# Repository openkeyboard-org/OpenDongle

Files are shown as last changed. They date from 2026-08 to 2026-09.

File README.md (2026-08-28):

# OpenDongle

OpenDongle is an open-source keyboard dongle project.

## Repository layout

- `firmware/` — firmware source and related software artifacts.
- `hardware/` — hardware design files and documentation.
- `tools/` — development and support tooling.

## Licensing

- Firmware and tools software: [Apache License 2.0](./firmware/LICENSE).
- Hardware designs: [CERN Open Hardware Licence Version 2 - Weakly Reciprocal](./hardware/LICENSE).
- Third-party firmware provenance is recorded in [firmware/NOTICE](./firmware/NOTICE),
  and the independently created antenna design's provenance is recorded in
  [hardware/NOTICE](./hardware/NOTICE).

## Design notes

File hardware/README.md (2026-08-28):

# OpenDongle Hardware

OpenDongle is a compact USB Type-A 2.4 GHz wireless receiver. This directory contains the KiCad hardware design files, project-local libraries, fabrication notes, and bill-of-materials information for each implementation.

## Implementations

| Implementation | MCU | Board size | Power | Status |
| --- | --- | --- | --- | --- |
| [CH570](CH570/) | WCH CH570Q (DFN-10) | 16.4 mm x 10.0 mm | VBUS direct to V5, internal regulator | Available |
| [CH592](CH592/) | WCH CH592D (QFN-20) | 16.35 mm x 9.90 mm | VBUS via XC6206 3.3 V LDO | Available |

Both implementations share the same concept: a PCB-edge USB Type-A connector,
an independently created 2.4 GHz PCB antenna informed by WCH's published
reference design for 0.8 mm FR-4, and a two-layer board small enough to sit
inside a standard nano-receiver shell. They differ in the MCU and therefore in
the power and decoupling arrangement.

Each implementation directory also commits its exported outputs under `fab/`: the schematic as PDF and the gerber/NC drill set. The KiCad sources are the design of record; each README gives the `kicad-cli` commands that regenerate the exports.

See each implementation's README for detailed electrical, fabrication, assembly, and licensing information.

## Shared fabrication constraints

Both boards use the same stackup and design rules, because the antenna is only tuned for this construction:

| Parameter | Requirement |
| --- | --- |
| Layer count | 2 copper layers |
| Finished thickness | 0.8 mm nominal (35 um + 0.73 mm core + 35 um) |
| Material | FR-4 |
| Copper | 1 oz / 35 um outer copper |
| Minimum finished drill | 0.20 mm |
| Minimum track / clearance used | 0.15 mm track, 0.127 mm clearance |

## Verifying a design

Both projects open with KiCad 10 or later and resolve every symbol and footprint from their own directory via `${KIPRJMOD}`, so nothing needs to be added to your global library tables.

You can check either board without opening the GUI:

```sh
kicad-cli sch erc --severity-all hardware/CH570/OpenDongle-CH570.kicad_sch
kicad-cli pcb drc --severity-all --schematic-parity hardware/CH570/OpenDongle-CH570.kicad_pcb
```

CH570 is clean. CH592 reports a single expected ERC warning, explained in its README.

## Inspiration

This hardware design was inspired by the [bplug-ch project](https://oshwhub.com/lightandelectricity/bplug-ch).

## License

The hardware designs are licensed under the CERN Open Hardware Licence Version
2 - Weakly Reciprocal. See [LICENSE](LICENSE). Design provenance, including the
independently created antenna implementation, is recorded in [NOTICE](NOTICE).

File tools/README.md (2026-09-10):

# opendongle (Rust)

Cross-platform USB-HID maintenance tool for OpenDongle dongles (WCH CH570 /
CH592F). Runs on **Linux, Windows, and macOS**, and builds to a single
executable with no runtime data files.

On Linux that executable is not fully static: `hidapi` uses the hidraw backend,
so the binary links `libudev.so.1` at run time (`ldd` will show it). Any
mainstream distribution already provides it — `libudev1` on Debian and Ubuntu,
`systemd-libs` on Fedora — but a minimal container image may not.

It reads device, firmware, bond and fault information over the dongle's vendor
HID interface, and hands the device off to the
[OpenBoot](../third_party/openboot) bootloader when you want to update it.
**It does not flash firmware itself** — updates happen inside the bootloader
over OBP, driven by the `openboot` CLI that ships with that submodule. See
[`firmware/BOOT.md`](../firmware/BOOT.md) for the boot architecture and the full
update, factory and recovery flows.

## Why hidapi

The dongle's vendor channel is a HID-class interface. `hidapi` rides each OS's
native HID stack (hidraw on Linux, `hid.dll` on Windows, IOKit on macOS), so the
interface opens on all three with no driver replacement — unlike a raw-USB
approach (libusb/nusb), which would need Zadig/WinUSB on Windows and is
impractical for a HID interface on macOS.

## Build

```bash
cargo build --release
# binary: target/release/opendongle
```

Dependencies (`hidapi`, `clap`, `anyhow`, `crc32fast`) are pulled by Cargo.

- **Linux:** the hidapi hidraw backend links `libudev`. Install the dev package
  (Debian/Ubuntu: `sudo apt install libudev-dev`). If `pkg-config` can't find it
  (e.g. a linuxbrew `pkg-config` shadows the system one), point it at the system
  dir: `PKG_CONFIG_PATH=/usr/lib/x86_64-linux-gnu/pkgconfig cargo build`.
- **Windows / macOS:** no extra system packages.

## Usage

Safe by default: with no action it displays read-only status.

```bash
opendongle                                     # same full status as --info
opendongle --info                              # device, build, update, link, bond, health
opendongle --fault                             # retained fault page only; arms/disarms nothing
opendongle --status --samples 50 --period-ms 200  # unarmed link-state sampler
opendongle --enter-bootloader --image app.bin  # family-checked, then reboots into OpenBoot
opendongle --enter-bootloader --force          # reboot with no family guard

# then, with the device enumerated as OpenBoot. The bootloader shares the
# application's VID:PID, so the openboot CLI needs both flags — its own
# defaults (1209:0001) are the generic/bench identity, not this product's.
# It tells the two modes apart by HID usage page 0xFF00 usage 0x01, which the
# application's interfaces (0xFFFF, 0xFF60) deliberately avoid.
openboot --vid 0x0C45 --pid 0xFEFE flash --force app.bin
```

**Attach one dongle at a time.** Neither this tool nor the `openboot` CLI can
pin a *physical* device across the re-enumeration into the bootloader: both
select by VID:PID (plus HID usage page), and `--serial` selects by ROM UID,
which the application and the bootloader do not present identically. With two
dongles attached, a flash could therefore target the wrong one.

`--enter-bootloader` narrows the window but does not close it. It records which
OpenBoot devices were already present before the reboot, and reports success
only when the application interface it addressed has **left** the bus *and*
exactly **one previously-absent** bootloader has appeared. It exits 2, with an
explanation, if the addressed application never left, if more than one new
bootloader appears, or — after warning — when bootloaders were already present.

If another bootloader is already on the bus it refuses **before** rebooting
anything, leaving the dongle running.

**The flash itself cannot be aimed at the wrong device**, which is worth stating
because it is easy to assume otherwise. `openboot` is not told which hidraw path
was identified — it selects by VID:PID — but it narrows by HID usage page first,
so a sibling running its *application* is filtered out, and it then refuses
outright when more than one bootloader interface matches. The failure mode with
several dongles attached is a clear error, not a misdirected write. These checks
exist so that error arrives before a working dongle has been rebooted for
nothing, not because the write is unsafe.

`--image` is the safety interlock: the image's ODG2 family is compared against
the connected device's reported family **before** the reboot, while the
application is still the thing answering, so a CH570 image cannot be sent toward
a CH592 or vice versa. It also refuses a *factory* image with a pointed error —
those are written at address 0 with a debug probe, not over USB. `--force` skips
the guard when you have no image at hand; note the flash itself is unguarded
either way, because OpenBoot's COMMIT attests only length and CRC.

Flags: `--vid` / `--pid` (accept `0x..`/decimal), `--interface`, `--hidraw`
(alias `--path`, explicit device path), `--info`, `--fault`, `--status`, `--diag`, `--rf-poke`
(`--samples N`, `--period-ms MS`), `--enter-bootloader`, `--image FILE`,
`--force`.

`--diag` reads the RF diagnostics pages (command 0x92, up to eight 62-byte
pages: 0-3 required of any firmware that answers the command, 4 present on the
current firmware of both chips but skipped if an earlier firmware answers it
with an empty payload, plus the CH592 power pages 5 "power" and 6 "power
detail" that exist only on a `PM_IDLE=1` build and are skipped the same way;
provided by firmware carrying the RF diagnostics page -- a separate draft PR;
firmware without it answers nothing and the tool reports a timeout;
firmware `RF_DiagFill` in `firmware/common/src/rf_task.c`) with unarmed
exchanges only: the runtime snapshot (state, channel, the access address in
RAM vs the one the radio was last armed with, the last RX/TX/shut status, an
`rx_armed` latch, peer MAC, last LEN-10 disposition, last persist outcome), the
PHY and executor counters (RX arm attempts and failures, RX done/CRC/timeout,
TX start/fail/done, the pending event mask, both delayed-post slots, the
timer slots' remaining times) and the protocol counters (beacons seen and
accepted or rejected with the reason, pair-ACK scheduled/started/finished,
EV10 entries and give-ups, promotes, persist attempts). Counters wrap; with
`--samples N --period-ms T` every counter that changed between samples is
printed as a per-second rate, which is how a healthy reconnect camp reads
(RX re-armed ~33/s on its 30 ms timeout) and how a deaf one is told apart
(no RX events, or a non-zero arm status, or a radio address that is not the
bond's). Every page ends with its raw bytes. CH592 firmware answers the page
with zeros for the CH570-only fields.

On a `PM_IDLE=1` CH592 build each sample after the first also prints two
derived figures. `idle_duty` is page 5 `idle_tsys` (60 MHz SysTick ticks spent
in WFE) over the `hal_now` ticks that elapsed; both are 32-bit and wrap every
71.6 s, and a wrapped numerator cannot be recovered from host time, so the duty
is exact for `--period-ms` under 60000 and prints `n/a` beyond that rather
than a silently low figure. `radio_wake_ratio` is
`wake_both / (wake_radio + wake_both)`: the firmware snapshots what is pending
right after the WFE, before any ISR runs, and `wake_radio` counts exits where a
radio IRQ was the ONLY source pending (proof that the radio ended the WFE)
while `wake_both` counts exits where another source was pending too, which the
counters cannot order (a radio IRQ that never woke the core and waited for the
next TMR3/TMR0/USB looks the same as a radio wake with a heartbeat landing in
the read window). The ratio is a co-pending frequency, not a wake-failure
rate; the radio-wake proof is the protocol around it: a keyboard-absent
negative control must read `wake_radio == wake_both == 0`, then every
reconnect/pair must advance `wake_radio`, and a radio that never ends the WFE
shows as `wake_both` advancing with `wake_radio` flat. In the exact-deadline heartbeat
mode (page 5 flag `exact_deadline`, whose `deadline_cap_us` replaces `heartbeat_us`)
page 6 also carries `hb_arm_deadline` / `hb_arm_cap`, how many sleeps armed TMR3 to an
application timer's deadline versus to the cap; `hb_irqs` then runs at tens a second
rather than a thousand when no application deadline is nearer than the cap (a nearer
deadline arms the timer sooner, and on a live link TMR0 wakes the core before it
fires). The page 6 remote-wake
arm count is 16 bits on both sides and its rate wraps accordingly.

Page 7 `rx window` (CH592 built with `PM_IDLE=1` and `PM_RX_WINDOW=1`, the Tier 2 windowed
receiver; the page count rises to 8 only with both) counts the
receiver windows the reacquire scan and the terminal camp open instead of keeping RX on:
`win_opens` / `win_closes` (a close is a window that ended with nothing accepted; whether
a window is in flight is the `open` flag, not an arithmetic on the counters, since a phase
open replaces a pending ordinary window and a teardown discards one), `win_catches` (a
beacon accepted inside a window, counted at acceptance before the ACK's own outcome), `win_phase_opens` / `win_phase_misses` (the once-per-second window
phase-locked to a resting production keyboard's probe, and how often it caught nothing; a
miss widens the next one and two in a row fall back to the continuous scan until the next
promote), `win_locks` / `win_unlocks` (the scheduled-drop detector locking on two
consecutive drops ~1 s apart after a short confirmed link, and letting go on anything
else) and `win_engages` (windowing starting once the grace period ran out). The detector
line shows the live state: `link_rx` (answered polls on the current link while connected,
saturating at 65535; the last link's count otherwise), `phase_ms` (the
current phase window width), `grace_ms` (continuous receiver remaining before windowing
engages), `misses`, `faults` (rung 3 injections inside a window) and the mode/open/
phase_open/locked flags; the rates line carries the eight 32-bit counters only, and page 7
prints no raw-byte line. Against a resting production keyboard, once the grace period has
run out and the detector has locked, the healthy reading is one phase open and one catch
per second with `win_phase_misses` flat.

Exit codes:

| Code | Meaning |
|---|---|
| `0` | ok |
| `1` | device/permission/runtime error, or a refused request |
| `2` | the handoff could not be pinned to one device. Either OpenBoot never appeared within 10 s, or the addressed application never left the bus, or more than one new bootloader appeared, or another bootloader was already present when the command started |
| `3` | `--image` was given while only the OpenBoot bootloader is on the bus, so the image's ODG2 family could **not** be checked against the device. The guard lives in the application, which is not present. Pass `--force` to proceed anyway, and note the output says plainly that the family was not verified |

`--fault` issues only the unarmed FaultRead (0x93) and decodes the 40-byte
fault page. The CH570 page v5 and the CH592 page v1 share one layout, and both
are recognised; any other (family, page version) pair is printed as a warning
plus the raw bytes, with no fields decoded. For a **valid** record every field
is shown: startup reset cause and the record's own, the startup phase marker,
the reset-keeper state live and as recorded, kind, action, flags, all four
counters and the trap registers. For an **invalid** record the firmware
populates only the family, page version, valid flag, live keeper, startup
marker and startup reset status; the record-derived fields are zero fill and
are reported as `unavailable` rather than decoded. The raw 40 bytes are always
the last line. Use `--fault` first on a misbehaving unit: it does not arm or
disarm a session (a session left armed by an interrupted earlier run stays
exactly as it was), so it perturbs the device less than `--info`.

`--status` issues a single unarmed Status (0x91) exchange per sample and prints
one line each with a timestamp, the connection state and the last RSSI. With
`--samples N` and `--period-ms MS` it repeats, which is how to watch a link
flicker between *waiting for reconnect* and *connected* without a maintenance
session ever being armed. Note the CH570 SKU is reported to return a constant
RSSI, so treat that column as a hint on that part.

`--rf-poke RUNG` is the one diagnostic that changes device state. It arms a
maintenance session (like the bond commands), sends IAP `0x94` with the rung,
and always disarms. Rung `1` re-arms the receiver from task context; rung `2`
shuts the radio, re-runs the vendor init and re-arms (CH570 only: CH592 answers
"unsupported" for it, a second vendor role init is not validated on the TMOS
radio); rung `3` shuts the radio and leaves it deaf, the fault injection for the
terminal camp's liveness watchdog, which re-arms it at its next 200 ms tick on
both chips (rung 3 resets the tick's baseline; page 1 `camp_wd_rearms` advances
by one; on CH570 the escalation to a vendor re-init needs a second silent tick).
With the CH592 receiver windowed (page 7 `mode` true) rung 3 instead marks the NEXT
window: it arms and is shut at once, so the injection lands inside a listening window
rather than on a radio that was off anyway; reception is restored in the window after the
injected one, up to about two periods from the command (page 7 `faults` advances by one),
and the link itself still needs the peer's next beacon.
Rungs `40` to `59` are the opposite kind of injection: on a live link they mask
every interrupt for a nominal `rung - 40` poll slots of 875 µs, so the polls
coalesce into one gap of about that many intervals; a nominal gap of 5 or 10
slots is the regression check for the hop repeat-correction fix (the link must
survive it). Rungs `60` to `69` add `3 * (rung - 60)` ticks of 31.25 µs to a
5-slot gap and `70` to `79` to a 6-slot gap, sweeping the remainder within the
slot. Every figure is the requested duration: the mask starts whenever the
command is dispatched, at an arbitrary phase within the current slot, so the
gap the link actually sees is the requested length plus that phase, and the
remainder rungs sweep the remainder in aggregate over repeats, not per call. The firmware
refuses rungs 1 to 3 unless the dongle is in its exact terminal reconnect camp
-- not connected, no EV10 reacquire scan, no boot window or relisten, no
pair-ACK burst in flight -- refuses rungs 40 to 79 unless a link is up, and
refuses them all while quiescing for a reboot. Exit status is non-zero on any refusal, and the reply names the
reason. Use it on a dongle that is deaf to its
keyboard, rung 1 first: which rung restores the link says whether the software
re-arm loop or the PHY was dead.

The build id `--info` prints is the one to check against the tree that built
the image: `make -C firmware ch592-print-build-id MRS_TOOLCHAIN=... <the same
knobs>` (or `ch570-print-build-id`) prints exactly the id that command line
builds, and `firmware/<chip>/build/<profile>/.build-id-stamp` holds the id the
last build actually compiled in. All three must agree; a mismatch means the
flashed image is not the configuration you think it is.

`--info` reports an absent or invalid bond record as information rather than an
error, and shows a best-effort split of the invalid record's fields (magic,
format, flags, interval, session AA, timeout, both MACs, stored vs computed
checksum) alongside the raw bytes. An all-zero bond record **may** indicate a
failed NV read - the firmware zero-initialises the reply and `bond_load` returns
without filling it on an NV error - but a record that genuinely is, or was
corrupted to, all zeros looks identical, so the tool says "may indicate" and no
more.

With `--hidraw`, `--fault` and `--status` first confirm from HID enumeration
alone that the named path carries the `--vid`/`--pid`/`--interface` selectors,
and refuse to send anything if it does not: an explicit path bypasses discovery,
so nothing else would stop a vendor report going to an unrelated HID node.

On Linux, opening the device needs hidraw permissions (run as root or use a
`plugdev`/udev rule).

## Tests

```bash
cargo test
```

60 tests, no hardware required: Intel-HEX parsing including checksum rejection,
ODG2 header integrity, the device-family binding, wrong-load-base and
factory-image rejection, bond-record and fault-record decoding and the exact
text each renders (valid, invalid/best-effort, unknown layout), status parsing
with legacy fallback, IAP packet golden vectors and transport CRC-32, the
`--hidraw` identity check, the `int(s,0)`-style number parser, and the CLI
contract.

## macOS caveat

This is a 5-interface composite HID device and the vendor channel is interface
4. On Linux/Windows hidapi reports the interface number reliably; on macOS it
can be `-1` for composite devices, in which case interface matching needs a
usage-page fallback. Verify on macOS hardware before relying on it.

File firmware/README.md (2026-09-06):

# OpenDongle production firmware

This directory builds the two supported production images:

- `make ch570` builds the CH570D RF + USB HID + IAP image.
- `make ch592` builds the CH592F RF + USB HID + IAP image.
- `make ch570-openboot` or `make ch592-openboot` builds only the OpenBoot
  bootloader from the pinned submodule (product board files).
- `make ch570-factory` / `make ch592-factory` build one raw factory image:
  OpenBoot at flash address `0x0000`, `0x00` pad to `0x2000`, then the
  finalized application at `0x2000`.
- `make` or `make all` builds both images.
- `make check-deps` verifies the pinned SDKs and toolchain; `make test` runs the
  host unit tests (no toolchain, no hardware); `make clean` removes build output.

The dongle boots via the OpenBoot bootloader (`third_party/openboot`,
pinned submodule) and updates in-bootloader over its OBP USB protocol. See
[BOOT.md](BOOT.md) for the flash maps, boot-record semantics, and the
update/factory/recovery flows; OpenBoot's own design and wire protocol are
documented in the submodule.

## CH570D factory flashing

The single image produced by `make ch570-factory` is:

```text
ch570/build/ch570-product/opendongle-ch570-product-factory.bin
```

It is a raw code-flash image based at address zero. To build and program it
through the debug pin with a WCH-LinkE and `minichlink`, run:

```sh
make ch570-factory-flash \
  MINICHLINK=/path/to/minichlink \
  WCHLINK_SERIAL=probe-serial
```

`WCHLINK_SERIAL` is **required**: the target refuses to guess which probe to
drive, because a whole-chip erase aimed at the wrong target is unrecoverable and
a multi-probe bench may carry boards that must never be written. **Use the make target rather than raw `minichlink` calls.** minichlink ignores
the return values of its CH5xx erase and write calls and its byte-for-byte
verify is disabled, so a zero exit status alone does not prove the image
landed. The target exists because it does the two things a hand-typed sequence
does not: it selects the probe explicitly, and it reads the image back and
byte-compares it before reporting success.

What it does, and why each step matters:

1. `-kt` turns off the WCH-LinkE target supply.
2. `-E` erases the entire user code flash. **The erase is required, not
   optional.** It clears the bond page (`0x3A000`) so a unit cannot inherit a
   test fixture's pairing identity. It also clears both slots' boot records,
   which now live inside the slots (`0x1D000` and `0x39000` on CH570) rather
   than on a reserved page — but that no longer decides where the first boot
   lands, because the factory image carries slot A's record and restores it.
3. The factory image is written at address 0, read back, and compared.
4. On CH592 only, the recipe additionally refuses to finish if a bond record
   survived in DataFlash, which `-E` cannot reach (`ALLOW_BONDED_FLASH=1`
   overrides this for a development unit).

No bless step is needed, or possible: the factory image carries slot A's boot
record, so the unit boots the application on first power-on (see BOOT.md).
The recipe ends with a real power cycle rather than `minichlink -b`, so what it
leaves behind is a unit that has actually demonstrated that.

For a target placed in the WCH ROM USB bootloader instead of using the debug
pin, the same raw image can be programmed with:

```sh
wchisp erase
wchisp flash \
  ch570/build/ch570-product/opendongle-ch570-product-factory.bin
```

The explicit `wchisp erase` matters for the same reason it does above:
`wchisp flash` erases only enough sectors to hold the image, so it would leave
the old boot-record page behind. Erasing makes the post-flash state
deterministic instead of dependent on whatever the unit held before.

Be precise about what a surviving record does and does not guarantee. It stores
a length and a CRC-32, and the bootloader recomputes that CRC over exactly that
many bytes from the app base — so it validates any image whose first `img_len`
bytes match the recorded ones, which in practice means re-flashing the same
build. It is not a whole-image identity check, and it does not by itself
guarantee the unit cannot launch an image other than the recorded one. Anything
that does not match that prefix fails the check and the unit stays in the
bootloader. `BOOT.md` states the rule in full.

The factory target enforces two invariants before exposing the image: the
application fits its chip's `APP_MAX_BYTES` window (`size-check`), and the
OpenBoot binary fits `[0, 0x2000)` so the application lands at exactly the
address it links at (`compose_factory.py`). The application's own ODG2 header is
written earlier, by `finalize_image.py` during the app build.

Two independent checksums are in play, and it is worth not confusing them.
`finalize_image.py` stamps a CRC inside the ODG2 header; that is a host-side
identity check, used by `opendongle` and by the build. OpenBoot never parses
ODG2. What it verifies at every boot is its own `img_crc32`, computed over the
committed bytes at COMMIT time and stored in that slot's `OBR2` boot record. A
raw OBP client can therefore bless and boot an image whose ODG2 CRC is invalid —
consistent with wrong-family protection also being host-side only (see
`BOOT.md`).

## Dependencies

The OpenWCH CH570/CH572 and CH592 SDKs are pinned Git submodules. Initialize
them once from the repository root:

```sh
git submodule update --init --recursive
```

MounRiver Studio's GCC 15.2 toolchain is an external dependency. It is not
redistributed or made a submodule because its packaging and licence are
independent of the OpenWCH SDK repositories. Set `MRS_TOOLCHAIN` to the
directory containing `riscv32-wch-elf-gcc`, `riscv32-wch-elf-objcopy`,
`riscv32-wch-elf-size`, and `riscv32-wch-elf-nm`.

**Two toolchains are required.** The default goal composes the factory image,
which builds OpenBoot — and OpenBoot is a pinned submodule still on GCC 12. So
a working build names both:

```sh
make MRS_TOOLCHAIN=/path/to/MounRiver_Studio/toolchain/RISC-V_Embedded_GCC15/bin \
     OPENBOOT_TOOLCHAIN=/path/to/MounRiver_Studio/toolchain/RISC-V_Embedded_GCC12/bin
```

`OPENBOOT_TOOLCHAIN` defaults to `MRS_TOOLCHAIN`, and omitting it now fails in
**our** `check-openboot-toolchain`, not OpenBoot's. Upstream's compiler check
went advisory at this pin — a hash mismatch and an unvalidated GCC major both
warn and continue — and it auto-detects either tool prefix, so a factory build
carrying one GCC 15 toolchain would otherwise silently ship a GCC 15
bootloader. If you only want the application binaries and no bootloader, the
per-chip `.elf`/`.bin` targets need `MRS_TOOLCHAIN` alone.

**The split is permanent**, not a wait for OpenBoot's pin to catch up: GCC 15
is explicitly unvalidated on ch57x. Upstream benched a CH572 where it fired the
idle auto-boot at 1.51/1.71/4.75 s against a configured 10 s and failed to
return from 4 of 32 software resets (GCC 12: 0/32), with the generated code for
the timing functions instruction-identical. Cause unresolved.
`OPENBOOT_ALLOW_UNVALIDATED_GCC=1` overrides the gate for anyone reproducing
that investigation.

**Note the tool prefix changed with this release.** GCC 12 shipped
`riscv-wch-elf-*`; GCC 15 ships `riscv32-wch-elf-*`. Pointing `MRS_TOOLCHAIN` at
a GCC 12 directory now fails in `check-deps` with "MounRiver tool is missing or
not executable", which is the intended behaviour rather than a broken build
part-way through. The prefix lives in the `CROSS` variable in each application
Makefile and in `firmware/Makefile`, and `check_dependencies.py` validates the
same prefix it is given, so overriding `CROSS` also moves what gets validated.

OpenBoot is the exception and still needs GCC 12 — see the `OPENBOOT_TOOLCHAIN`
note above.

`MRS_TOOLCHAIN`, `OPENWCH_ROOT`, `CH570_SDK`, and `CH592_SDK` use Make's `?=`
assignment, so they may be supplied by the environment, command line, or a
developer-local make wrapper. `make check-deps` verifies the SDK revisions,
clean SDK worktrees, the compiler's GCC major, its support for WCH's
fast-interrupt ABI, and the required tools before compilation.

### The compiler gate: properties, not bytes

`check_dependencies.py` is an order-only prerequisite of every object file, so
it is not advisory: a failure stops the build. It gates on three properties of
the compiler the build will actually use (the `CROSS` prefix under
`MRS_TOOLCHAIN`):

- the tools exist (`gcc`, `objcopy`, `size`, `nm`);
- the driver reports the required GCC **major** (15 for the application;
  OpenBoot keeps its own GCC 12 gate, see `OPENBOOT_TOOLCHAIN` above);
- the driver **implements `__attribute__((interrupt("WCH-Interrupt-fast")))`**,
  checked on the generated code rather than on the spelling: a fast handler lets
  the hardware preserve `ra`/`t0`/`a0` and spills only the callee-saved `s0`
  before `mret`, the ordinary `interrupt` ABI spills all four, and the probe
  compiles both and refuses a compiler that emits the ordinary shape for the
  fast attribute or the same shape for both. Each chip Makefile passes its own
  `$(ARCH)` as the probe target (`--probe-flags`), and the top-level
  `make check-deps` delegates to the chip Makefiles so it probes the same way;
  a bare invocation of the script without `--probe-flags` probes a generic
  `rv32imac`. That is the property the firmware depends on: the CH59x BLE library is
  compiled against WCH's fast-interrupt ABI, mainline GCC and clang reject the
  argument outright, and a plain-interrupt build wedges before any IRQ is
  delivered.

The compiler's identity is still part of the build id. Each chip Makefile folds
the driver's first `--version` line (name, WCH build tag, version, e.g.
`riscv32-wch-elf-gcc (g5115c7e44-dirty) 15.2.0`) into `CONFIG_TEXT` as the
`compiler=` token (a sanitised readable prefix plus 16 hex digits of the line's
SHA-256, so two compiler builds whose tags sanitise alike still get different
ids) and the driver's own SHA-256 as `compiler_sha256=`, so a driver whose bytes
changed under an unchanged banner also moves the id and recompiles every object.
A compiler that prints no identity fails any goal that compiles the application
at Makefile parse time, rather than producing an id; `clean`, the OpenBoot-only
targets and `check-deps` are exempt from that parse-time guard so they can run
on a checkout without an application compiler (`check-deps` itself then reports
the missing or wrong toolchain, which is its job). `check-deps` prints the driver's SHA-256 for the build log, and
the factory rule appends `app_compiler`, `app_compiler_id`,
`app_compiler_sha256` and `app_build_id` to the factory manifest, which is where
the strict mode's digest comes from.

What the id therefore means: **same source, same configuration, same compiler
identity line and driver bytes.** It does not by itself promise byte-identical
binaries across hosts; two installs with the same driver that differ in `cc1`,
the assembler or the linker would share an id. Anyone who needs that stronger
promise passes `--expect-compiler-sha256 <digest>` (the `app_compiler_sha256`
line of a release's factory manifest) to `check_dependencies.py`, which turns
the digest back into a hard gate for that build. Even then it is driver
verification, not a byte-reproducibility guarantee: `cc1`, the assembler, the
linker and `objcopy` are not covered.

History: until this change the gate was an exact SHA-256 of the gcc driver,
which blocked every host whose MounRiver drop differed from the one that
recorded the pin, even at the same 15.2.0 version, and forced a local override
that could never be committed.

## Verifying a build

The build is reproducible: `build_identity.py` hashes the sources, the linker
script, the compiler and linker flag sets, the pinned SDK revision and the
compiler's identity into a 32-bit build id that is compiled into the image and reported by
the host tool (`opendongle --info`). Two builds of the same tree on the same
host produce byte-identical artifacts, so a rebuild-and-compare is a meaningful
check:

```sh
make ch592 MRS_TOOLCHAIN=...
sha256sum ch592/build/ch592-product/opendongle-ch592-product.bin
make clean && make ch592 MRS_TOOLCHAIN=...
sha256sum ch592/build/ch592-product/opendongle-ch592-product.bin   # identical
```

**What that check does and does not establish.** It compares the *application*
image, and it is only as strong as the inputs the build id actually covers. Two
gaps are worth stating rather than leaving implied, both documented above and in
`TODO.md`:

- The compiler gate checks the `riscv32-wch-elf-gcc` driver's properties; the
  driver's identity line and digest are folded into the build id and recorded
  in the factory manifest, never gated by default, and even the strict
  `--expect-compiler-sha256` mode verifies the driver alone, not `cc1`, the
  assembler, the linker or `objcopy`. A partially replaced toolchain directory
  can therefore produce different bytes under the same build id, so "the same
  toolchain" means the whole directory unchanged, not merely a matching
  identity line or driver digest.
- **OpenBoot still builds with GCC12.** The pinned submodule carries its own
  toolchain pin, still on MounRiver GCC12 and its `riscv-wch-elf-*` tool names,
  so a factory build needs both toolchains present:

  ```sh
  make ch570-factory MRS_TOOLCHAIN=<GCC15 bin> OPENBOOT_TOOLCHAIN=<GCC12 bin>
  ```

  This is safe rather than merely tolerated: the factory image is
  OpenBoot ‖ pad ‖ application, two separately linked binaries that share no
  code, so the compilers never have to agree. `OPENBOOT_TOOLCHAIN` defaults to
  `MRS_TOOLCHAIN`, and a factory build with it pointed at anything but GCC 12
  is refused by `check-openboot-toolchain`. The split is permanent, not a wait
  for OpenBoot's pin to move.
- The OpenBoot **revision** is in `CONFIG_TEXT`, and `check-deps` asserts the
  checkout matches it and is clean (`--expect-revision`). The bootloader
  **binary** is still not hashed into `BUILD_ID_INPUTS`, deliberately: the
  manifest does not exist at parse time on a clean checkout, and its digest
  depends on which GCC 12 install built OpenBoot, which would make
  `DONGLE_BUILD_ID` differ between developers for byte-identical application
  images.
- So the two identities are separate on purpose: `DONGLE_BUILD_ID` identifies
  the **application**, and the `.manifest` copied beside each factory image
  (`openboot_revision`, `openboot_dirty`, `image_sha256`) identifies the
  **bootloader artifact**. Comparing factory images across hosts means
  comparing both.

So: same tree, same complete toolchain, same OpenBoot checkout → identical
artifacts. A matching build id alone does not imply a matching factory image;
the manifest is what closes that gap.

`make clean` removes generated output for both production targets.

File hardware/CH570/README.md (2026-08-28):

# OpenDongle CH570

OpenDongle CH570 is a compact USB Type-A 2.4 GHz receiver built around the WCH CH570Q RISC-V wireless MCU. The PCB is 16.4 mm x 10.0 mm and uses a PCB-edge USB connector and an independently created, WCH-informed 2.4 GHz PCB antenna.

## Design files

| File or directory | Purpose |
| --- | --- |
| `OpenDongle-CH570.kicad_pro` | KiCad 10 project and design-rule settings |
| `OpenDongle-CH570.kicad_sch` | Schematic |
| `OpenDongle-CH570.kicad_pcb` | PCB layout |
| `lib/OpenDongle.kicad_sym` | Project-owned CH570Q and four-pin PCB USB symbols |
| `lib/OpenDongle.pretty/` | Project-owned USB edge connector and independently created, WCH-informed antenna footprints |
| `sym-lib-table`, `fp-lib-table` | Portable project-local library configuration |
| `fab/` | Exported outputs: schematic PDF and gerber/NC drill set (see [Fabrication outputs](#fabrication-outputs)) |

Open the project with KiCad 10 or later. The library tables use `${KIPRJMOD}` paths, so the project resolves every symbol and footprint from this directory and does not depend on global KiCad configuration. Nothing needs to be added to your global symbol or footprint library tables.

## Electrical design notes

- USB VBUS supplies the CH570Q V5 pin (pin 2) directly. There is no external regulator; the CH570 regulates 3.3 V internally.
- R1 is the 1.5 kOhm connection required by WCH between V5 and the internally regulated VDD33/VIO33 rail (pin 1) for direct 5 V operation.
- Both V5 and VDD33/VIO33 have 2.2 uF bulk and 100 nF high-frequency decoupling: C1/C2 on V5, C3/C4 on VDD33.
- Y1 is a 32 MHz, 8 pF-load crystal on XI/XO (pins 9 and 8). The CH570 provides programmable internal crystal load capacitance, so external load capacitors are not fitted.
- The RF output (ANT, pin 10) connects directly to the independently created, WCH-informed PCB antenna, as recommended by the CH570 datasheet.
- USB data connects to the CH570Q native USB pins: D+ to PA1/UDP (pin 4) and D- to PA0/UDM (pin 3).
- GND reaches the CH570Q through the exposed pad (pin 11).
- The three unused GPIOs (pins 5, 6, 7) carry no-connect flags.
- AE2 and J1 represent copper footprints fabricated as part of the PCB. They are excluded from the assembly BOM and position file at both the symbol level (`in_bom no`, `in_pos_files no`) and the footprint level (`exclude_from_bom`, `exclude_from_pos_files`), so they do not appear in the Fabrication Toolkit output as unsourceable line items.

See the [WCH CH572/CH570 datasheet](https://www.wch-ic.com/downloads/CH572DS1_PDF.html) for the power, oscillator, RF, USB, and package requirements.

## Design verification

This design passes both checks cleanly with KiCad 10:

```sh
kicad-cli sch erc --severity-all OpenDongle-CH570.kicad_sch     # 0 errors, 0 warnings
kicad-cli pcb drc --severity-all --schematic-parity OpenDongle-CH570.kicad_pcb   # 0 violations, 0 parity issues
```

## Fabrication outputs

`fab/` holds the exported outputs: the schematic as PDF, and the gerber/NC
drill set under `fab/gerbers/`. The KiCad sources remain the design of
record — regenerate the exports with KiCad 10 whenever the schematic or
layout changes:

```sh
kicad-cli sch export pdf -o fab/OpenDongle-CH570-schematic.pdf OpenDongle-CH570.kicad_sch
kicad-cli pcb export gerbers -o fab/gerbers/ \
    -l F.Cu,B.Cu,F.Paste,B.Paste,F.Silkscreen,B.Silkscreen,F.Mask,B.Mask,Edge.Cuts \
    --no-protel-ext --check-zones OpenDongle-CH570.kicad_pcb
kicad-cli pcb export drill -o fab/gerbers/ --excellon-separate-th \
    --generate-map --map-format gerberx2 OpenDongle-CH570.kicad_pcb
```

Anyone ordering from these files must still pass the stackup and antenna
requirements below to the fabricator; the gerbers alone do not carry them.
(JLC-oriented assembly outputs from the Fabrication Toolkit plugin go to
`production/`, which stays untracked.)

## Fabrication requirements

The antenna geometry and USB connector make the board construction part of the electrical and mechanical design. Use these settings unless a revised PCB has been validated:

| Parameter | Requirement |
| --- | --- |
| Layer count | 2 copper layers |
| Finished board size | 16.4 mm x 10.0 mm |
| Finished thickness | 0.8 mm nominal (35 um + 0.73 mm core + 35 um) |
| Material | FR-4 |
| Copper | 1 oz / 35 um outer copper |
| Surface finish | ENIG recommended; hard gold on the USB contacts is preferred for high insertion-cycle production |
| Minimum finished drill | 0.20 mm |
| Minimum track/space used | 0.15 mm track, 0.127 mm design-rule clearance minimum |
| Soldermask | Both sides; no soldermask over the USB contacts or antenna conductor |

Additional requirements and checks:

1. Preserve the antenna copper, ground keepout, board thickness, and via fence exactly. The antenna is designed for 0.8 mm FR-4; a different thickness detunes it. Do not allow the fabricator to add serial numbers, tooling features, or anything else in the antenna region.
2. Keep the board outline and USB contact geometry at 1:1 scale. If an edge bevel is requested, confirm that the fabricator supports it on a 0.8 mm board without shortening or damaging the USB contacts.
3. Verify the board USB contact fits in several Type-A receptacles before a production run.
4. The enclosure and carrier must not place metal or conductive material over the antenna region.

## USB receiver shell

This [USB receiver shell](https://item.taobao.com/item.htm?id=1042083494471) has been verified to fit and work well with the PCB. Other shells designed for the same PCB dimensions and specification should also work, but their fit has not been verified.

## Suggested BOM

The listed LCSC/JLCPCB numbers are suggested assembly parts, not sole-source requirements. Substitutes should match the value, package, dielectric/tolerance, voltage rating, and crystal parameters.

| References | Qty | Value / part | Package | Suggested LCSC part | Notes |
| --- | ---: | --- | --- | --- | --- |
| U1 | 1 | WCH CH570Q | DFN-10, 3 mm x 3 mm, exposed pad | C49260680 | Confirm pin-1 orientation and exposed-pad soldering |
| Y1 | 1 | 32 MHz crystal | 2016, 4 pad | C37635332 | 8 pF load, +/-10 ppm tolerance, 40 ohm maximum ESR |
| R1 | 1 | 1.5 kOhm, 1% | 0603 | C22843 | Required V5-to-VDD33 connection |
| C1, C3 | 2 | 2.2 uF | 0603 | C23630 | X5R or better, 10 V minimum; suggested part is 16 V |
| C2, C4 | 2 | 100 nF | 0603 | C14663 | X7R or better, 10 V minimum |

AE2 (PCB antenna) and J1 (PCB USB connector) are fabricated as PCB copper and are not assembly parts.

## Source attribution

- The 0.8 mm FR-4 antenna was independently created, informed by the WCH reference antenna published in the [openwch schematic/PCB library](https://github.com/openwch/schpcb_lib); no WCH CAD or artwork file was copied, imported, converted, or traced.
- The PCB USB connector footprint is derived from the [USB armory](https://github.com/usbarmory/usbarmory) hardware design.

## License

This hardware design, including the independently created antenna
implementation described in [`../NOTICE`](../NOTICE), is licensed under the
CERN Open Hardware Licence Version 2 - Weakly Reciprocal. See
[`LICENSE`](LICENSE).

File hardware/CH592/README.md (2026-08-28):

# OpenDongle CH592

OpenDongle CH592 is a compact USB Type-A 2.4 GHz receiver built around the WCH CH592D RISC-V wireless MCU. The PCB is 16.35 mm x 9.90 mm and uses a PCB-edge USB connector and an independently created, WCH-informed 2.4 GHz PCB antenna.

Unlike the [CH570](../CH570/) implementation, which runs the MCU straight from VBUS on its internal regulator, the CH592 is powered from a 3.3 V LDO.

## Design files

| File or directory | Purpose |
| --- | --- |
| `OpenDongle-CH592.kicad_pro` | KiCad 10 project and design-rule settings |
| `OpenDongle-CH592.kicad_sch` | Schematic |
| `OpenDongle-CH592.kicad_pcb` | PCB layout |
| `lib/OpenDongle.kicad_sym` | Project-owned CH592D and four-pin PCB USB symbols |
| `lib/OpenDongle.pretty/` | Project-owned USB edge connector and independently created, WCH-informed antenna footprints |
| `sym-lib-table`, `fp-lib-table` | Portable project-local library configuration |
| `fab/` | Exported outputs: schematic PDF and gerber/NC drill set (see [Fabrication outputs](#fabrication-outputs)) |

Open the project with KiCad 10 or later. The library tables use `${KIPRJMOD}` paths, so the project resolves every symbol and footprint from this directory and does not depend on global KiCad configuration. Nothing needs to be added to your global symbol or footprint library tables.

## Electrical design notes

- USB VBUS (5 V) feeds U2, an XC6206P332MR-G LDO, whose 3.3 V output supplies the CH592D VIO33/VDD33 pin (pin 5). C1 (1 uF) is the LDO input capacitor and C2 (1 uF) is its output capacitor.
- Y1 is a 32 MHz crystal on X32MI/X32MO (pins 13 and 12). No external load capacitors are fitted; the design relies on the CH592 programmable internal crystal load capacitance.
- The RF output (ANT, pin 15) connects directly to the independently created, WCH-informed PCB antenna.
- USB data connects to the CH592D native USB pins: D+ to PB11/UD+ (pin 10) and D- to PB10/UD- (pin 11).
- GND reaches the CH592D through the exposed pad (pin 21).
- The nine unused GPIOs (pins 1, 2, 7, 8, 9, 17, 18, 19, 20) carry no-connect flags.
- AE2 and J1 represent copper footprints fabricated as part of the PCB. They are excluded from the assembly BOM and position file at both the symbol level (`in_bom no`, `in_pos_files no`) and the footprint level (`exclude_from_bom`, `exclude_from_pos_files`), so they do not appear in the Fabrication Toolkit output as unsourceable line items.

### The internal DC-DC is deliberately not used

Two parts of this schematic look like mistakes and are not. **Do not "fix" them.**

**VSW (pin 4) is tied directly to VDCID (pin 3), with VDCIA (pin 16) on the same net, and there is no inductor on the board.** This is the configuration the datasheet specifies when the DC-DC converter is disabled.

VSW is the internal power path from VDD33 when the DC-DC is bypassed, so it must **not** be left floating. The decoupling values follow the datasheet's DC-DC-disabled recommendations:

| Pin | Datasheet, DC-DC disabled | This design |
| --- | --- | --- |
| VDCID (3) | "0.1uF or more" | C4, 1 uF |
| VINTA (14) | "0.47uF is recommended" | C5, 470 nF |
| VDD33 (5) | "1uF is recommended" | C2, 1 uF |

The DC-DC is off by default at power-on and is simply never enabled in firmware. WCH's own CH592F reference designs use the *other* branch of this note (a 10 uH inductor from VSW to VDCID), which is why they look different.

### PB15 (pin 6) is tied to GND on purpose

**PB15/TCK/MISO_/SCL is a boot strap, not a stray ground.** Holding it low forces a unflashed part to come up in ISP mode so it can be programmed over USB. The first programming pass flashes the firmware *and* moves the boot source to the alternate boot pin, which is shared with the USB line; after that, the ground on PB15 is inert.

This also gives the board a recovery path: a fully erased part falls back to the PB15 strap and always re-enters ISP.

Consequences to keep in mind:

- Firmware must never configure PB15 as a push-pull output. Driving it high would short it to ground.
- PB15 is also TCK, so the two-wire debug interface is not usable while the strap is fitted.

This strap is the sole remaining ERC warning; see [Design verification](#design-verification) below.

See the [WCH CH592 datasheet](https://github.com/openwch/ch592/blob/main/Datasheet/CH592DS1_EN.PDF) for the power, oscillator, RF, USB, and package requirements.

## Design verification

```sh
kicad-cli sch erc --severity-all OpenDongle-CH592.kicad_sch     # 0 errors, 1 expected warning
kicad-cli pcb drc --severity-all --schematic-parity OpenDongle-CH592.kicad_pcb   # 0 violations, 0 parity issues
```

The single ERC warning is expected and understood:

```
[pin_to_pin]: Pins of type Bidirectional and Power output are connected
    Symbol U3 Pin 6 [PB15/TCK/MISO_/SCL, Bidirectional]
    Symbol #FLG02 Pin 1 [Power output]
```

This is the PB15 boot strap sitting on the GND net, described above. It is not a defect. Fitting the pull-down resistor proposed under [Known issues](#known-issues-and-next-revision) removes PB15 from the GND net and clears the warning.

## Fabrication outputs

`fab/` holds the exported outputs: the schematic as PDF, and the gerber/NC
drill set under `fab/gerbers/`. The KiCad sources remain the design of
record — regenerate the exports with KiCad 10 whenever the schematic or
layout changes:

```sh
kicad-cli sch export pdf -o fab/OpenDongle-CH592-schematic.pdf OpenDongle-CH592.kicad_sch
kicad-cli pcb export gerbers -o fab/gerbers/ \
    -l F.Cu,B.Cu,F.Paste,B.Paste,F.Silkscreen,B.Silkscreen,F.Mask,B.Mask,Edge.Cuts \
    --no-protel-ext --check-zones OpenDongle-CH592.kicad_pcb
kicad-cli pcb export drill -o fab/gerbers/ --excellon-separate-th \
    --generate-map --map-format gerberx2 OpenDongle-CH592.kicad_pcb
```

Anyone ordering from these files must still pass the stackup and antenna
requirements below to the fabricator; the gerbers alone do not carry them.
(JLC-oriented assembly outputs from the Fabrication Toolkit plugin go to
`production/`, which stays untracked.)

## Fabrication requirements

The antenna geometry and USB connector make the board construction part of the electrical and mechanical design. Use these settings unless a revised PCB has been validated:

| Parameter | Requirement |
| --- | --- |
| Layer count | 2 copper layers |
| Finished board size | 16.35 mm x 9.90 mm |
| Finished thickness | 0.8 mm nominal (35 um + 0.73 mm core + 35 um) |
| Material | FR-4 |
| Copper | 1 oz / 35 um outer copper |
| Surface finish | ENIG recommended; hard gold on the USB contacts is preferred for high insertion-cycle production |
| Minimum finished drill | 0.20 mm |
| Minimum track/space used | 0.15 mm track, 0.127 mm design-rule clearance minimum |
| Soldermask | Both sides; no soldermask over the USB contacts or antenna conductor |

Additional requirements and checks:

1. Preserve the antenna copper, ground keepout, board thickness, and via fence exactly. The antenna is designed for 0.8 mm FR-4; a different thickness detunes it. Do not allow the fabricator to add serial numbers, tooling features, or anything else in the antenna region.
2. Keep the board outline and USB contact geometry at 1:1 scale. If an edge bevel is requested, confirm that the fabricator supports it on a 0.8 mm board without shortening or damaging the USB contacts.
3. Verify the board USB contact fits in several Type-A receptacles before a production run.
4. The enclosure and carrier must not place metal or conductive material over the antenna region.

## USB receiver shell

This board is 0.05 mm narrower and 0.1 mm shorter than the CH570, so the same [USB receiver shell](https://item.taobao.com/item.htm?id=1042083494471) that was verified against the CH570 is the intended enclosure. Its fit has been verified on the CH570 but not yet on this board. Other shells designed for the same PCB dimensions and specification should also work.

## Suggested BOM

The listed LCSC/JLCPCB numbers are suggested assembly parts, not sole-source requirements. Substitutes should match the value, package, dielectric/tolerance, voltage rating, and crystal parameters.

| References | Qty | Value / part | Package | Suggested LCSC part | Notes |
| --- | ---: | --- | --- | --- | --- |
| U3 | 1 | WCH CH592D | QFN-20, 3 mm x 3 mm, exposed pad | C41417128 | Confirm pin-1 orientation and exposed-pad soldering |
| U2 | 1 | XC6206P332MR-G, 3.3 V LDO | SOT-23-3 | C5446 | |
| Y1 | 1 | 32 MHz crystal | 3225, 4 pad | C7294588 | No external load capacitors fitted; confirm the part's load capacitance matches what firmware programs into the internal load caps |
| C1, C2, C4 | 3 | 1 uF | 0603 | C15849 | X5R or better, 10 V minimum |
| C5 | 1 | 470 nF | 0603 | C47339 | Alternate: C1623 |

AE2 (PCB antenna) and J1 (PCB USB connector) are fabricated as PCB copper and are not assembly parts.

## Known issues and next revision

Neither of these prevents the current board from being built, but both should be addressed in the next spin.

### Strap PB15 through a 4.7 kOhm pull-down

The strap is currently a direct connection to GND. Fitting a resistor between PB15 and GND instead would preserve the ISP behaviour while removing the short if firmware ever drives the pin high.

**Use 4.7 kOhm, 0603, 1% (suggested LCSC C23162).** The boot ROM's internal pull-up sources up to 90 uA (IUP max, datasheet Table 20-2) and VIL is 0.9 V max, so:

| Pull-down | Worst-case V(PB15) | Margin to VIL | Current if driven high |
| --- | --- | --- | --- |
| 10 kOhm | 0.90 V | **none - exactly at the limit** | 0.33 mA |
| **4.7 kOhm** | **0.42 V** | **2.1x** | **0.70 mA** |
| 3.3 kOhm | 0.30 V | 3.0x | 1.0 mA |

Adopting this also clears the remaining ERC warning, because PB15 leaves the GND net. The cost is placement: the 0603 has to fit near U3 pin 6 without intruding on the antenna keepout, on an already tight board.

### Close the reference designator gaps

The designators are non-contiguous: there is no **C3** and no **U1** (the parts jump from U2 to U3). This is cosmetic, but it makes the BOM harder to review and invites the question of whether a part was lost. Renumber on the next spin.

## Source attribution

- The 0.8 mm FR-4 antenna was independently created, informed by the WCH reference antenna published in the [openwch schematic/PCB library](https://github.com/openwch/schpcb_lib); no WCH CAD or artwork file was copied, imported, converted, or traced.
- The PCB USB connector footprint is derived from the [USB armory](https://github.com/usbarmory/usbarmory) hardware design.

## License

This hardware design, including the independently created antenna
implementation described in [`../NOTICE`](../NOTICE), is licensed under the
CERN Open Hardware Licence Version 2 - Weakly Reciprocal. See
[`LICENSE`](LICENSE).

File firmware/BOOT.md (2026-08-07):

# Boot architecture: OpenBoot

The dongle boots via [OpenBoot](../third_party/openboot) (pinned submodule),
replacing the in-house stage-1 and its staged update path. OpenBoot's own
design and wire protocol are documented in the submodule
(`docs/ARCHITECTURE.md`, `docs/PROTOCOL.md`); this file covers what is
OpenDongle-specific.

## Flash and RAM map

OpenBoot splits the application region into two A/B slots. Each slot's 32-byte
`OBR2` boot record occupies the **top erase block of its own slot**, so the
usable image is one block less than the slot.

| | CH592 | CH570 |
|---|---|---|
| OpenBoot (USB transport) | `0x00000–0x01FFF` | `0x00000–0x01FFF` |
| Slot A application | `0x02000–0x37FFF` | `0x02000–0x1CFFF` |
| Slot A `OBR2` record | `0x38000–0x38FFF` | `0x1D000–0x1DFFF` |
| Slot B (unused in Phase 1) | `0x39000–0x6FFFF` | `0x1E000–0x39FFF` |
| Usable image per slot | `0x36000` (216 KiB) | `0x1B000` (108 KiB) |
| Bond store | DataFlash logical `0x5000` (phys `0x75000`) | code flash `0x3A000` |
| App RAM top (`_eusrstack`) | `0x200067F0` | `0x20002FF0` |

The 16 bytes above the RAM top are OpenBoot's boot-request word (the app's
`openboot_request_update()` writes the magic there and resets). Both link.ld
files carry ASSERTs pinning the stack top; the ODG2 identity header stays at
image offset `0x20` with `base = 0x2000`.

The CH570 board file clamps OpenBoot's `OB_APP_END` to `0x3A000`, so no OBP
erase/write/commit can reach the bond. Confirmed on silicon: `openboot probe`
on a **blank** CH570 reports `app region 0x00002000..0x0003A000`,
`slots 2 (active none, writing A)` and `write window 0x00002000..0x0001D000`.
Once a factory image has installed slot A's record the device comes up
`active=A, writing=B` and the window moves to `0x0001E000..0x00039000` — the
window always describes the slot being written, not the one running.
`0x3B000` no longer holds anything —
OpenBoot reclaimed its old reserved record page when records moved into the
slots, and our clamp keeps OBP off it anyway.

**CH592 DataFlash is entirely the application's again.** The boot record used
to live at logical `0x7000` and no longer does. One consequence inverts: on
CH592 `minichlink -E` now *does* clear boot state, because the record is in
code flash. The bond at logical `0x5000` still survives `-E`, which is why
`flash-factory` keeps its `ALLOW_BONDED_FLASH` guard.

## Boot decision and the record

OpenBoot launches the app only under a valid `OBR2` record, and our boards set
`OB_BOOT_IMAGE_CRC=1`: the whole image is CRC-checked at every boot (ms-scale;
the CRC runs after clock init at 60/100 MHz).

**Factory images are self-blessing.** `make ch5xx-factory` delegates to
OpenBoot's `factory` target with `FACTORY_BLESS=1`, which composes slot A's
record into the image. A blank part programmed with it boots the application on
**first power-on** — no host, no `openboot bless`. The images are
`0x2000 + capacity + 32` bytes exactly: 118,816 (CH570) and 229,408 (CH592),
and the recipe asserts that size, because an unblessed image is byte-plausible
and would only be discovered when a unit failed to start.

`openboot bless` is not merely unnecessary now — on a blessed unit it is
**impossible**. The device comes up `active=A, write=B`, and `bless` resolves
against the *write* slot, so a slot-A image is refused there by design.

What the boot CRC proves is narrower than it looks: the record stores a length
and a CRC-32, and the bootloader recomputes that CRC over exactly that many
bytes from the slot base. Treat it as protection against accidental corruption,
not as an identity check. Never write CH592 DataFlash over SWD — bench-proven
to corrupt it.

**Finish an SWD factory flash with a real power cycle, not `minichlink -b`.**
`-b` reboots out of halt: it resumes the core rather than resetting through the
boot path, so the boot decision never re-runs from a cold start. That matters
most on CH57x, where errata F26 lets the XIP view serve stale data after a
controller write within the same power cycle — which is exactly why OpenBoot's
own BOOT command resets rather than jumping.

Established by controlled comparison on a bench CH570 — same part, same
application bytes, same SWD write and readback, same subsequent move to USB,
with only the recipe's final step differing:

| recipe ends with | result on USB |
|---|---|
| `minichlink -b` | nothing enumerates at all — neither application nor bootloader |
| `-kt` then `-k3` | application enumerates and runs (`last reset: external`) |

`flash-factory` now ends with the power cycle on both chips.

## Update flow

```sh
opendongle --enter-bootloader --image <slot-a>.bin              # family-guarded reboot
openboot --vid 0x0C45 --pid 0xFEFE flash <chip>-product.obb --force
```

Flash the **bundle**, not a bare `.bin` — see "Updating: use the bundle" below
for why. `--image` still takes a plain `.bin`: it is read host-side for the
family guard and never flashed.

`--enter-bootloader` checks the image's ODG2 family against the device before
rebooting. The firmware side (IAP command 0x85, armed session +
`OB_BOOTREQ_MAGIC` payload) quiesces RF, drains the final reply, masks IRQs,
and takes OpenBoot's safe-access reset. The bond survives updates: OBP writes
only the app region.

**Wrong-family protection is host-side only.** OpenBoot's COMMIT attests only
length and CRC by design, so a raw OBP client can flash anything. The guard
lives in `opendongle --enter-bootloader --image`, which refuses an image whose
ODG2 family does not match the connected device — before the reboot, while the
app is still the thing answering. A deliberate raw-OBP client bypasses it; that
is an accepted property of the update path, not a defect.

An interrupted update leaves the device **running the previous application**,
not stranded in the bootloader. Under A/B, mutations target the *inactive*
slot, so the running image is never touched and BOOT falls back to it. Retry
the flash to recover. (This inverts the pre-A/B behaviour, where an interrupted
transfer left the device in the bootloader.) The A→B transition itself is
validated on hardware; the interrupted-update paths are not — see "Updating:
use the bundle" below.

## Idle timeout / fail-stay

`OB_IDLE_TIMEOUT_MS` is **real milliseconds**, so the boards' `10000` means
10 seconds. It previously counted poll iterations, where the same value
bench-measured ~273 s on CH570 and ~86 s on CH592 — the value did not change,
its meaning did. Measured on a CH570 after the bump: bootloader at t+1 s,
application back at t+11 s.

Anything that waited out the old window is now ~27× too slow, and
`opendongle --enter-bootloader` returns with most of the 10 s already spent —
a human typing the next command by hand will usually miss it. Script it.

Two further caveats:

- After any successful HELLO, idle auto-boot is suppressed until reset: an
  abandoned OBP session leaves the dongle in the bootloader until
  power-cycled or told to boot (fail-stay). Scripts must finish with a flash
  or an explicit `openboot boot`.
- A CRC-valid but wedged app cannot be forced into the bootloader from
  outside (no strap): recovery is `--enter-bootloader` if IAP still answers,
  else SWD / ROM ISP.

## Factory install

Factory image = OpenBoot ‖ `0x00` pad to `0x2000` ‖ app ‖ `0x00` pad ‖ slot A's
`OBR2` record. The pad is programmed flash, so the post-flash readback compare
covers the whole file; `0xFF` padding would program nothing and fail the
compare.

```sh
make ch592-factory-flash WCHLINK_SERIAL=… MRS_TOOLCHAIN=… OPENBOOT_TOOLCHAIN=…
```

That is the whole procedure. The unit boots the application on first power-on;
there is no bless step and none is possible (see above). `OPENBOOT_TOOLCHAIN`
must point at GCC 12 — `check-openboot-toolchain` refuses anything else,
because OpenBoot's own compiler check went advisory upstream while GCC 15
remains unvalidated on ch57x.

## Updating: use the bundle, not a bare .bin

`make bundles` produces one bundle per chip, carrying **both** per-slot builds —
`ch570/build/ch570-product.obb` and `ch592/build/ch592-product.obb`, each
relative to its chip directory. OpenBoot alternates its write target after every COMMIT and
refuses an image whose base is not the current `write_base`, so a bare `.bin` is
only ever right for one slot — by luck. `openboot flash app.obb` picks the
variant matching the device.

```sh
opendongle --enter-bootloader --image <slot-a>.bin      # family-guarded reboot
openboot --vid 0x0C45 --pid 0xFEFE flash app.obb --force
```

Run those back to back, or script them. The 10 s idle auto-boot starts as soon
as the bootloader comes up and `--enter-bootloader` returns with most of it
already spent, so a human typing the second command by hand will usually miss
the window and find the application running again. Conversely, once any command
has completed a HELLO the device **stays** in the bootloader until told
otherwise (fail-stay) — end an interactive session with `openboot boot`.

Validated on a CH570 over USB, A→B→A with the real application: the device
reported `active A, writing B` and the bundle selected the slot-B variant, then
`active B, writing A` and it selected slot A, with the running build id matching
the chosen slot's image each time. The RF bond survived both updates: it sits
**at** `0x3A000`, which is exactly `OB_APP_END`, and that bound is exclusive —
the OBP-writable region is `[0x2000, 0x3A000)`, so the bond is the first
address outside it rather than something above a margin.

## Pairing procedure

A **bonded** dongle accepts a fresh pair only in the **first few seconds after
boot**: it boots into reconnect, and the boot-window timer alternates onto the
pair address for roughly three seconds so a new keyboard can still get in.
Order matters there: put the keyboard into pairing mode FIRST (so it is already
broadcasting), then power-cycle or replug the dongle. Clearing the bond over IAP
(command 0x89) is the other way in.

An **unbonded** dongle — factory fresh, or just cleared — arms no boot-window
timer and camps in pairing indefinitely, so there is no window to miss. If you
are unsure which you are holding, clear the bond and the timing stops
mattering.

Pairing is a mode-selection sequence at the keyboard
(select USB → select 2.4G → pair), not a single command; a combined
"factory pair" that skips the transport bring-up does not reach the air. A
bonded link that shows `waiting for reconnect` joins on the first keystroke —
keyboards sleep between activity.

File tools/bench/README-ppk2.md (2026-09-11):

# ppk2d: Nordic PPK2 bench daemon

Owns the Power Profiler Kit II for the whole bench session and answers current queries over a
unix socket, so gate and ladder scripts get calibrated readings without touching the device.

Why a daemon: the PPK2 opens its series switch whenever the host serial session ends, in ampere
meter mode as well as source mode, and Nordic's app closes it silently on connect. The process
holding the port is therefore what keeps the DUT powered. Every ad-hoc open/read/close (including
the nRF Connect app quitting) is a cold boot of the dongle. Only one client can hold the port.

    python3 -m venv .ppkvenv && .ppkvenv/bin/pip install -r requirements-ppk2.txt
    PPK=.ppkvenv/bin/python3          # every invocation needs the venv interpreter
    nohup $PPK ppk2d.py serve --log logs &        # start once per bench session
    $PPK ppk2d.py status
    $PPK ppk2d.py mark pre; ...; $PPK ppk2d.py mark post
    $PPK ppk2d.py stats --since pre --until post   # exact percentiles inside the ring
    $PPK ppk2d.py stats --last 60
    $PPK ppk2d.py power off; sleep 1; $PPK ppk2d.py power on   # cold-boot the DUT
    $PPK ppk2d.py raw --seconds 2 --out trace.csv              # 100 kS/s slice for waveforms
    $PPK ppk2d.py quit                                         # DUT loses power

Notes: reads the full calibration metadata itself (the library's own loop drops chunks on macOS
and silently falls back to default shunt values); refuses to run unless the device reports ampere
meter mode, and never sends REGULATOR_SET in that mode. `serve --allow-source` is an explicit
opt-in that lifts the ampere-only check; use it ONLY when the PPK2 is wired as a source meter and
its configured VDD is safe for the DUT, since in source mode the PPK2 powers the DUT itself. The
daemon still never programs the regulator. Also: macOS lists both PPK2 CDC ports, the
lower interface is the one that answers; per-second min/mean/max go to the CSV log.

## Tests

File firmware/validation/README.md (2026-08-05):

# AES hardware validation

On-silicon validation of the `hal_aes.h` seam across every backend.

> **Flashing a validation image ERASES OPENBOOT.** These images are standalone
> and own the whole part. A device that has run one is not a dongle until it is
> re-flashed with a factory image. The runner will not write anything without
> `--confirm-erase 1`.

Nothing here runs during `make all` or `make test`. Both stay hardware-free and
toolchain-free; this is opt-in, and you run it when the cipher, the seam or a
backend changes.

## Why this exists

Roughly 45% of the AES code is hand-written RISC-V assembly in two variants.
The property the whole design rests on is that **every backend produces
identical ciphertext** — that is what lets an encrypted CH570↔CH592 link work
at all, and it is not something a unit test on one chip can establish.

## Arms

| arm | chip | backend | notes |
|---|---|---|---|
| `ch570-asm-a` | CH570 | `ASM_A` | the shipping default |
| `ch570-asm-f` | CH570 | `ASM_F` | zero SRAM code; needs the loop buffer |
| `ch570-c` | CH570 | portable C | the fallback any future chip gets first |
| `ch572-hw` | CH572 | hardware engine | same driver as CH592, different silicon |
| `ch572-asm-a` | CH572 | `ASM_A` | same-silicon software-vs-engine control |
| `ch592-hw` | CH592 | hardware engine | |

`ASM_F` requires `CORECFGR` bit 3 (`ROM_LOOP_ACC`). Production now boots
`0x2D`, which has it set, so the arm builds and runs. If the startup value ever
returns to `0x25` the backend's `#error` guard resumes refusing the build, and
the runner reports the arm as skipped with the reason — **that refusal is
correct behaviour, not a broken arm**: without it the backend would be
bit-exact but roughly 15× slower than its documented cost, silently. The
runner derives the condition from `ch570_corecfgr.h`, so no configuration
accompanies the flip in either direction.

CH572 is the control that matters historically: it is the same family as CH570
and *has* the AES engine at the same register block, which is how "CH570's
engine is absent" was distinguished from "CH570's engine is mis-driven".

## Running it

```sh
# Build every arm, touch no hardware. Proves the ASM_F guard still fires.
make aes-hw-build MRS_TOOLCHAIN=<gcc bin dir>

# See exactly what would happen, contact nothing.
make aes-hw-validate AES_HW_ARGS="--dry-run" MRS_TOOLCHAIN=<gcc bin dir>

# For real. Name a probe per chip you have.
make aes-hw-validate MRS_TOOLCHAIN=<gcc bin dir> \
    AES_HW_CH570=<probe serial> AES_HW_CH572=<probe serial> \
    AES_HW_CH592=<probe serial> \
    AES_HW_ARGS="--confirm-erase 1 --allow-skips 1"
```

`--allow-skips 1` is needed for any run that does not cover every arm, and one
always does: `ch570-asm-f` cannot be built while CORECFGR bit 3 is clear. Without
it the run reports `INCOMPLETE` and exits 1 even though every arm that ran
passed. That default is deliberate -- a suite that quietly tests a subset and
prints PASS is worse than one that fails -- so pass the flag when a partial run
is what you meant, and leave it off in CI.

Probe serials are **required per chip and never guessed**. With several probes
attached, minichlink picks one arbitrarily and says so only in a warning; a
multi-probe bench routinely carries boards that must not be written. An arm
whose probe is not named is skipped and listed as skipped — a suite that
quietly tests three arms and reports success is worse than one that fails.

Find serials with `minichlink` (it lists them when more than one is attached).

Exit codes: `0` pass, `1` generic failure, `2` assertion failure, `3` probe or
infrastructure failure. `3` is kept distinct so a dead probe never reads as a
broken cipher. Note that `make` collapses any non-zero status to its own `2`,
so call `validation/run_aes_validation.py` directly when you need to act on the
distinction.

## What each arm checks

Six published known-answer vectors (FIPS-197 C.1, the all-zero vector, and the
four NIST SP 800-38A F.1.1 ECB blocks), five contract properties from
`hal_aes.h` (in-place, partial overlap `out = in+1`, repeated `set_key`, key
change and back, same block twice), and a 512-block differential with an
independent pseudorandom key and plaintext per block folded into one FNV-1a-32.

Independent keys matter: a fixed-key sweep never exercises the key schedule,
which on the assembly backends is a separate hand-written path from the cipher.

The differential fold is **`b106130c`**. It is not a magic number copied from a
bench log — `tests/test_aes_sw.py` re-derives it on the host from the portable
cipher, and `tests/test_aes_validate_harness.py` re-derives it again by running
this very harness on the host. A hardware arm only has to match a value two
independent implementations already agree on.

Cycles per block, key-schedule cycles and the configured `CORECFGR` are recorded
as regression signals, never as pass/fail. A slow cipher is something to
investigate, not a failure.

## Measured results

Production CORECFGR is `0x2D` (ROM loop buffer on). Every buildable arm passes
and produces the same differential fold — the property the suite exists to
prove:

| arm | chip | fold | cycles/block | key schedule |
|---|---|---|---|---|
| `ch570-asm-a` | V3C @100 MHz | `b106130c` | 1,672 | 7,647 |
| `ch570-asm-f` | V3C @100 MHz | `b106130c` | 3,960 | 7,405 |
| `ch570-c` | V3C @100 MHz | `b106130c` | 30,694 | 16,543 |
| `ch572-hw` | CH572 @100 MHz | `b106130c` | 2,967 | 322 |
| `ch572-asm-a` | CH572 @100 MHz | `b106130c` | 1,672 | 7,647 |
| `ch592-hw` | CH592 @60 MHz | `b106130c` | 871 | 838 |

The V3C rows measure identically on CH570 and CH572 silicon — same core, same
buffer — which is what lets either part stand in for the other on the bench,
and figures reproduce to the cycle across independent sweeps (key schedules
within ±2). At the old `0x25` (buffer off) the same silicon measured ASM_A
1,944 / 59,113, C 43,396 / 45,378, CH572 engine 4,011 / 5,126, with ASM_F
unbuildable; those flash-dominated figures moved ~3% with unrelated link
shifts, so read them to two significant figures.

`ch572-asm-a` exists so the software-vs-hardware comparison is same-silicon:
**the assembly kernel is 1.8× faster than the hardware engine** on the part
that has the engine (1,672 against 2,967). The engine core is not slow, its
driver is — it reloads the key and shuffles data through registers on every
block. The key schedule leans the other way (7,647 against 322, SRAM-key
semantics), so the engine wins below ~6 blocks per key and the software kernel above.

Cycle figures are measured in-loop and include call overhead, so they run a
little above kernel-only costs quoted in bench material. The key-schedule
column is timed with the key in SRAM -- the production regime, since real keys
come from the bond record in RAM. It was previously timed with the flash-
resident KAT constant, which inflated the hardware arms 2-10x and looked like
an anomaly; the anatomy below is what that investigation found.

## The key-schedule numbers: an anatomy

The hardware arms once reported a key-schedule cost "far above what caching
four words can plausibly take" (CH572 5,126 at CORECFGR 0x25, 1,707 at 0x2D;
CH592 1,359), with a CH572/CH592 ratio that did not match the clock ratio.
Investigated to closure; three stacked causes, none of them the driver's logic
or the engine:

1. **The code is not what the source says.** GCC 15.2 at -O2 compiles the
   driver's "cache four words" loop into a tail call to newlib-nano's memcpy —
   a one-byte-per-iteration loop, ~110 flash-resident instructions per call.
2. **The measured key lived in flash.** The KAT constant is `.rodata`, so every
   call did 16 flash *data* reads. Measured on CH572 @0x2D with matched loops:
   the identical 16-byte copy costs 118 cycles from an SRAM source and ~1,760
   from a flash source. A discriminator (same bytes as 4 aligned word loads:
   182 cycles) shows the penalty is **per access**, roughly 10x worse for byte
   loads than word loads; source alignment is a ~5% effect, no cliff.
3. **On CH592, instruction fetch itself.** The V4C core has no loop buffer and
   its 60 MHz flash fetch measured ~4.1 cycles/instruction even straight-line,
   so the ~110-instruction loop dominates: ~800 of the 1,359 was fetch.

The clock-ratio "anomaly" dissolves accordingly: the two parts differ in fetch
and data-path architecture, not just clock.

Two lessons the investigation itself paid for, worth keeping:

- **Micro-benchmarks under the loop buffer are placement-sensitive.** An empty
  call+ret probe measured 160 cycles in one layout and 13 in the next; the
  set_key field moved 12% from unrelated harness edits. Individual small
  figures at 0x2D are not stable; only deltas between matched loops in the
  same image are. (This is also why the flash-resident block figures carry a
  two-significant-figures caveat.)
- **Time the regime that ships.** The field now measures set_key with an SRAM
  key; the flash-key worst case and the full decomposition remain available by
  building an arm with `EXTRA_CFLAGS=-DDONGLE_VALIDATE_TIMING_PROBE`, which
  emits timing tags 3-9.

The switch to SRAM-key semantics also lowered the software arms' key-schedule
figures ~10-15% (e.g. ASM_A 8,899 to 7,647) — their real expansion work had the
same 16 flash key-byte reads buried in it.

## How results come back

The harness cannot print: `printf` blocks at boot when no debug terminal is
attached, which stalls the probe and looks exactly like a hung cipher. Instead
it fills `aes_log[]` in RAM and spins; the runner halts the core and reads the
array out.

`aes_log` is an ordinary exported `.bss` array and the build resolves its
address into `build/<arm>/manifest.json`. It is deliberately **not** at a fixed
address — the original bench harness used a hard-coded `0x20001000`, which is
correct only until something else in the image grows into it, and nothing would
have caught that.

| file | role |
|---|---|
| `aes_log_format.h` | the wire format, shared by harness and reader |
| `aes_validate.c` | the harness; calls `hal_aes.h` and nothing else |
| `read_aes_log.py` | decodes and judges a record; usable standalone |
| `run_aes_validation.py` | builds, flashes, verifies, runs, reads, reports |
| `validate_platform_ch5*.c` | clock bring-up and fatal vectors |
| `link-ch5*.ld` | standalone link, at 0x0 |

`read_aes_log.py` parses its marker constants **out of `aes_log_format.h`**
rather than declaring its own copies, so the reader cannot drift from the
firmware and be believed anyway. Records are fixed-width per marker and the
reader walks them; on a desync it stops and reports the offset rather than
scanning forward, which would eventually resynchronise onto payload data and
produce a confident, wrong report.

Decode a dump by hand with:

```sh
python3 validation/read_aes_log.py record.hex     # judges it
python3 validation/read_aes_log.py --decode-only record.hex
```

## Two traps worth knowing

**SysTick's `STCLK` bit.** Clear, SysTick counts HCLK/8 and every cycle figure
is 8× low. `cycles_init()` sets it explicitly. An entire measurement campaign
was invalidated by this once, and the wrong numbers were plausible enough to
reach a published header before anyone noticed.

**`CORECFGR` must never be READ on CH570.** CSR `0xBC0` is `CORECFGR` on
CH570/CH572, and production only ever writes it. A `csrr 0xbc0` **resets the
part** — and the symptom is thoroughly misleading: the device reboots, `.bss`
is cleared, and the log comes back looking as though the cipher hung partway
through the differential at a deterministic block count. It cost a long
debugging session, and the read existed purely to record the configuration a
measurement was taken under, so it destroyed the measurement it was there to
qualify. The harness now logs `CH570_CORECFGR_VALUE` — the same constant the
reset handler writes, from the same header, so it still cannot drift. On
CH592's V4C core that CSR address is a different register entirely, so the
section is compiled out there.

## Afterwards

Every device written is left running a standalone image with no bootloader:

```sh
make ch570-factory-flash WCHLINK_SERIAL=<serial>
```

## CORECFGR bit 3 (ROM_LOOP_ACC): how 0x2D became production

Measured on V3C silicon at 100 MHz; the AES table above is the 0x2D result.
The flip's headline is the key schedule, not the block: ASM_A's went from
67.6% of an 875 µs poll slot to 10.2% (59,113 → 8,899 under the flash-key semantics of the day, 6.6× — the field now times SRAM keys and reads 7,647) for zero SRAM,
and ASM_F became buildable and measurable at all (3,960-3,992 across layouts,
against its unverified bench figure of 3,797).

RF at `0x2D`, end to end on a production keyboard: pairing, reconnect, typing,
indicators, media keys and sleep/wake all pass; bench pairing was verified down
to the bond write at `0x3A000` and HID reports arriving on the host. That
exercises both sites that reach the vendor bring-up (boot, and the
post-bond-save reconnect in `rf_task.c`), so the known delay-loop hazard — the
calibration settle in `RFEND_DevInit` collapsing ~99 µs → ~3.3 µs — did not
manifest on any functional path.

Two rules were established the hard way and live in `ch570_corecfgr.h`:

- **Write CORECFGR once, at reset, never again.** A guard that dropped to
  `0x25` across the vendor RF init and restored `0x2D` after broke pairing
  outright (0/2, bond never written) against a byte-exact passing control.
  Both *consistent* configurations work; mixing them fails — the vendor init
  appears to derive timing-dependent values that runtime consumes.
- **Never read it.** CSR `0xBC0` is write-only on this silicon; `csrr`
  destabilises the part (A/B: 3/3 failures with the read, 2/2 passes without).

Residual risk, named rather than buried: RF **margin**. An under-settled
calibration is exactly the fault that works at bench range and degrades at
distance or under interference; functional passes do not retire it.

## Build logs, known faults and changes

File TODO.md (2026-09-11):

# TODO

Known work, deliberately not done during the initial firmware import so that the
imported tree stays byte-identical to the artifacts that passed hardware
validation. Anything here that touches a firmware source, a linker script, or
`dongle_image_id.py` / `finalize_image.py` changes the compiled build id, so it
should land together with a re-run of the hardware matrix and re-pinned digests.

## Fixed 2026-09-09: EP6 OUT could be left NAKed, wedging the vendor HID interface

`USB_IRQHandler`'s EP6 OUT case latched an IAP packet only on `TOG_OK` with nothing
pending, then NAKed the endpoint unconditionally; the only re-ACK is in `USB_PollEP6()`,
which runs only when a packet is pending, so a toggle mismatch with nothing pending
(a retransmission of a packet already taken, or a bus error) left EP6 OUT NAKed until
a bus reset or a power cycle: no `--info`, no bond operations, no `--enter-bootloader`.
The case now judges the toggle from the interrupt-status sample already taken and
re-ACKs when nothing was latched and nothing is pending; a latched packet keeps the NAK
the poll re-ACKs, and the pending-while-completed branch is defensive (the SIE's
auto-busy holds NAK until the transfer flag is cleared, so ordinary traffic cannot
reach it). The wedge IS reachable by a conforming host: a valid OUT whose ACK is lost
is retried with the same DATA PID after the command has already run, which is exactly
the toggle mismatch with nothing pending (USB 2.0 8.6.4); it needs a bus error, not a
misbehaving host. Not host-reproducible on the bench, so the check is non-regression:
pipelined writes and the normal maintenance flows. Pre-existing and separate: the
bus-reset path re-ACKs EP6 OUT without cancelling a pending command, so an OUT admitted
then can overwrite `EP6_Buf` under the old length. Both chips' bytes change; the CH570
image is compiled, not bench-verified.

## Fixed 2026-09-09: the terminal reconnect camp has a liveness watchdog

**What was wrong.** Every terminal camp (EV10 give-up, closed boot window, unbonded
start) armed RX once and then leaned on the radio's own events to re-drive it. The
intended backstop, `rf_arm_retry_if_failed()`, fires only on a non-zero arm status,
which neither radio library ever returns for the static descriptor, and CH59x
basic-mode RX has no timeout at all. A lost completion or a deaf PHY left the dongle
in `waiting for reconnect` until a chip reset (seen once on the bench, 2026-09-04).

**Fix.** The camp keeps the boot-window slot, free in every terminal camp, as a 200 ms
liveness tick (`rf_camp_watchdog_tick`, dispatched through `RF_EVT_BOOT_WINDOW` with the
window closed, so it costs no delayed-post slot on CH570). A tick that saw an RX-side
event since the last one (data, CRC error or timeout, from the PHY counters) leaves the
radio alone. A silent tick re-arms RX from task context under the 0x94 ladder's IRQ
mask: on CH59x a silent camp is the normal state, so every silent tick re-arms
preventively (shut + config + RX, ~100 µs per 200 ms); on CH570 the 30 ms camp timeout
keeps the counter moving, so a silent tick means the loop died and the second in a row
escalates to shut + vendor re-init + re-arm (rung 2 of the 0x94 ladder's code path, not
bench-verified on CH570 here). The tick
self-disables outside the exact terminal camp; the burst accept in the radio sink and
every other boot-window cancel end it. A restart that lands in a terminal camp without
the tick (the bond-clear tombstone paths) starts it from the `RF_EVT_RX_RESTART` handler,
so no camp depends on its entry site remembering to. `--rf-poke 3` shuts the radio and leaves it
deaf as the fault injection; page 1 `camp_wd_rearms` (u16, the page's last free bytes)
counts the re-arms. Bench: see the release note.

**Still open.** A deaf-but-cycling CH570 PHY (its 30 ms camp timeouts keep firing while
it receives nothing) looks alive to this test, which measures event-loop progress, not
reception; it needs the separate policy the original entry named (a preventive re-init
after a long interval with timeouts only), and the diagnostics to tell it apart are the
0x94 ladder and page 1 `rx_timeout` against `rx_done`. The pair-ACK burst has the TX-side
twin (a `StartTx` that returns 0 without a `TX_FINISH`), which needs a per-TX completion
timer. The CH570 rung-2 escalation count (`rfd_camp_wd_reinits`) has no page byte left
and is debugger-only. CH570 is compiled, not bench-verified (no CH570 on this bench).
Bounds as shipped: a lost completion is re-armed within two ticks; rung 3 resets the
tick's baseline and is re-armed at the next one.

## Defect: `IAP_Service()` bounds its reboot fail-safe with a clock that stops in the reconnect camp

**Where:** `firmware/common/src/iap.c`, `IAP_Service()` — `IAP_SVC_RF_QUIESCE_TICKS`
(500 ms) and `IAP_SVC_USB_DRAIN_TICKS` (250 ms) are measured with `hal_now()`.

**What is wrong.** On CH570 `hal_now()` is the `st_*` software epoch, which only
advances while some soft-timer slot is armed: with nothing armed `st_rearm()`
stops the TMR and `st_now()` returns a constant. The terminal reconnect camp arms
no slot (the 30 ms RFIP timeout drives its re-arm), so the clock is frozen there
— measured on the bench (2026-09-04, IAP `0x92` page 0): `hal_now()` read the
same value in samples 3 s apart. `IAP_Service()`'s two "wall time" bounds
therefore never expire in that state, nor after the quiesce has cancelled every
slot. A quiesce request that never completes, or an EP6 reply the host never
consumes, then blocks the promised fallback reset indefinitely instead of for
500 ms + 250 ms. The comment in `iap.c` ("Deadlines are WALL time via
hal_now()") records the intent, not the behaviour.

**Impact.** No effect on the RF link (no camp-side acceptance gate depends on
elapsed `hal_now()` time; relative timing resumes as soon as a slot is armed).
It only weakens `--enter-bootloader`'s fail-safe. Latent; the normal path
completes both stages long before either bound.

**Fix sketch.** Bound the two stages with a continuous source (SysTick, which
`st_now()` already uses while a slot is periodic) or with pass counts sized to
the main-loop rate measured by the diag page (~44 k passes/s), and say so in
the comment.

*Found by codex during the review of the IAP `0x92` RF diagnostics page,
confirmed by the page's own readout.*

## Defect: CH570 one-shot arms wider than 26 bits are silently truncated

**Where:** `firmware/ch570/src/main.c`, `st_rearm()` — `R32_TMR_CNT_END = d`
with no clamp. Reached with an oversized `d` from
`firmware/common/src/rf_task.c`, the EV10 reacquire watchdog.

**What is wrong.** The CH570 SDK documents the register plainly:

```c
#define R32_TMR_CNT_END (*((PUINT32V)0x4000240C)) // RW, TMR end count value, only low 26 bit
```

The scheduler writes a full 32-bit tick delta into it. At the CH570's fixed
100 MHz, 26 bits caps a single hardware arm at 67,108,863 ticks — **671 ms**.
The reacquire watchdog is `RF_SUPERVISION_STOCK_WATCHDOG_TMOS` (0x0d48 = 3400
TMOS units) × `HAL_TMOS_UNIT_TICKS` (62,500) = **212,500,000 ticks, 2.125 s**.
The hardware keeps the low 26 bits, 11,173,408 ticks, and fires after about
**112 ms** — a factor of 19 early.

It gets worse than an early fire. `st_armed_delta` keeps the *untruncated*
212,500,000, and the expiry path advances `st_epoch` by that amount, so the
software clock jumps roughly 2.01 s ahead of real time in one step. Every other
soft timer with a deadline inside that span is then past due and dispatches in
the same pass.

**Reachability (corrected 2026-09-04, measured).** Latent, not confirmed. The
oversized arm is written to the register only when the EV10 slot is the
NEAREST active deadline. `rf_enter_stock_reacquire()` exits the periodic grid
(its own `hal_timer_cancel(HAL_TMR_SLOT_CONNECTED_POLL)`; note
`rf_send_keys_up_on_link_loss()` cancels nothing), posts `RF_EVT_PAIR_PREP`
and then arms EV10 -- and `rf_send_pair_prep()` re-posts itself as a 30 ms
delayed event for the whole scan, so the 30 ms deadline is re-selected on every
`st_set` and the truncated value is live only for the odd main-loop pass
between the arm and the next re-post. Bench (IAP `0x92` page 3, connected
-> keyboard gone): 71 pair-prep arms per scan = ~2.1 s, i.e. the watchdog
expired at its intended time in every observed cycle. It would bite whenever a
>671 ms one-shot is the nearest armed deadline with nothing shorter alongside
it (a >= 2 ms pump stall at the wrong pass, or a future caller); the fix below
stands, but this is not the bonded-reconnect failure.

**Scope: CH570 only.** CH592 routes the same call through
`hal_tmos_units_from_tsys()`, which divides back to 3400 TMOS units and arms a
TMOS software timer. No 26-bit register is involved. The 300 ms boot window
(480 TMOS units = 30,000,000 ticks) fits on both chips, which is consistent with
the boot window behaving correctly in the hardware campaign while this stayed
hidden.

**Fix sketch.** Clamp the hardware arm to the register's maximum and advance the
epoch by *what was actually programmed*, re-arming until the absolute deadline
is reached. `st_armed_delta` must always equal the value written to
`R32_TMR_CNT_END`, never the requested delta — that invariant is what the
current code breaks.

**Before merging the fix:** it changes firmware bytes on CH570, so re-run the
hardware matrix and re-pin the digests. Worth adding a bench case that forces a
link loss on CH570 and measures the reacquire watchdog against a wall clock.

*Found by codex during the import review; confirmed by reading the SDK register
definition, the tick constants, and the cancel-then-arm ordering in
`rf_send_keys_up_on_link_loss()`.*
## Hazard: the IN handlers fight the hardware toggle, and the obvious fix is not safe

**Where:** `firmware/common/src/usb_device.c` — `USB_HID_IN_TOG_MODE` is
`RB_UEP_AUTO_TOG`, applied to EP1/EP2/EP3/EP5 (and EP6 directly), while each
IN-completion case also does `R8_UEPn_CTRL ^= RB_UEP_T_TOG`.

**Nothing is broken today.** The two disciplines are not both in force: with
`AUTO_TOG` set the hardware owns the toggle bit, so the software XOR does not
reach the transmit sequencer. That is not inferred from silence — the datasheet
assigns bit 4 the auto-flip and confirms it covers EP1/2/3/5/6 on both chips,
the sibling CH582F firmware runs AUTO_TOG-only and works, and the project's own
notes state the rule outright. It is also the only model consistent with the
bench: if both halves were live they would cancel, EP1 would deliver exactly one
keystroke report and go silent, and the IAP endpoint would wedge on its first
response.

**Why it is still worth recording.** The file states its own contract one line
above the define — "production HID endpoints use the validated automatic-toggle
mode" — and the surviving XORs contradict it. They are benign only because the
hardware wins the argument. They become load-bearing the moment someone drops
`AUTO_TOG` to return to the manual discipline, at which point the XORs silently
go live and the `CLEAR_FEATURE(HALT)` DATA0 reset changes meaning too. The
project has already written this combination up as a silent-data-loss
anti-pattern and already removed it once on CH582F; the shared CH592/CH570 path
reintroduced it.

**Do not "just delete the XORs".** That is the obvious remediation and it was
specifically examined and rejected — the cleanup is not safe as a
drop-in. Whoever takes this needs to work out the correct end state first, on
the bench, rather than removing five lines because they look dead.

**Note this is a divergence, not a stock reproduction.** WCH's own examples do
carry the manual XOR, but their bus-reset handler re-arms the endpoints
*without* `AUTO_TOG`, so in vendor code the two disciplines never coexist. This
firmware re-applies `AUTO_TOG` on every bus reset, so here they do.

## Defect: CLEAR_FEATURE(ENDPOINT_HALT) ignores the direction bit

**Where:** `firmware/common/src/usb_device.c`, the `CLEAR_FEATURE` handler —
`wIndex` is masked with `0x0F`, discarding bit 7.

The switch therefore always clears the **IN** half of the named endpoint. EP6 is
bidirectional — `R8_UEP567_MOD` enables both TX and RX and the descriptor
declares OUT endpoint `0x06` — so a host clearing a halt on EP6 **OUT** resets
the IN half instead: wrong endpoint direction reset, and the OUT half left as it
was.

**Reachability is low.** No in-box HID class driver issues this request against
this device, and the maintenance path reaches EP6 through hidraw rather than a
class driver. It needs a host that deliberately halts and clears an endpoint.

**Fix:** decode bit 7 of `wIndex` and act on the matching half. Changes firmware
bytes, so it lands with a re-validation.

## Hygiene: EP0 accepts malformed control transfers instead of stalling

**Where:** `firmware/common/src/usb_device.c`, the standard-request switch.

Four host-to-device requests never inspect the direction bit of
`bmRequestType`: `SET_ADDRESS`, `SET_CONFIGURATION`, `SET_IDLE` and
`SET_PROTOCOL`. A host that sets the IN bit on one of them is ACKed rather than
stalled, the state assignment still happens, and because `usb_setup_len` is left
at `wLength` with `usb_desc_ptr` NULL, the device returns up to 56 bytes of
`EP0_Buf` residue on the data stage. (`GET_CONFIGURATION` with the direction bit
cleared is also unvalidated but inert: it stages a zero-length IN and the stray
OUT is ignored.)

**Why this is filed as hygiene rather than a disclosure.** Every writer of
`EP0_Buf` was enumerated: the buffer only ever holds the host's own SETUP bytes,
public descriptor fragments, single status/config/idle/protocol bytes, and the
keyboard LED byte. No serial-number string is served — string indices other than
0 and 2 stall — and IAP traffic never touches EP0, it is EP6-only. There is no
over-read either, since the transmit length is clamped to `sizeof(EP0_Buf)`. So
what leaks back is data the host already has or could ask for legitimately, and
the requests themselves only set state the host is entitled to set. No
conforming host emits these tuples; it takes a fuzzer, a compliance suite, or a
deliberately hostile host.

**Worth doing anyway**, because stalling malformed control transfers is what USB
chapter 9 requires and it is the difference between passing and failing
compliance tooling. Note the direction checking in this file is already
opportunistic rather than systematic — `GET_DESCRIPTOR`, `GET_REPORT`,
`GET_IDLE` and `GET_PROTOCOL` omit it too — so the tidy fix is a single
direction check at the dispatch point rather than four scattered ones.

## Fixed 2026-09-09: the connected hop lost the keyboard after a coalesced gap of 5k poll slots

**Where:** `firmware/common/include/rf_protocol.h`, `rf_proto_hop_step()`; the seed
sites in `firmware/common/src/rf_task.c`.

**What the filed overflow really was.** The entry below this one used to describe a
32-bit overflow in the repeat-correction branch (reachable, bounded, "a deliberate
decision to deviate from the recovered rule"). The bench campaign that decision
triggered found the branch itself is the defect, and the overflow only its rarest
symptom: the recovered rule reset the anchor to the poll time, took
`step = elapsed / interval`, and whenever the index landed back on the previous one
forced a slot forward and forward-dated the anchor. That is right for a poll a tick
early (step 0) and wrong for a coalesced gap of exactly 5, 10, 15 ... slots, where
the keyboard is already on that channel: the forced slot misses it, the next poll
takes the wrap arm and hops two slots, and supervision tears the link down.
Masking the dongle's interrupts for a whole number of poll slots on a live link
(`opendongle --rf-poke 40+N`) dropped the link every time at 5 and 10 slots and
never at 1-4, 6-8 or 12. Restricting the correction to step 0 only moved the
failure into the remainder band after a 5k gap (codex counterexample: 5 slots +
15..27 ticks).

**The fix is a model, not a patch.** The dongle now keeps the keyboard's model: an
edge anchor 13 ticks before the poll it expects (`RF_PROTO_HOP_EDGE_LEAD`, every seed
site backdates the grid origin by it), `step = elapsed / interval` from that anchor,
the anchor advanced by step WHOLE intervals (`rf_proto_hop_add`, the poll's jitter
stays in the phase), the index by step mod 5. No correction branch, no reset to the
poll time, and the modular add subtracts before it adds so the sum cannot pass 2^32
(the original finding, closed by construction). Both ends now count the same edges
however the polls are spaced; the one structural exception (the keyboard's servo
settles a tick short of the dongle's lead, so a poll in that two-tick window counts
one edge more, for that poll only) is documented at the definition.

**Bench (CH592, OpenController as the keyboard):** masked gaps of 1..15 whole slots
and the 5- and 6-slot remainder bands (3-tick steps across the slot) all held the
link with 0 lapses; 30 alternating 5/10-slot gaps back to back, 0 lapses; EV10 scan
cadence, bonded reconnect (10/10, 5 ms) and fresh pair unchanged; poll reply ratio
unchanged. `firmware/tests/test_hop_model.py` compiles the real function with the host
compiler and pins the seed contract, a 100k-poll grid across the modulus, every gap
of 0..20 slots and 0..27 ticks against the keyboard model, and the modulus
arithmetic (the "host-tested" clause in the source is true again).

**Not covered:** CH570 compiled, not bench-verified (the model is shared; its seed
sites changed the same way). A production keyboard was not exercised on this bench.

## Fixed 2026-09-09: an invalid bond record could leave the CH570 radio shut down

The bond-persist path's `#if !RF_TASK_EXECUTOR_TMOS` teardown (cancel all four timer
slots, `hal_rf_shut()`) ran before `bond_record_semantic_valid()`, whose early return
then left the radio shut with no timer and no re-arm driver, deaf until a reset. Latent
(the producer cannot build a record the check rejects today), CH570 only. The check is
now hoisted above the teardown, as the entry's fix sketch said, so an invalid record
returns before any radio state changes; found again by the codex pass on the camp
watchdog, which the teardown also cancelled.

## Follow-up: bench case for the mouse/consumer suspend replay fix (needs a controller harness)

**What was fixed without it:** `USB_SuspendResume` now NAKs EP2/EP3 at suspend
and `USB_PollEP6` reconciles them on resume (mouse all-up, consumer no-key,
coordinated with fresh reports through `usb_reconcile_ep2/ep3`). The change was
reviewed (three codex passes to Merge) and regression-tested on the keyboard
path (host asleep 60 s, link intact, 0 lapses, the resume flush executed against
a real host), but the defect scenario itself, a mouse or consumer press armed
when SOF stops, has not been reproduced or shown fixed on hardware.

**Why not:** the bench keyboard stand-in, OpenController, only ever transmits
the keyboard RF tag (0xA1). The dongle routes 0xA3 to EP3 (consumer,
`[id 1][usage LE16]`) and 0xA8 to EP2 (mouse, 5-byte body), and the
controller's UART accepts no frame that would make it send either.

**What the case needs:**

- **A report source:** a tagged-report UART frame in OpenController (its
  `keyboard_uart.c` parser: `expected_for_header` / `frame_is_valid` /
  `dispatch_frame`; `main.c` frame callback; `rf_task.c` `RF_QueueHIDReport`
  generalised with a tag and length so the response TX writes the tag into
  `tx_payload[1]`), streamed at the RF poll rate while the host goes to sleep,
  so an EP2/EP3 report is armed in the last poll interval before SOF stops.
- **An oracle:** page 4 of the 0x92 diagnostics is full (bytes 2-61), so a
  dongle-side "armed at suspend" / "stale IN completion after resume" pair
  needs a new page or a page-6 spare; the host side alternative is cursor
  tracking around the sleep, which needs pyobjc (Quartz) on the bench Mac.
- **Both directions:** a pending press (the original defect) and a pending
  release (the mirror case the NAK alone would have created), each followed by a
  host sleep of at least 60 s and a wake from the host's own keyboard.

## Deferred review findings

Real improvements that were not taken during the import because each one changes
the build id for no functional gain, or expands scope beyond the import:

- **`dongle_image_id.py`** — validate the ODG2 `format` and `header_len` fields
  before writing the CRC, not just `image_len`. Defence in depth against a
  malformed header.
- **`finalize_image.py`** — create both output parent directories and stage each
  temporary file beside its own destination, so a cross-directory or
  cross-filesystem `--output-bin` cannot leave an ELF written and a BIN missing.
- **`check_dependencies.py`** — the optional strict mode (`--expect-compiler-sha256`)
  covers the `riscv32-wch-elf-gcc` driver only, not `cc1`, the assembler, the
  linker or `objcopy`, so a partially replaced toolchain directory can pass it and
  still produce different firmware under the same build id; the default gate
  (GCC major + fast-interrupt probe) makes no byte promise at all. Widening the
  strict mode to a full toolchain manifest would close the gap. Related: the SDK
  cleanliness check ignores files matched by gitignore rules, which could hide a
  stray input the compiler consumes.
- **`check_dependencies.py`** — `validate_sdk()` resolves the SDK's git toplevel
  with `rev-parse --show-toplevel`. If it is ever pointed at an *uninitialised*
  submodule root (an empty directory), git walks up and answers with the
  superproject, so the revision and cleanliness checks would silently test the
  wrong repository. This does not fire on the documented path — the Makefiles
  pass `.../<chip>/EVT/EXAM`, which does not exist until the submodule is
  initialised, so the existing "SDK is missing / initialize submodules" message
  is what a contributor actually sees — but a manual invocation naming the
  submodule root would be misdiagnosed. Worth a guard that rejects a toplevel
  which is not the SDK's own checkout.
- **`hal_rf.h` — two seam contracts that do not match both implementations.**
  Neither is a runtime defect; both are headers that promise more than one of
  the ports delivers.
  - `hal_rf_start_tx()` reads as though its `access_addr` argument is
    authoritative. CH570 programs it per transmit; CH592 ignores it
    (`(void)access_addr;`) and uses whatever the last `hal_rf_configure()` set.
    The invariant holds at all five call sites in `rf_task.c` — every
    `rf_access_addr` assignment is followed by a `hal_rf_configure()` or
    `rf_start_rx()` before any transmit — so the contract should say the caller
    must configure with a matching address first.
  - `hal_rf_rx_buf()` is documented as "stable for the life of the program".
    True on CH570, which returns a static array; false on CH592, which returns
    NULL until the first receive. The function has **no callers** and is
    garbage-collected out of both images, so the honest options are to delete it
    or to document the nullable return.
- **`rxBuf` NULL handling in `rf_phy_event_sink()` is inconsistent.** One call is
  guarded (`rsr == 0 && rxBuf`) while a dozen later dereferences are not. The
  seam cannot deliver NULL on `HAL_RF_EV_RX_DONE` — CH570 passes a static array,
  and on CH592 the vendor library's contract is that the buffer is the DMA
  buffer, which its own reference callbacks dereference unguarded — so the
  unguarded dereferences are safe and the lone guard is what is out of place.
  Either drop the `rxBuf ?` hedge in `hal_rf_ch592.c` so the seam's non-NULL
  guarantee is explicit and matches CH570, or widen the early-out to cover it.
  Worth settling because as written it invites exactly the review finding it
  received.
- **Done 2026-09-09: the hop formula's "host-tested" clause is true again.**
  `firmware/tests/test_hop_model.py` compiles `rf_proto_hop_step()` with the host
  compiler behind a stdin driver and pins the seed contract, the steady grid, every
  coalesced gap against the keyboard model, and the modulus arithmetic (`make test`
  discovers it; it skips without a C compiler).
- **`ch592_boot_reset_status` cannot be inspected the way the startup comment
  says.** `startup_CH592_phased.S` tells a debugger to read boot-entry evidence
  from that name, but it is a file-scope `static uint8_t` in
  `platform_ch592.c` with no `volatile` and no `used` attribute, and nothing in
  the tree ever reads it — so at the shipping `-O2` it is optimised away and a
  debugger answers "optimized out". The retained fault record is where the reset
  status actually survives, so the comment should name that field instead. The
  dead variable should go with it.
- **`usb_device.c` — the `usb_config` invariant comment is not quite true.** It
  says a bus reset is the only thing that clears `usb_config`, and concludes
  that a pending report implies the device is configured. `SET_CONFIGURATION`
  with `wValue` 0 is explicitly accepted and also clears it, without clearing
  `usb_kbd_pending_valid`, so the implication can be violated. Behaviour stays
  safe — the gate simply fails closed — but the reasoning written down is not
  the reasoning the code relies on. (`USB_ClearPendingKeyboard()` is a second
  clearer of the stash, called on RF link loss; worth naming in the same edit.)
- **`platform_ch592.c` — two small hardenings around `dongle_nv_is_erased()`.**
  The reported failure (that the 32-byte cap makes every bond clear report
  failure) does not occur: `bond_record_t` does not exceed the cap. But nothing
  *pins* that relationship, so a future field added to the record would break
  bond-clear verification silently — a `_Static_assert` tying
  `sizeof(bond_record_t)` to the capacity both chips assume is cheap insurance.
  Separately, the local buffer would be better with an explicit
  `__attribute__((aligned(4)))`: it happens to be aligned today, which is not
  the same as being guaranteed.
- **`usb_descriptors.c` — record the IF1 mouse descriptor's provenance.** The
  button usage range declares three usages against a report count of five, which
  is genuinely non-conformant and will be re-reported by every future reviewer.
  It is not ours to fix: the descriptor is a byte-for-byte copy of the
  production dongle's own IF1 report descriptor, and changing it would diverge
  from the device being reproduced. Users are unaffected. A one-line provenance
  comment naming the source would stop this cycling.
- **Three stale or unsupported comments in the CH570 port**, all comment-only
  and all in build-id-bearing files, so they batch with the group below:
  - `hal_usb_ch570.c` — `hal_usb_pins_predetach()` is empty, but the call site
    in `common/src/usb_device.c` says it "releases the PA0/PA1 debug mux for USB
    (and runs any pull-up dance)". The mux release actually happens later, in
    `hal_usb_pins_enable()`. Deferring it there is functionally correct; the
    call-site comment is what is wrong.
  - `ch570/src/main.c` — the comment claims the contradiction between
    `RB_PWR_EXTEND` and the never-sleep policy is caught at build time. No
    `_Static_assert` or `#error` implements that anywhere. Either write the
    check or drop the claim.
  - `ch570/src/main.c` and `ch570/src/sched.h` — both describe
    `st_periodic_nudge()` as refusing when a `CYC_END` is latched or the cycle
    is past its midpoint. The REQUEST-only redesign moved the
    `R32_TMR_CNT_END` write into the TMR ISR and removed both guards; the code
    now tests only `st_periodic_slot_p1`, `st_nudge_req` and `delta`. One
    documentation update was missed at two sites.
- **Stale comments inside build-id-bearing files.** Each is a comment-only edit
  that nonetheless moves the compiled build id, so they are worth batching into
  one commit with the next re-validation rather than taken piecemeal:
  - `ch570/src/dongle_chip.h:4` and `ch592/src/dongle_chip.h:4` name
    `fw-common/src/usb_device.c`; the directory is `firmware/common/`.
  - `ch592/src/startup_CH592_phased.S`, the phase-`0xC4` comment, carries three
    addresses that no longer match the link: the stack starts at `0x20005FF0`
    (not `0x20006000`), `_susrstack` is `0x200060D0`, and `_ebss` is
    `0x20004360` (not `0x20003718`). The claim the comment is making — that the
    `0x20005800` sentinel sits above `.bss` and survives the clear — is still
    true, and `.fault_keep` is its own `NOLOAD` section, so this is an accuracy
    fix rather than a defect.
- **The OpenBoot checkout is the one pinned input nothing validates.** Its bytes
  go straight into every factory image via `compose_factory.py`, which only
  bounds their size. `check_dependencies.py` takes `--sdk`, `--sdk-revision` and
  `--toolchain` and has no OpenBoot parameter; the recursive OpenBoot build runs
  OpenBoot's own checker, which validates *its* openwch submodules and the
  toolchain but never OpenBoot's own HEAD or worktree cleanliness. Nothing
  compares `third_party/openboot` against this repository's gitlink. Neither
  `CONFIG_TEXT` nor `BUILD_ID_INPUTS` names an OpenBoot revision, so the factory
  image's identity does not depend on which bootloader was packaged. The
  application-side companion headers (`openboot_app.h`, `openboot_protocol.h`)
  *are* hashed — the bootloader image is not. Fixing this means a new gate and a
  new field in the identity, both of which move every build id, so it belongs
  with a re-run of the hardware matrix. The inaccurate "check-deps verifies both
  sides" comment in `firmware/Makefile` has been corrected to state the gap.
- **`ch570/link.ld`** — add `ASSERT(_vector_base == ORIGIN(RAM), ...)`. The early
  reset path hard-codes the vector base (`0x20000000`) and the `mtvec` value
  (`0x20000003`) instead of deriving them from `_vector_base`, which the *late*
  path does use. The literal is correct today — the map confirms
  `_vector_base == 0x20000000` — and RAM origin is fixed by hardware, so this is
  drift insurance rather than a fix. It matters because the file otherwise
  converted to linker-derived addressing (its `FAULT_KEEP_ADDR` macro derives
  from `_fault_keep_start`), leaving this literal the odd one out, and because
  `link.ld` already carries a dozen layout `ASSERT`s while none covers this one.
  Note CH592 is incidentally protected here: its `.dalign` section pins `.data`
  to RAM base + `SIZEOF(.highcode)`, so inserting a section ahead of it makes
  the link fail outright. CH570 has no equivalent.
  **Do not "simplify" by substituting `_vector_base` for the `mtvec` literal** —
  `0x20000003` carries the mode bits, and a bare symbol would drop them.

## Project

- **No CI.** There is no `.github/workflows`, so nothing on GitHub compiles this
  tree. A minimal workflow running `git submodule update --init --recursive`,
  `make -C firmware test` and `cargo test --manifest-path tools/Cargo.toml`
  would cover everything except the cross-compile, since the MounRiver toolchain
  is not redistributable.
- **Validation record not published.** The bench harness and the per-case
  hardware validation record are kept out of this repository for now; they carry
  bench-specific hardware identifiers and need a scrub pass before publication.

## Power-management follow-ups (CH592 Tier 1, 2026-09-06)

- **Heartbeat tax: measured and retired.** The keyboard-absent A/B/C (1 ms heartbeat
  10.931 mA, 10 ms 10.819 mA, none 10.796 mA, 2026-09-06) showed the cost is the
  interrupt (~0.13 mA per 1000/s), not the 60 MHz counter (<= 0.01 mA). The
  exact-deadline mode (`PM_EXACT_DEADLINE`, plan section 12) arms TMR3 to the next
  application deadline and caps the sleep for library timers; no RTC trigger needed.
  Left open: the cap default (20 ms) against the library timers' tolerance, and
  whether the 500 ms/120 s HAL calibration would rather be bounded tighter.
- **Clock gating cadence effect: characterised, shipped on (2026-09-09).** The 1.6 %
  the 09-06 absolute-rate A/B showed is not what the reply-ratio oracle sees: it puts
  the gates at ~0.2 % of poll replies (same binary, mask 0 vs 0x4DF6; both halves of
  the mask carry ~0.15 % each, so no single block explains it; the old oracle also
  counted downlink loss, the likely rest). Default is
  now `PM_CLK_GATE=1`; the mask knob stays for anyone who wants the ungated radio
  margin back at +0.25 mA. Open: the physical mechanism (supply ripple on the LDO
  changing the receiver's margin at the arm edge is the guess), which the cadence bench
  cannot see.
- **USB NAK wakes.** ~3000 wakes/s from the 1 ms-interval HID IN endpoints while the
  host is awake. Raising `bInterval` on the mouse/consumer interfaces (keep the
  keyboard at 1 ms) is a product decision; measure before changing.
- **USB IN-token wake rate is host-dependent: ~23 000 wakes/s on the bench Mac (2026-09-09).**
  Page-5 attribution in the keyboard-absent camp with the host awake reads `wake_usb`
  22 900-24 800/s in both heartbeat modes (fixed 1 ms and exact-deadline), against the
  ~3000/s the R2a finding above recorded on 2026-09-06 before the bench was unplugged and
  replugged that evening. The count is three HID IN endpoints (EP1/EP2/EP3, `bInterval`
  1 ms) at about 8000 tokens/s each, i.e. one token per 125 us microframe, as if the host
  scheduled the full-speed interrupt endpoints at the high-speed interval (EP5/EP6 are not
  polled until a client opens the vendor interfaces). Idle duty in that state collapses to
  8-13 % (it was ~86 % at 3000 wakes/s), which is what the meter shows as the camp reading
  bouncing between ~10.45 and ~10.85 mA. Not a firmware defect and not part of PR #38
  (the fixed image shows it too). To do: identify the host path (which port, hub or TT the
  dongle sits behind; `system_profiler` is unavailable inside the sandbox), check whether
  a USB 2.0 hub in between restores 1 ms polling, and decide whether a larger `bInterval`
  on the boot interfaces is acceptable for the product. Every awake-host power figure in
  the release notes for the camp state was taken in this host's polling regime.
  Update 2026-09-09 evening: a bench restart (replug) returned the rate to ~3000/s
  (`wake_usb` 2970/s, camp idle duty 87 %), so the 8 kHz regime was host state that
  re-enumeration clears, not the topology (the dongle sits on the same USB 2.1 hub
  before and after). Worth knowing when a camp reading looks 0.4 mA high.
- **The poll reply ratio moves with code layout on the receive-arm path: pinned (2026-09-09).**
  Interleaved A/B runs of `pollrate_phy.py` put the fixed 1 ms heartbeat at 99.47-99.53 %,
  one exact-deadline build at 99.80-99.83 % and the next (no change on the poll path) at
  99.51-99.52 %; a `volatile` on the CH592 `rf_diag` block, which only reorders two stores,
  gave 99.22-99.35 %. Cause, from the map: the RAM-code image was loaded ahead of flash
  `.text`, so every RAM-code edit shifted the whole BLE library, and the library's sections
  were linked after every application function, so every application edit shifted them too;
  the poll path runs mostly from flash (`RF_Rx`/`RF_Tx`/`RF_Shut`, the library's receive and
  transmit processing, TMOS, and the application's `RF_ProcessEvent`,
  `rf_connected_poll_cb`, `rf_arm_connected_supervision`, `hal_rf_shut`). `link.ld` now links
  the radio path first (library, then those functions) and loads the RAM-code image after
  `.text`: the library's addresses are identical across RAM-code and application
  perturbations (`RF_Rx` 0x3cee in every variant), and the pinned application functions move
  only when a function ahead of them in that list changes. Open: the flash-fetch period
  itself (a `TEXT_PAD` sweep on a noisy afternoon bench could not resolve it; `TEXT_PAD`
  must be even, and the effective shift is N rounded up to the first pinned section's
  alignment, so read `RF_Rx` in the map), so an edit to a radio-path function can still
  move the functions behind it. Re-run on a quiet bench after the pin (2026-09-09, once a
  bench restart had cleared the host polling storm): plain 99.76-100.26 %, `volatile`
  99.70-100.05 %, overlapping, where the same perturbation separated by 0.3 % with
  non-overlapping pairs before the pin (the ratio's absolute value carries a few tenths
  of a percent of window bookkeeping between the two counters, so only the comparison
  means anything); and the byte-identity gates
  no longer apply across this change (the linker relaxes 22 library calls to `c.jal` from
  the new proximity, 68 bytes smaller), so the gate for link-order changes is the symbol
  set with sizes plus the bench oracles.
- **Tier 2 R3b: Halt between windows in suspend (2026-09-10; `PM_HALT` default on 2026-09-11).**
  1.347 mA with the host asleep and a resting production keyboard, against 10.13 mA before Tier 2.
  That is the dongle's 3V3 feed at one operating point, not a USB compliance result: VBUS on the
  product board is unmeasured, and the unbonded camp and a continuously connected keyboard both
  keep the receiver on. The R3a spike settled the silicon question (56,986 halts, all returned, no
  library restoration needed), and the shipped entry adds what a spike may omit: an RTC
  periodic-timer backstop, a last look that also re-checks USB, both RTC flags cleared at entry,
  exact paired SysTick correction, and a 250 ms suspend cap. Gates run on the merged code
  (2026-09-10, E514E4F0): clock continuity 99.93 % of wall across a 47-minute sleep; resume with
  the USB node identity unchanged; a shipped-default soak of 14,049 halts, 67 % of the wall clock,
  zero abandoned, 1,366 catches on 1,368 phase windows, no reset; and a USB replug taken while
  halted with the probe still powering the board, after which the boot count was unmoved, the
  device enumerated fresh as expected and the link returned in a second. The fifth gate, a remote
  wake driven out of a halt, ran on 2026-09-11 and passed: the host slept at 12:09:35 and woke
  itself 145 s later with the wake attributed to `USB2_wake` rather than to the internal keyboard,
  across an episode that logged 330 halts totalling 47.4 s with zero abandoned, one keystroke sent,
  the USB node identity unchanged, the clock at 224.6 s of 224.7 s of wall, and the boot count
  unmoved. The keystroke source is a Nucleo-U083RC running QMK's OpenController driver on the
  module's UART, which parks on the USB host so the link drops and the dongle camps, engages
  windowing on the grace, then returns to wireless and presses one key; that reaches the halt
  through the camp rather than through the scheduled-drop detector, but the halt entry, the radio
  wake and the remote-wake pulse are shared. The knob was defaulted on the same day; the default
  image is byte-identical to the one every gate ran against (E514E4F0), and `PM_HALT=0` still
  reproduces the pre-R3b image byte for byte with the build id forced. Observed and benign: the
  detector unlocked and re-engaged 131 times in those 47 minutes, every one a failed acquisition
  answering no polls, each costing one continuous-scan cycle with the grace correctly not
  replenished. The run also confirmed the production keyboard's thirty-minute stage in the wild: it
  stopped probing entirely and returned only on its host's transport select. Known residual: the
  vendor halt primitive takes its wait with interrupts enabled, so a resume arriving inside its
  prologue is serviced and then slept through; the 1 s backstop bounds it, and closing it needs
  either a hardware guarantee about pending interrupts and WFI on this part or an entry that does
  not delegate the wait. Note the RAM ceiling this hit: the vendor halt primitive is 328 B of
  RAM-resident code and the product links at ~93 % of RAM against the fault-retention block, which
  was only resolved by forcing the deadline planner out of line into flash in halt builds. There is
  ~2 KB of unused RAM between the fault block and the stack, and the BLE library heap is 6144 B in
  a dongle that opens no BLE connection; either would give real headroom and both are owner
  decisions.
- **Tier 2 R1 shipped: windowed receiver (2026-09-10).** The production keyboard rests by
  stopping its session 5 s after the last key and reconnecting once a second (1.010 s,
  sd 15 ms, each connection ~10 ms); the dongle used to spend the whole second in the
  reacquire scan, and the absent camp kept RX on: the receiver is 7.15 mA of the 10.2 to
  10.7 mA idle states, the core's idle path 3.06 mA (host-independent: 3.063 awake,
  3.059 asleep with the receiver never armed). The scan and camp now open 30 ms channel-8
  windows every 200 ms plus a phase-locked window per second; awake resting state 5.74 mA
  (bench builds ran with `PM_RX_GRACE_S=0`; the shipped grace is a nominal 60 s).
  Open: R2 sweeps P in {100, 200, 500} and W in {25, 30, 40} for the shipped pair (the
  production probe is caught on any single channel, so W can shrink); R3a is a spike on
  Halt with the radio shut (datasheet Table 5-2: USB wake exists for Halt, not Sleep; a
  sleep behind TMOS hangs the next RF op on OpenController's bench) before R3b halts the
  core between windows in suspend, re-basing `hal_now()` by the halted RTC ticks; the
  ~3 % of resting cycles that fell back to the continuous scan in earlier builds were the
  detector's traffic threshold; the final build observed 0 fallbacks over 297 cycles. A resting production
  keyboard yields one lapse, one EV10 entry and one promote per second by design; "0 lapses"
  oracles describe OpenController, which never drops on its own.
- **Suspend policy.** Idle while suspended is on (10.71 mA); radio duty-cycling while
  the host sleeps (toward the USB suspend budget) is out of Tier 1 and needs the
  remote-wake latency contract first.
- **`TEM_SAMPLE`.** The library's 1 s ADC temperature sample is pre-existing; it costs
  an ADC conversion and one stale-pending clear per second. Measure before disabling.
- **CH592 OpenBoot USB bootloader on macOS** never binds as HID (usage page 0xFF00);
  USB updates of the CH592 dongle are impossible from this host. Validated only on CH570.
- **Production PB15 strap.** The park sets PB15 input pull-down; page 6 [43] reports the
  boot-time PU/PD/DIR/debug ownership. Read it from the first production CH592D unit.

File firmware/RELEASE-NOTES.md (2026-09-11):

# OpenDongle firmware — release notes

Firmware for the OpenDongle 2.4 GHz keyboard receiver, on WCH CH570D and CH592F
silicon. This document states the security property of the RF link, the known
issues that ship with it, and the manufacturing steps a unit needs before it
leaves the bench.

## Halt between receiver windows while the host sleeps (CH592)

With the windowed receiver of the previous entry the dongle is idle between windows, and while
the host is suspended nothing needs the core at all: the window schedule is an RTC timer, the
radio is shut and the link is down. `PM_HALT=1` stops the clock system between windows with the
vendor `LowPower_Halt`, which keeps every peripheral powered and wakes on RTC or USB (the
datasheet gives USB as a wake event for Idle and Halt only; a core in Sleep would sleep through
the host's resume and force a re-enumeration). A spike answered the one silicon question first:
56,986 halts with the radio shut, all returned, the resting keyboard served throughout, so the
BLE library needs none of the restoration a sleep taken behind the scheduler's back would.

The entry is admitted only when USB is suspended, the receiver is windowed with no window open,
no accepted window and no live link, and the next deadline is at least 5 ms away, on top of every
existing idle veto. Two independent wake sources are armed: the RTC trigger at that deadline less
a 3 ms clock-restart lead, and the RTC periodic timer at 1 s as a backstop no earlier event can
consume, so a trigger lost in the vendor prologue is recovered within one backstop period (1 s)
rather than leaving the dongle deaf until the host wakes. Because the vendor primitive takes its sleep instruction with interrupts enabled,
the entry takes a last look immediately before it and abandons the halt if the trigger has already
fired, if the deadline is within 1 ms, or if the USB state has moved (a resume or bus reset can run
after the unmask and clear its own flag, so only the driver's state proves anything). Both flags and
the pending bit are cleared on entry and exit; a stale periodic-timer flag would otherwise fire the
handler the moment it is enabled and abandon every halt. `hal_now()` is the SysTick, which stops
with the clocks, so it is advanced on the way out by the RTC delta minus the SysTick delta the awake
parts already counted. While the host sleeps the deadline cap becomes `PM_SUSPEND_CAP_US` (250 ms):
the window schedule is itself in the deadline table, so the cap only bounds the library's untracked
timers, its 1 s temperature sample and 120 s calibration.
Bench (CH592 950E9B1E, production keyboard resting, host asleep, measured on the dongle's 3V3
feed): 1.347 mA against 10.13 mA before Tier 2 and 5.74 mA awake, halts averaging 136 ms with zero abandoned entries, 393 catches on 395
phase windows, one give-up, no reset. Awake behaviour unchanged: poll replies 1139-1140/s of
1143/s sent, fresh pair 2/2, reacquire cadence 33.4/s, bonded reconnect 10/10 at 5 ms, the 5- and
10-slot hop gaps held, and windowing never engages against a keyboard that holds its link.
That is an operating point, not a compliance claim: it is the 3V3 rail rather than VBUS, one
keyboard resting, and neither the unbonded camp nor a continuously connected keyboard windows at
all. Shipped opt-in until its gates were complete; `PM_HALT` now defaults on (2026-09-11), and the
default image is byte-identical to the one every gate below ran against, build id E514E4F0. Setting
`PM_HALT=0` reproduces the pre-R3b image byte for byte with the build id forced. Four of the five
gates ran on the merged code (E514E4F0, production keyboard resting). A 47-minute host sleep: the
clock advanced 2843.6 s of 2845.6 s of wall time; the device resumed with its USB node identity
unchanged rather than re-enumerating; and the soak recorded 14,049 halts totalling 1917.6 s, 67 %
of the wall clock, with zero abandoned entries, 1,622 reconnects at about one a second, 1,366
catches on 1,368 phase windows, two misses, one give-up and no reset. Separately, the USB data
cable was pulled and replaced while the host slept and the dongle was halting, with the debug probe
still powering the board: the boot count did not move, there was no watchdog recovery, the device
enumerated fresh as a replug should, and the link returned in a second. The fifth gate, a remote
wake driven out of a halt, has since run too (2026-09-11). A Nucleo-U083RC carrying the
OpenController driver stands in for the keyboard MCU on the module's UART, so a keystroke can
originate while the host is asleep and every process on it is frozen. It parks on the USB host at
reset, which drops the 2.4 GHz link and puts the dongle in its bonded camp, where the windowed
receiver engages on the grace rather than on the scheduled-drop detector; it then returns to the
wireless host and presses one key. The host slept at 12:09:35 and woke itself at 12:12:00, 145 s
later, with the wake attributed to `USB2_wake` rather than to the internal keyboard. Across that
episode the dongle logged 330 halts totalling 47.4 s with zero abandoned entries, the stand-in sent
exactly one keystroke, the USB node identity was unchanged, the clock advanced 224.6 s of 224.7 s
of wall time, and the boot count did not move. The halting state there was the camp rather than a
resting production keyboard, but the halt entry, the radio wake and the remote-wake pulse are the
same code on both paths. That emptied the gate list, and the knob was defaulted on the same day.
The entry also carries a known residual: the vendor primitive takes its wait with interrupts
enabled, so a resume arriving inside its prologue is serviced and then slept through, bounded by
the backstop at one second. With the knob off the image is byte-identical and
CH570 is untouched.

## Windowed receiver in the reacquire scan and the terminal camp (CH592)

Against a resting production keyboard the dongle spent ~990 ms of every second in the
reacquire scan to catch a ~10 ms probe that arrives once a second (the keyboard stops its
session 5 s after the last key and reconnects every 1.010 s), and against an absent
keyboard the camp kept the receiver on for nothing; the receiver is about 7 mA of the
dongle's draw. The scan and the camp now open short receiver windows instead: 30 ms on
channel 8 every 200 ms (the production probe sweeps all three pairing channels inside its
~10 ms, so one channel suffices), plus one window a second phase-locked to the resting
keyboard's next probe once a detector has seen two scheduled drops (a short confirmed link
dropped within 300 ms of its promote, ~1 s apart); the radio is shut between windows. A
missed phase window widens the next one and two misses fall back to the continuous scan
until the next promote, restoring continuous reception before the keyboard's third
unanswered probe (which would send it to a sleep stage only its host can end). Acceptance inside a window hands the
radio to the existing accept path untouched. A grace period keeps today's continuous
receiver for a nominal 60 s after a scheduled drop (counted 1.010 s per resting cycle in the
scan and 200 ms per tick in the camp, replenished by an unscheduled loss), so the first key
after a short pause keeps its ~40 ms; the unbonded fresh-pair camp and the 3 s boot window stay continuous.
Knobs `PM_RX_WINDOW` (0 is byte-identical to before), `PM_RX_WINDOW_MS`, `PM_RX_PERIOD_MS`,
`PM_RX_GRACE_S`, `PM_RX_PHASE_MS`; diag page 7 `rx window` counts opens, closes, catches,
phase opens and misses, detector locks and the reasons a drop did not qualify.
Bench (CH592 6308E6D8, production keyboard, grace 0): 297 resting cycles, 297 phase
windows, 297 catches, 0 misses, 0 give-ups, 0 fallbacks; first key after rest 20/20 within
48 ms (40 ms before); cold reconnect at random phases 10/10 within 199 ms; the awake resting
state metered 5.74 mA against 10.67 mA (the same keyboard, one session's scale). With the
build id forced, CH570 and the knob-off CH592 image are byte-identical to before (ordinary
images differ in their identity bytes, since the id hashes the shared sources and flags). Suspend-state core Halt between
windows is the next step; the awake floor with the receiver off is 3.06 mA.

## Connected hop counts the keyboard's edges

The connected data-hop reproduced the recovered dongle rule: reset the anchor to
the poll time, step by elapsed / interval, and when the index landed back on the
previous one force a slot forward and forward-date the anchor. That repeat-correction
is right for a poll a tick early and wrong after a coalesced gap of exactly 5k poll
slots, where the keyboard is already on that channel: the forced slot misses it, the
next poll hops two, and supervision drops the link. Reproduced on the bench by masking
the dongle's interrupts for whole poll slots on a live link (`opendongle --rf-poke
40+N`): 5 and 10 slots dropped the link every time, 1-4, 6-8 and 12 never. The
dongle now keeps the keyboard's model instead: an edge anchor 13 ticks before the
poll it expects, seeded at every re-key, advanced by whole intervals only, the index
by the same count, no correction branch; the modular add subtracts before it adds,
which also closes the 32-bit overflow the old branch had (TODO). Both ends count the
same edges however the polls are spaced. A host test (`firmware/tests/test_hop_model.py`)
pins the model against the keyboard's for every gap of 0..20 slots and 0..27 ticks.
Bench (CH592, 664BA4F5, OpenController as the keyboard): masked gaps of 1..15 slots
and the 5- and 6-slot remainder bands all held the link with 0 lapses; 30 alternating
5/10-slot gaps, 0 lapses; EV10 cadence, reconnect 10/10 at 5 ms, fresh pair and the
poll reply ratio unchanged. Both chips' bytes change; CH570 compiled, not bench-verified.

## EP6 OUT stays live after a dropped IAP packet

The vendor HID interface's OUT endpoint was NAKed unconditionally after every OUT
completion, while only a latched IAP command ever re-ACKed it; a toggle mismatch with
nothing pending therefore wedged the maintenance interface until a bus reset or a power
cycle. That case is reachable by a conforming host: a valid OUT whose ACK is lost on the
bus is retried with the same DATA PID after the command has already run (USB 2.0 8.6.4).
The handler now re-ACKs when nothing was latched and nothing is pending, judging the
toggle from the interrupt-status sample it already took; a latched command keeps the
flow-control NAK that `USB_PollEP6` releases. Not reproducible from the bench host, so
verified as non-regression (pipelined writes answered in order, the maintenance flows
unchanged). Both chips' bytes change; CH570 compiled, not bench-verified.

## Terminal-camp liveness watchdog

Every terminal camp (EV10 give-up, closed boot window, unbonded start) armed RX once
and then leaned on the radio's own events to re-drive it; the arm-status guard that
was meant as the backstop never fires on either radio library, and CH59x basic-mode
RX has no timeout at all, so a lost completion or a deaf PHY left the dongle in
`waiting for reconnect` until a chip reset. The camp now keeps the boot-window timer
slot, free in every terminal camp, as a 200 ms liveness tick. A tick that saw an
RX-side event since the last one leaves the radio alone; a silent tick re-arms RX
from task context (CH59x: every silent tick, since a silent camp is the normal state
there; CH570: the 30 ms camp timeout keeps the counter moving, so a silent tick is a
dead loop and the second in a row escalates to shut + vendor re-init + re-arm, rung 2
of the 0x94 ladder's code path, not bench-verified on CH570 here). The tick self-disables outside the exact terminal camp, and a
restart that lands in a terminal camp without it (the bond-clear tombstone paths) starts
it. The same pass fixed the latent CH570 persist ordering (TODO): the record is validated
before the radio is torn down, not after.
`opendongle --rf-poke 3` is the fault injection (shut the radio, leave it deaf) and
page 1 `camp_wd_rearms` counts the re-arms. Bench (CH592, 4AB7E07F): 5.0 re-arms/s in
the silent keyboard-absent camp; five rung-3 fault injections each read `rx_armed`
false right after and true 0.5 s later, then reconnected in 5 ms, and one left deaf for
1.5 s reconnected the same; three induced EV10 scans at 71 PAIR_PREP runs each
(`hb_stale_drop` 0); bonded reconnect 10/10; three fresh pairs through the unbonded
camp (bond clear, cold boot, factory pair) at 69-71 ms to connected with two pair ACKs
and one bond persist each. CH570 compiles; not bench-verified (no CH570 on this bench).
Bounds: a lost completion is re-armed within two ticks (the tick after the loss may
still read the event that preceded it); rung 3 resets the baseline and is re-armed at
the next tick. Not covered: a CH570 PHY that keeps raising its 30 ms timeouts while
receiving nothing looks alive to this test (TODO).

## Link order pins the CH592 radio path

The poll reply ratio (replies received over the keyboard's replies sent, the page-1
oracle) moved by up to 0.3 % between builds that changed nothing on the poll path:
a `volatile` on a diagnostics block, a comment-sized edit to the idle code. The map
explained it: the RAM-code image was loaded ahead of flash `.text`, so every RAM-code
edit shifted the whole BLE library, and the library's sections were linked after every
application function, so every application edit shifted them too; the poll path runs
mostly from flash (`RF_Rx`/`RF_Tx`/`RF_Shut`, the library's receive and transmit
processing, TMOS, and the application's dispatch and poll functions). `link.ld` now
links the radio path first, the BLE library and then the application's flash-resident
poll-path functions, and loads the RAM-code image after `.text`. The library's
addresses are then identical across RAM-code and application perturbations (`RF_Rx`
at 0x3cee in every variant), and the pinned application functions move only when a
function ahead of them in that list changes. The image is 68 bytes smaller: the
linker relaxes 22 library-internal calls to `c.jal` from the new proximity, which is
also why the byte-identity gates do not apply across this change; the gate for a
link-order change is the symbol set with sizes (identical) plus the bench oracles.
`TEXT_PAD=N` (Makefile, default 0, N even) shifts flash `.text` by N bytes for
placement experiments, rounded up to the first pinned section's alignment (read
`RF_Rx` in the map); the flash-fetch period behind the effect is not established.

## Power management (CH592, Tier 1): main-loop idle, GPIO park, clock gates

The CH592 product build no longer busy-spins its 60 MHz core. `Main_Circulation` now
idles with a SEVONPEND/WFITOWFE wait under the global mask (the form OpenController
proved on the same silicon; a plain masked WFI never wakes here), bounded by TMR3 at
the lowest interrupt priority, and woken by the radio (BLEB/BLEL), TMR0, USB and TMR3.
TMR3 is armed per sleep to the next application TMOS deadline (`PM_EXACT_DEADLINE=1`,
the default): the CH592 timing seam records every application timer start in a
table on the RTC counter TMOS itself compares against, retires an entry once a sleep
decision finds it already due at the previous decision's clock read with nothing
dispatched since (the scheduler passes between two decisions dispatch every expiry
TMOS had posted), and the idle path programs TMR3 to fire one 625 us unit after
the nearest entry, or at `PM_DEADLINE_CAP_US` (20 ms) when none is nearer, which
bounds the library's own timers (its 1 s temperature sample, the 120 s calibration).
An application timer therefore waits at most one TMOS unit of idle-induced wake
latency (plus the foreground and scheduler passes it always ran behind), a library
timer at most the cap plus the same passes, and the heartbeat interrupt runs about fifty times a second
instead of a thousand when no application deadline is nearer than the cap (an
application timer due sooner arms it sooner; on a live link TMR0 wakes the core
first and the heartbeat hardly fires at all). `PM_EXACT_DEADLINE=0` restores the fixed 1 ms period
(`PM_HEARTBEAT_US`) byte for byte. Measured back to back on the devboard (inline
meter on the probe rail, same hour, 60 s averages): keyboard absent with the host
asleep, the overnight state, 9.910 -> 9.773 mA (-0.14 mA, the heartbeat ran at
~50/s instead of 1000/s through the sleep); keyboard absent with the host awake
10.907 -> 10.842 mA; connected, awake 10.836 -> 10.83 mA and connected, host
asleep 10.694 -> 10.716 mA (equal within noise: there TMR0's 875 us poll cycle
wakes the core whatever the heartbeat does).
The radio is never slept, the protocol bytes and timer settings are unchanged (the
measured poll cadence stays within 1 % of baseline), the flash stays powered, USB
suspend and remote wake keep working, and the DC-DC is never enabled (the board has no
inductor). Build knobs (`firmware/ch592/Makefile`, all `-D` flags hashed into the
build id and named in `CONFIG_TEXT`, schema 12 as of the exact-deadline change): `PM_IDLE` (1), `PM_IDLE_LEVEL`
(3 = idle in every RF state: 1 = keyboard-absent camp only, 2 = every pairing
sub-mode + idle), `PM_IDLE_IN_SUSPEND` (1), `PM_GPIO_PARK` (1), `PM_CLK_GATE` (1, see
below) with `PM_CLK_GATE_MASK` (19958 = 0x4DF6), `PM_USB_DIGIN_OFF` (0),
`PM_HEARTBEAT_US` (1000), `PM_EP0_QUIET_MS` (200). Building with the seven switches at
zero (`PM_IDLE=0 PM_IDLE_LEVEL=0 PM_IDLE_IN_SUSPEND=0 PM_GPIO_PARK=0
PM_USB_DIGIN_OFF=0 PM_CLK_GATE=0 PM_RX_WINDOW=0`; the period and mask knobs keep their
defaults; `PM_RX_WINDOW` joined the set with the Tier 2 windowed receiver)
produces an image byte-identical to the pre-change firmware (verified with a forced
build id), and the CH570 image is untouched. New IAP 0x92 pages 5/6 ("power")
expose idle duty, wake attribution (radio / TMR0 / TMR3 / USB), the veto histogram,
stale-interrupt clears and the clock-gate word; `opendongle --diag` decodes them.

Bench ladder, 2026-09-06, WeAct CH592F devboard, meter inline on the probe's 3V3 feed
(the board's only supply, so whole-dongle current), 90 s min/avg/max per reading,
every rung compared against a same-day all-off baseline because the bench had
shifted 0.75 mA overnight:

| Scenario | all-off baseline | plumbing (level 0) | + GPIO park | idle level 1 | idle level 3 | + clock gates (shipped) |
|---|---:|---:|---:|---:|---:|---:|
| Connected, idle | 13.26 | 13.55 | 13.03 | 13.16 | **10.87 (-18%)** | 10.62 |
| Connected, ~9 keystrokes/s | = idle | | | | 10.93 | |
| Bonded, keyboard absent (search) | 15.90 | 15.64 | 15.68 | **10.41 (-35%)** | 10.39 | 10.13 |
| Host USB suspended, link up | 13.23 (day 1) | | | | 10.71 | |

What the rungs taught: the heartbeat plus the per-pass idle logic cost +0.29 mA while
the core still spins, and a later A/B/C in the keyboard-absent camp (1 ms heartbeat
10.931 mA, 10 ms 10.819 mA, none at all 10.796 mA) showed that cost is the interrupt
itself, about 0.13 mA per thousand a second, while TMR3's 60 MHz counter is free, which
is why the exact-deadline mode keeps the timer and only stops firing it periodically; the GPIO park is worth -0.52 mA on the
devboard (floating header pads); idle removes the core-spin share in every state;
keystrokes cost nothing measurable. Per-rung gates (all pass on the shipped build):
poll rate one per 875 us within 1% of baseline, 0 supervision lapses / EV10 entries /
reboots over a 10 min connected soak, bonded reconnect from the idle camp 10/10 at a
55 ms median (baseline 52), fresh pair 10/10 with the durable bond persisted, LED
relay 10/10 end to end, USB re-enumeration 40/40 with the link re-formed, bootloader
entry from a live link, USB suspend with remote wake armed, wake attribution proving
the radio interrupt ends the masked idle (0 radio wakes with the keyboard absent).

Findings folded in during validation:
- The BLE library's 1 s temperature sample leaves the read-only ADC EOC flag set, so
  IRQ 29 reads pending forever and the strict alien-interrupt veto held idle at 0 %
  until `pm_irq_pending` learned to clear it (page 6 `stale_adc`).
- Idling during the fresh-pair ACK burst / confirm-before-persist phase lost the
  confirming packet on 3 of 15 pairs (durable bond write deferred) against 0 of 10 on a
  never-idle control; those phases now veto idle at every level (they last < 1 s).
- The three OS-polled HID IN endpoints (1 ms interval) wake the core ~3000/s while the
  host is awake (NAKed IN tokens pulse the USB IRQ), capping awake idle duty near 86 %
  in the camp and ~38 % on a live link; gone during suspend.
- Clock gating (`PWR_PeriphClkCfg(DISABLE, 0x4DF6)`: TMR1/2, UART0-3, SPI0, PWMX, I2C,
  LCD) saves a further ~0.25 mA in every state and ships on by default (`PM_CLK_GATE=1`,
  mask knob `PM_CLK_GATE_MASK`). It first shipped opt-in because a morning A/B on the
  absolute receive-restart rate read 1.6 % lower with the gates on and an afternoon
  bisect could not name a block. Re-measured 2026-09-09 with the page-1 reply-ratio
  oracle (replies received over the keyboard's replies sent, 30 s runs, interleaved
  flashes): the gates cost about 0.2 % of poll replies, not 1.6 % (the old oracle
  counted the downlink's own loss too, which is the likely rest), and the same binary
  with an empty mask reads like the ungated one, so the register write, not code
  layout, carries it; each half of the mask (TMR1/2 + UARTs, and SPI0/PWMX/I2C/LCD)
  carries about 0.15 % on its own, so no single block explains it. The mechanism is
  not established; a supply effect of the gated current is the guess. A missed reply costs the
  keyboard one 875 us poll of latency on that report; the 0.25 mA is 2.3 % of the
  connected draw. `PM_CLK_GATE=0` restores the ungated image.
- On this Mac the CH592 OpenBoot USB bootloader attaches but never binds as an HID
  device, so `opendongle --enter-bootloader` + `openboot flash` cannot update the
  CH592 dongle from macOS; every rung was flashed over SWD (`make ch592-factory-flash
  ... ALLOW_BONDED_FLASH=1`, the bond survives `-E`). Recorded as a separate bug.

## Boot architecture: OpenBoot

The dongle boots via the [OpenBoot](../third_party/openboot) bootloader (pinned
submodule): bootloader at `[0x0000,0x2000)`, application at `0x2000`, a boot
record in the top erase block of each A/B slot, and updates performed **inside
the bootloader** over its OBP USB protocol. The bootloader re-enumerates under
the dongle's own `0C45:FEFE` identity, told apart from the application by its
vendor HID usage page `0xFF00` (the application uses `0xFFFF` and `0xFF60`), and
the flash returns it to the application. See [BOOT.md](BOOT.md) for the flash maps, the
boot-record semantics, the update/factory/recovery flows, and the honest caveats
(fail-stay after an abandoned session; wrong-family protection is host-side).

Behavioural properties worth knowing:

- Two different interruptions have two different outcomes; they are not in
  conflict, but they are easy to confuse:
  - **The transfer dies** (host crashes, cable pulled, power cut mid-write).
    The unit comes back **running the previous application**: mutations target
    the inactive slot, so the running image is never touched and BOOT falls
    back to it. Retry the flash.
  - **A session is opened and then abandoned** (a successful HELLO, then the
    host walks away without flashing or sending BOOT). The unit **stays in the
    bootloader** — a HELLO suppresses idle auto-boot until reset, which is the
    fail-stay rule. Power-cycle it, or end scripts with an explicit
    `openboot boot`.
- A factory image carries slot A's boot record, so a blank part boots the
  application on first power-on with no host and no bless step. On a blessed
  unit `openboot bless` is not merely unnecessary but impossible: the device is
  `active=A, write=B`, and bless resolves against the write slot.
- What the boot-time CRC proves is narrower than it looks: the record stores a
  length and a CRC over that many bytes from the slot base, so it is protection
  against accidental corruption, not an identity check. `BOOT.md` states the
  exact rule.
- `OB_IDLE_TIMEOUT_MS` is now **real milliseconds**. The boards' unchanged
  `10000` means 10 seconds, where it previously bench-measured ~273 s on CH570
  and ~86 s on CH592 — the value did not move, its meaning did. Anything that
  waited out the old window is ~27x too slow.
- Finish an SWD factory flash with a real power cycle, not `minichlink -b`:
  `-b` resumes the core instead of resetting through the boot path, so the boot
  decision never re-runs from a cold start. `flash-factory` does this for you.
  Established by controlled comparison on a CH570 — same part, same bytes, same
  SWD path, only the final step differing: with `-b` nothing enumerated at all,
  with a real power cycle the application came up and ran.
- Hardware validation after the A/B adoption, on a CH570 taken from blank
  silicon to a working dongle: bootloader and application USB enumeration under
  `0C45:FEFE` with usage-page disambiguation, OBP 0.2, on-silicon slot geometry
  and the bond clamp (`write window 0x2000..0x1D000` as reported by the device
  itself), the dry-run/`--force` flash path, `--enter-bootloader`, the 10 s
  idle auto-boot, and factory-blessed first-power-on boot. Product level:
  pairing, typing, media keys, indicator LEDs, reconnect and sleep/wake.
  CH592 covers the same protocol and geometry over UART plus a verified COMMIT.
- **The A->B slot transition is validated on hardware** as of the dual-slot
  build. A CH570 was taken through a full A->B->A round trip over USB with the
  real application, using a `.obb` bundle:

  | step | device reported | bundle selected |
  |---|---|---|
  | start | `active A, writing B`, window `0x1E000..0x39000` | slot B, crc32 `0x893FE89B` |
  | after | `active B, writing A`, window `0x2000..0x1D000` | slot A, crc32 `0xD7958914` |
  | after | `active A, writing B` | — |

  The running build id matched the selected slot's image each time
  (`0x44126E29` for slot B, `0x9F666DEE` for slot A), so the variant really was
  chosen by the device's `write_base` rather than assumed. **The RF bond
  survived both updates** - it sits at `0x3A000`, which is exactly
  `OB_APP_END`. That bound is exclusive, so the writable region is
  `[0x2000, 0x3A000)` and the bond is the first address outside it; OBP cannot
  reach it.
- **Still not validated on hardware: the interrupted-update paths.** Upstream's
  bench harness reaches the bootloader through a CDC-open target reset that this
  bench does not exhibit. That is a limitation of OpenBoot's test code, not the
  product: a source audit of `firmware/core/`, `ports/` and `transports/`
  against every hardware observation found no bootloader defect.

## Pair-acceptance RSSI floor: -75 -> -90 dBm

The fresh-pair path (and a boot-window accept of a *different* keyboard) is
gated on received signal strength. A bonded keyboard reconnecting is **not**
gated, so this only ever affected pairing.

**-75 had negative margin at the distance the product is for.** Bisected with
diagnostic builds against stock v0.96.15 with a bonded link: -128 accepted,
-90 accepted, -82 accepted, **-75 rejected**. The keyboard's pair broadcast
therefore arrives at roughly -81..-76 dBm with both boards on one bench, so a
dongle behind a PC case or across a desk sits in that band or below — the
shipped default was rejecting its own primary scenario.

**-90 keeps what the gate is for.** Its purpose is stopping an unprovisioned
dongle auto-pairing with a distant keyboard in a dense environment. At 2.4 GHz
a cross-room signal (several metres plus a wall) generally lands below -90
while same-room stays above, so this keeps the "not the neighbour's office"
property with ~10 dB of margin over what was measured.

Two things to be honest about:

- **The bracket is bench-specific.** It reflects one geometry and one pair of
  boards. Before this ships, re-measure at the intended worst case — dongle on
  a rear I/O port, keyboard at arm's length. If that lands below -90, prefer
  -95 over deleting the gate.
- **The gate is a heuristic, not a security boundary.** CH59x RSSI is coarse
  and uncalibrated chip to chip, so the same number means different real
  distances on different units, and the CH570 SKU is reported to run with it
  effectively inert (constant RSSI byte) — the product line already tolerates a
  no-gate configuration.

If mispairing in dense environments ever becomes a real complaint, the fix is
**not** a tighter floor: it is strongest-candidate selection — briefly collect
broadcasters during pairing and take the highest RSSI, keeping this only as a
sanity floor. An absolute threshold encodes antenna and geometry assumptions;
relative selection targets the actual failure mode.

Two supporting changes ship with it. `opendongle --info` now reports the last
RSSI the RF task saw, so re-measuring needs one command rather than a bisect
over four diagnostic builds; and the floor is overridable per build
(`make -C firmware ch592 PAIR_MIN_RSSI=-95`, or `ch570`) so bench profiles do
not need a source edit.

**This does not address the keyboard-reset-recovery regression** (EV10
reacquire gating out rebooted keyboards). That is a separate v0.96.x fix, and
both want the same bench re-validation pass.

## Bonded reconnect vs the OpenController MR4 receive window

A bonded CH570 dongle that has not connected since it booted did not complete
the OpenController keyboard's bonded reconnect, and neither did one that had
settled into its channel-8 camp after an EV10 give-up on the first try. The
keyboard side saw ~500 clean beacons in 10 s and zero valid frames; the dongle
side heard and accepted every beacon it caught, transmitted its LEN-15 reply,
promoted to CONNECTED, lapsed for want of a poll response and relistened,
indefinitely. A fresh pair recovered it; nothing else did. Bench 2026-09-04,
three consecutive cold boots, measured with the RF diagnostics page proposed in a separate draft PR.

**Mechanism.** The reconnect reply is scheduled `RF_CH570_PAIR_ACK_PRE_TX_TMOS`
= 4 x 625 us after the beacon (software-measured: 2538..2551 us from accept
to StartTx returning, ~214 us from there to the TX-finish callback), the
value chosen for the Bridge75 stock keyboard. The OpenController's power-MR4
bonded search arms its receiver ~0.2 ms after each beacon and closed it
2.5 ms later -- consistent with the reply completing on that closing edge.
Its window had been sized against the dongle's EV10 reacquire path, whose
reply comes ~0.3 ms after the beacon and which a dongle only takes once it
has connected at least once since boot -- so every earlier measurement, made
against a warm dongle, passed.

**Resolution.** On the keyboard side: OpenController widens the window to
6 ticks (3.75 ms), leaving ~1 ms of completion margin. This dongle's timing
is unchanged; the bound the keyboard must respect is now documented at the
constant. The dongle-side alternative (reply at 1.875 ms) was bench-proven
too (6/6 cold-boot reconnects, 5/5 after a give-up) and not taken, because
the source records it as measurably worse for the Bridge75.

**Two things to be honest about.**

- The 0.2 ms keyboard arm latency is an estimate; what is established is the
  A/B: a 4-tick window passes 0/8 (fails 8/8) and a 6-tick window passes, and a 1.875 ms
  reply passes against a 4-tick window. The exact cross-device edge was not
  measured with a sniffer.
- A second failure of a different shape was seen once on the same day and is
  NOT covered by this: a dongle up for two days answered neither keyboard
  build (including a continuous-RX build that catches the reply above) and was
  cured only by a power cycle. It predates the diagnostics page and is
  uncharacterised; `TODO.md` records the structural hole it matches (the
  terminal camp has no time-based liveness backstop). The RF diagnostics page
  and intervention ladder in the separate draft PR exist to characterise it
  when it recurs.
## Diagnostics: RF page (IAP `0x92`) and intervention ladder (`0x94`)

Page 1 (PHY counters: RX arms and failures, RX done / CRC error / timeout, TX
start / fail / done, shut calls, last status bytes) is now live on CH592 as well;
it used to read as zeros there. The `tx_done` / `rx_done` pair is the poll
reply-rate oracle: on CH592 a missed reply raises no event, so it shows only as
`rx_done` falling behind `tx_done`.

`opendongle --diag` reads five 62-byte pages over the vendor HID interface
without arming a maintenance session: the runtime snapshot (state, channel,
the access address in RAM against the one the radio was last armed with,
last RX/TX/shut status, an RX-armed latch, peer MAC, last beacon disposition,
last persist outcome), the PHY and executor counters (RX arm attempts and
failures, RX done/CRC/timeout, TX start/fail/done, the pending event mask,
both delayed-post slots, every timer slot's remaining time), the protocol
counters (beacons seen and accepted or rejected with the reason, reply
scheduled/started/finished, EV10 entries and give-ups, promotes, relistens,
confirm and persist outcomes, reply latency) and the radio internals (LLE/BB
interrupt counts, a free-running SysTick timebase with stamps, the LLE/BB
registers read through the vendor library's own base pointers, its receive
state, the radio IRQ enable bits, USB suspend episodes). Counters wrap; the
tool prints per-second rates between samples. A healthy reconnect camp reads
as RX re-armed ~33/s on its 30 ms timeout with the radio address equal to
the bond's; a deaf one is told apart by which of those stops.

`opendongle --rf-poke 1|2` (armed) re-arms the receiver from task context, or
shuts, re-runs the vendor init and re-arms. It is refused unless the dongle is
in its exact terminal camp, and it exists to tell a dead software loop from a
deaf PHY in place, without a debug probe (which on CH570 shares the USB pins).

Honest limits: the counters are best-effort (no locking; a sample may straddle
an event); the LLE/BB register meanings come from the linked library's
disassembly, not from documentation; the SysTick stamps wrap every 42.9 s;
`0x92` costs one EP6 exchange per page, which stalls the RF pump for
milliseconds, so it is not for use inside a latency measurement. Footprint on
CH570: ~2.9 KB flash, ~0.6 KB RAM, within the 0x800 stack floor.

## Security property: the RF link provides no confidentiality

The Bridge75 2.4 GHz data path applies **no confidentiality protection**, by
design and for wire compatibility with the production keyboard. Specifically:

- The per-session access address is sent in **cleartext** in the pair-ACK on the
  well-known pairing address.
- The 5-channel frequency-hop schedule follows **deterministically** from a known
  constant.
- HID reports travel **verbatim** on the link (`rf_protocol.h`, `rf_task.c`).

The prebuilt vendor BLE archive contains cryptographic and SMP routines, but this
product uses raw `RF_Rx`/`RF_Tx` and never invokes them. An attacker within radio
range can recover keystrokes. This is a property of the wire protocol, not a
defect to be fixed in this firmware — fixing it would break interoperability with
the production keyboard. It is stated here so it is an explicit, accepted property
rather than an implicit one.

## USB suspend: mouse and consumer reports no longer replay on resume

The suspend handler used to NAK only the boot-keyboard endpoint (EP1) when the
host stopped SOF. A mouse (EP2) or consumer/media (EP3) report armed in the last
poll interval before suspend stayed armed across the whole episode and was
handed to the host on its first IN poll after resume. HID reports are
change-driven, so the matching release, arriving over RF during suspend, was
correctly dropped while the press survived: the host resumed with a stuck button
or a held media key until the next real report from that device. The suspend
branch now NAKs EP1, EP2 and EP3 alike, masking only the response bits so the
data toggle is preserved (the host never received the NAK'd report, so its
expected toggle is unchanged). The NAK alone would only trade the glitch for its
mirror image (a *release* armed when SOF stopped would now be the report that
never arrives), so on the resume edge the main loop also sends a mouse all-up
report with zero motion and a consumer no-key report, the same reconciliation
the keyboard gets from its keys-up flush; the next real report re-asserts
whatever is still held. A fresh report that reaches the endpoint first, in the
window between the resume interrupt and the main loop, cancels the flush for
that endpoint (it carries the device's whole current state), so a press that
lands right at resume is neither dropped nor released by the flush; the keyboard's
own resume delivery (the stashed waking keystroke, or keys-up) is gated the same
way, so a report armed after resume outranks the stash. On Linux the
no-key report also resets the retained consumer report, which would otherwise
suppress the next identical press; the one residual is a fresh consumer report
of that same usage arriving inside the resume window, in which case the host
never sees the no-key report and that press is suppressed until any other
consumer report arrives. Mouse and consumer
reports remain drop-on-suspend (no stash); only the keyboard's waking keystroke
is preserved. Changes the image on both chips.

## Known issues

**CH592: rare fatal fault under a reset during BLE activity.** Under a debug
attach (a halt-and-reset) while the BLE stack is active, the CH592 can take a
fatal fault inside the vendor TMOS layer (`mcause` load fault/misalign, `mepc` in
`TMOS_SystemProcess`/`tmos_proces_system_time`). It is characterised but not
root-caused, and it lives in the prebuilt BLE archive, not in OpenDongle code.
Accepted because:

- the only observed trigger is a reset landing during BLE activity, which a
  **debug attach** produces and a production unit — which has no debug access —
  cannot;
- plain power-rail cycling is clean (10/10 in the characterisation run, and a
  50-cycle soak on the shipped configuration);
- the fault **self-recovers** through the firmware's one-permitted-software-reset
  path (`last reset software`, `boot count` advances, `action recovered`), and a
  real power cycle clears the retained record entirely.

Repeated events within a single power cycle can still reach the fault handler's
repeat fail-stop state rather than recovering; a power cycle clears it. The
application's own reboot-into-bootloader path (vendor HID command `0x85`)
quiesces the radio before resetting, specifically to keep that reset away from
live BLE activity.

## Manufacturing / provisioning duties

**Clear the bond before shipping a CH592 unit.** The CH592 factory flash cannot
erase the bond — it lives in DataFlash, which the probe's whole-chip erase does
not reach — so `make ch592-factory-flash` **fails** if a `BOND` record survives,
and points you at clearing it over the vendor HID interface (command `0x89`). A
shipped unit must not carry a test fixture's pairing identity.
`ALLOW_BONDED_FLASH=1` overrides the check for a deliberate reflash of a bonded
development unit. On CH570 the bond is in code flash and the factory erase clears
it, so a factory-flashed CH570 always needs a fresh pairing.

**Recovery is USB ISP or the bootloader on production hardware.** SWD recovery
was validated on the devboard only. On the production keyboard `PB15` is tied to
GND (it is also TCK), so two-wire debug is unavailable; a stuck production unit is
recovered via USB ISP (`wchisp`) or, if the application still answers, by
rebooting into OpenBoot and flashing from there:

```sh
opendongle --enter-bootloader --image <slot-a>.bin
openboot --vid 0x0C45 --pid 0xFEFE flash <chip>-product.obb --force
```

**Flash the bundle, not a bare `.bin`.** Under A/B the device refuses an image
whose base is not its current `write_base`, and which slot that is depends on
how many times the unit has been updated — so a bare `.bin` is right only by
luck. The `.obb` carries both per-slot builds and the CLI picks the matching
one. (`--image` on the first command still takes a plain `.bin`: it is only
read host-side for the family guard, never flashed.)

Naming the image on the first command is what engages the wrong-family guard,
which compares the image's ODG2 family against the running application before
the reboot — the only point at which that check is possible. Plain
`opendongle --enter-bootloader` is also accepted and reboots the unit, but with
no image to compare it performs no family check.

On CH570 specifically, the debug pins *are* the USB pins: a USB-attached device
has no SWD, and an SWD session is usable only between a whole-chip erase and the
first boot.

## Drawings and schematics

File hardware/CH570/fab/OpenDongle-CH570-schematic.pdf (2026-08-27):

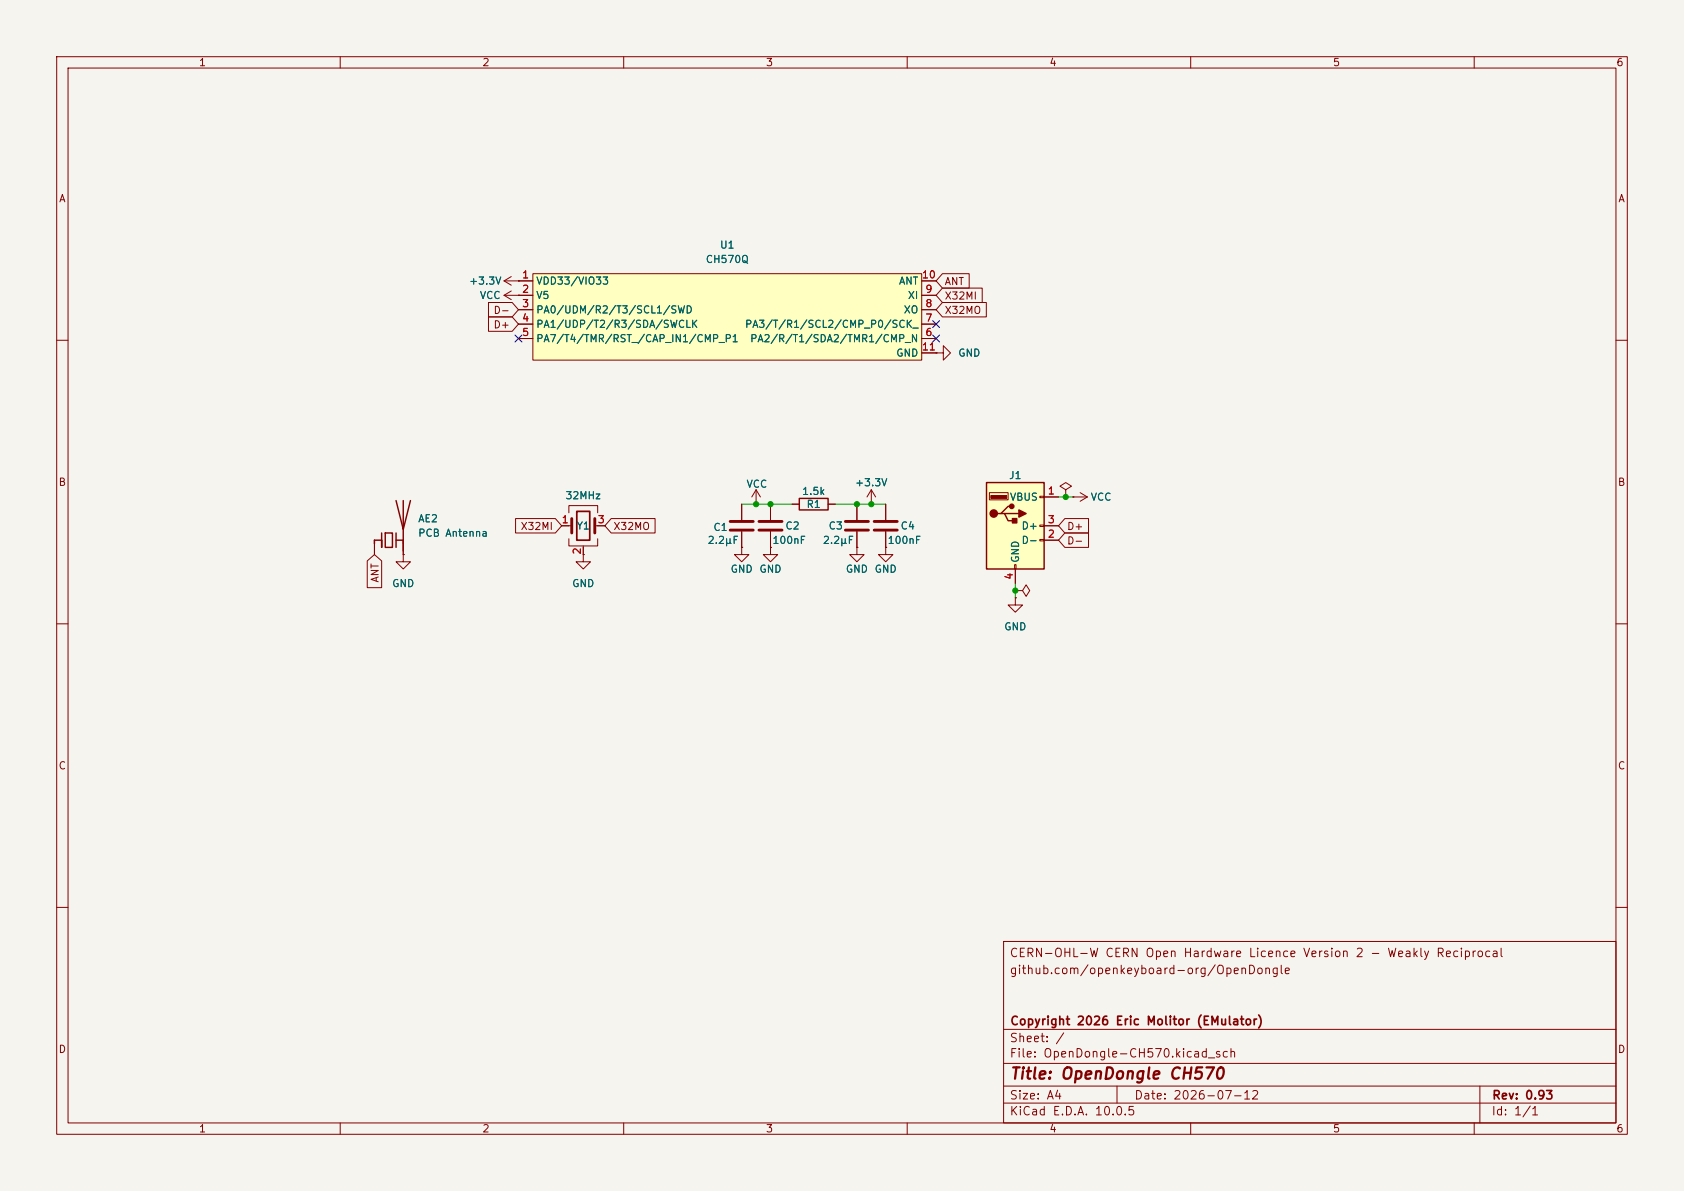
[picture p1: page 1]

CERN-OHL-W CERN Open Hardware Licence Version 2 - Weakly Reciprocal
github.com/openkeyboard-org/OpenDongle

Copyright 2026 Eric Molitor (EMulator)
Sheet: /
File: OpenDongle-CH570.kicad_sch
Title: OpenDongle CH570

Size: A4 | Rev: 0.93
KiCad E.D.A. 10.0.5 | Id: 1/1

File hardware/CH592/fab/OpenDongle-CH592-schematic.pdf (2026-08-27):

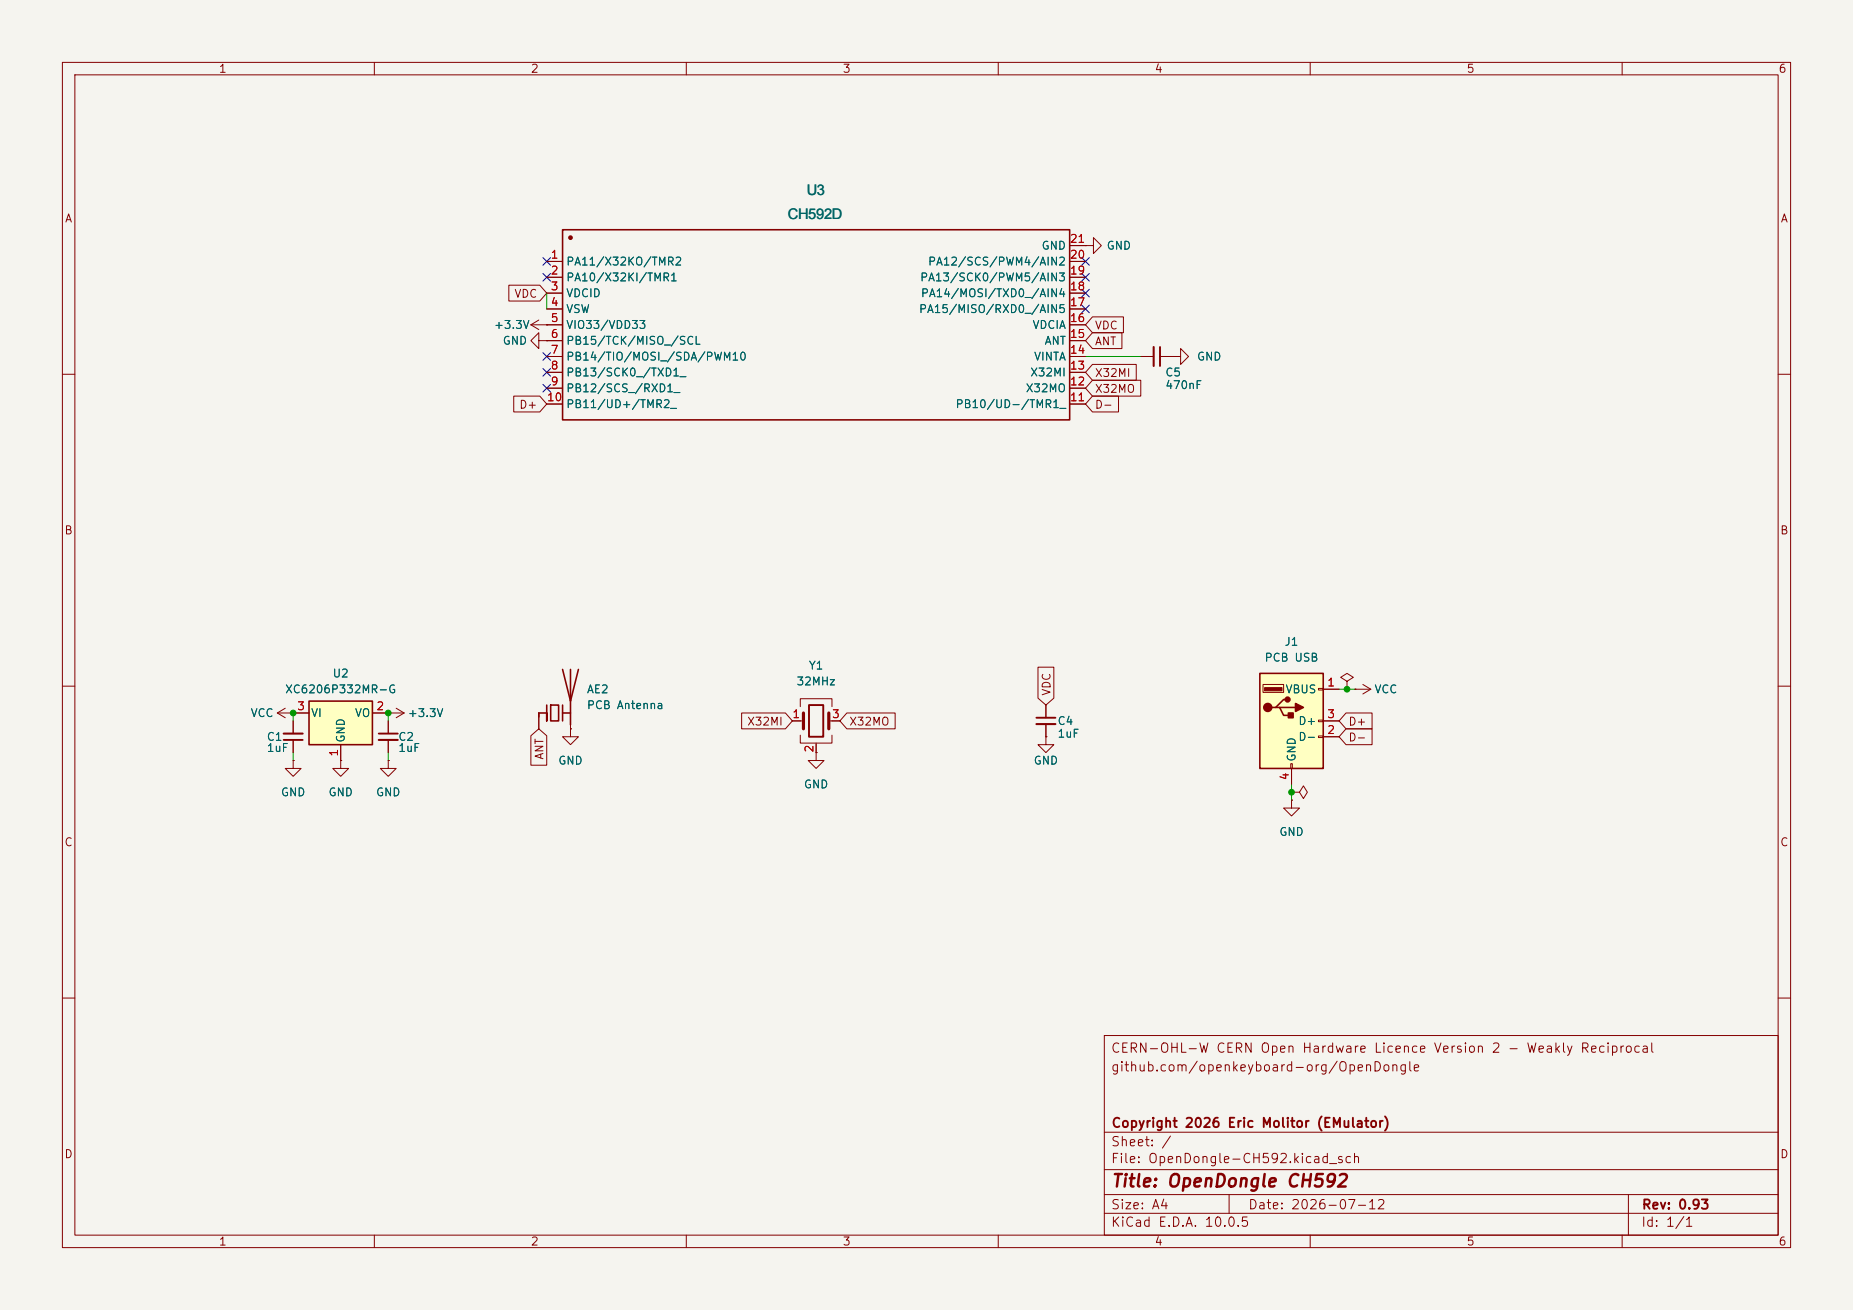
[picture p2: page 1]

CERN-OHL-W CERN Open Hardware Licence Version 2 - Weakly Reciprocal
github.com/openkeyboard-org/OpenDongle

Copyright 2026 Eric Molitor (EMulator)
Sheet: /
File: OpenDongle-CH592.kicad_sch
Title: OpenDongle CH592

Size: A4 | Rev: 0.93
KiCad E.D.A. 10.0.5 | Id: 1/1

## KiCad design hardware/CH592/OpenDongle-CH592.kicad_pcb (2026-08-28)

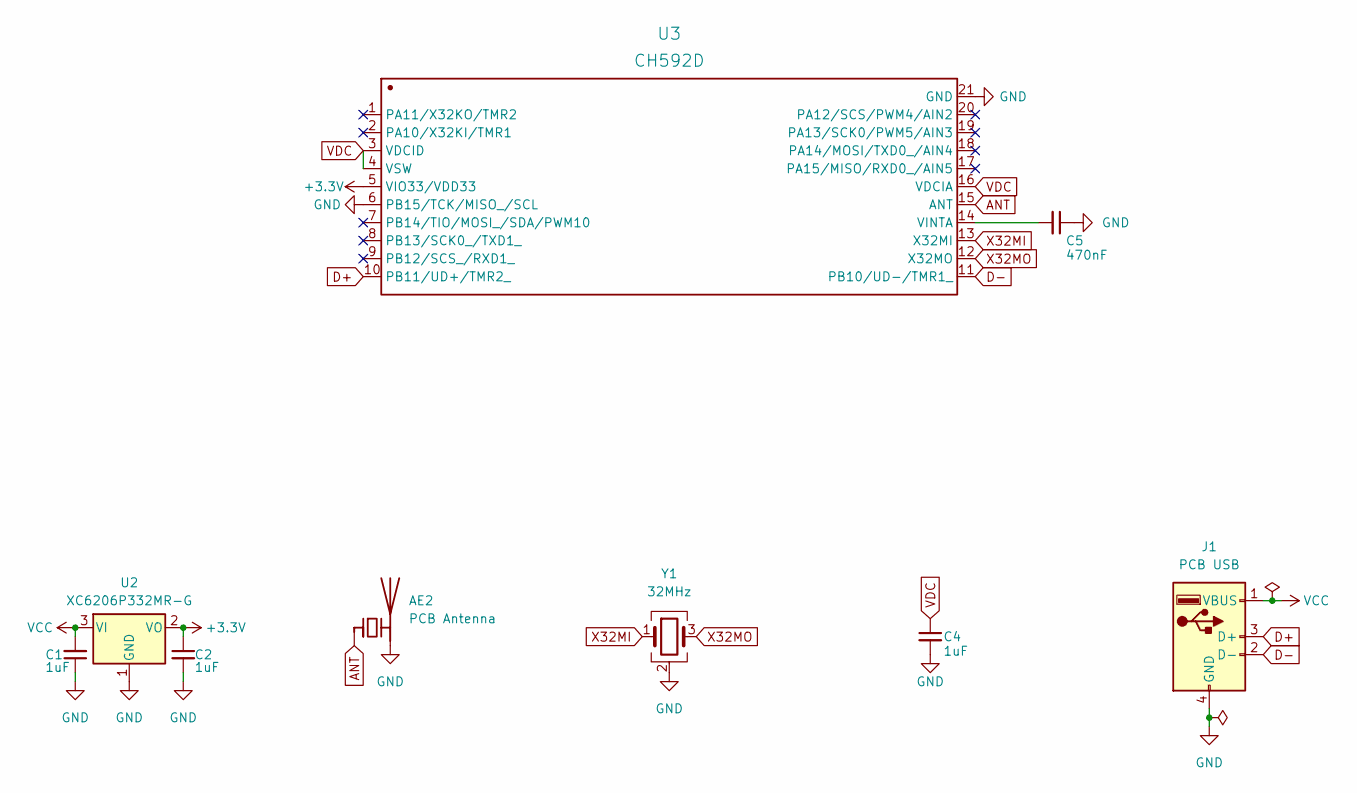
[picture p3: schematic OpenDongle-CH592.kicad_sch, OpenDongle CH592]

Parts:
AE2: PCB Antenna; ANT-F-2-2.4G-0.8MM-FR4-WCH
C1, C2, C4: 1uF; C_0603_1608Metric; LCSC C15849
C5: 470nF; C_0603_1608Metric; LCSC C47339
J1: PCB USB; usb-PCB
U2: XC6206P332MR-G; SOT-23-3; LCSC C5446
U3: CH592D; QFN-20-1EP_3x3mm_P0.4mm_EP1.65x1.65mm; Manufacturer Part CH592D; LCSC Part C41417128
Y1: 32MHz; Crystal_SMD_3225-4Pin_3.2x2.5mm; LCSC C7294588

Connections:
+3.3V: C2.1, U2.2 (VO), U3.5 (VIO33/VDD33)
ANT: AE2.1 (FEED), U3.15 (ANT)
D+: J1.3 (D+), U3.10 (PB11/UD+/TMR2_)
D-: J1.2 (D-), U3.11 (PB10/UD-/TMR1_)
GND: AE2.2 (PCB_Trace), C1.1, C2.2, C4.2, C5.1, J1.4 (GND), U2.1 (GND), U3.6 (PB15/TCK/MISO_/SCL), U3.21 (GND), Y1.2 (G), Y1.4 (G)
unnamed: C5.2, U3.14 (VINTA)
VCC: C1.2, J1.1 (VBUS), U2.3 (VI)
VDC: C4.1, U3.3 (VDCID), U3.4 (VSW), U3.16 (VDCIA)
X32MI: U3.13 (X32MI), Y1.1
X32MO: U3.12 (X32MO), Y1.3

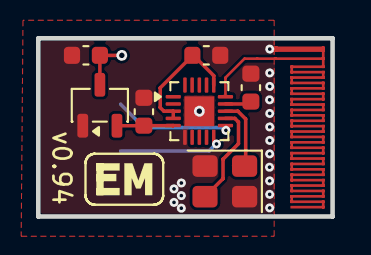
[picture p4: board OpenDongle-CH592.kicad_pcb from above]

Board: 2 copper layers, 16.3 x 9.9 mm, 9 parts (1 on the bottom side), 10 nets.

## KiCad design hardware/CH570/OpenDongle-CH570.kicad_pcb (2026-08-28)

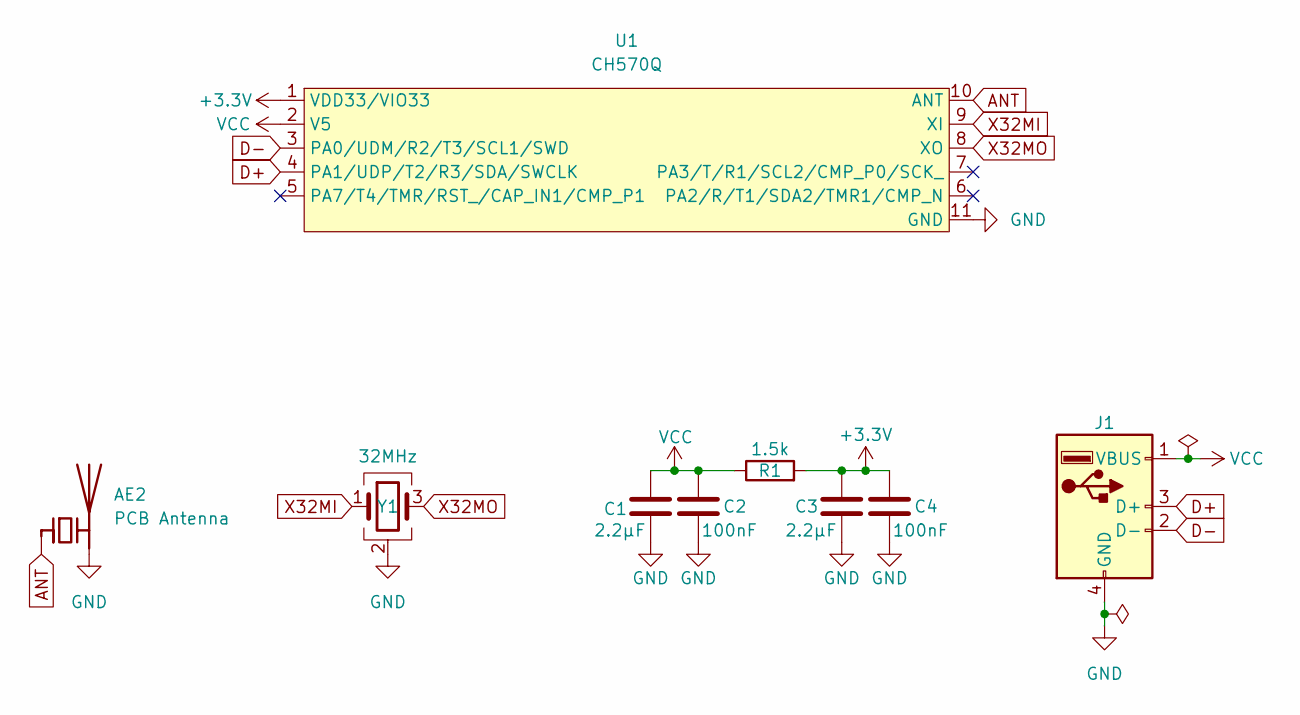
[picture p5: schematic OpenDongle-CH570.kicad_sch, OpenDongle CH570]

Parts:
AE2: PCB Antenna; ANT-F-2-2.4G-0.8MM-FR4-WCH
C1, C3: 2.2µF; C_0603_1608Metric; LCSC C23630
C2, C4: 100nF; C_0603_1608Metric; LCSC C14663
J1: PCB USB; usb-PCB
R1: 1.5k; R_0603_1608Metric; LCSC C22843
U1: CH570Q; DFN-10-1EP_3x3mm_P0.5mm_EP1.7x2.5mm; LCSC C49260680
Y1: 32MHz; Crystal_SMD_2016-4Pin_2.0x1.6mm; LCSC C37635332

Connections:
+3.3V: C3.1, C4.1, R1.2, U1.1 (VDD33/VIO33)
ANT: AE2.1 (FEED), U1.10 (ANT)
D+: J1.3 (D+), U1.4 (PA1/UDP/T2/R3/SDA/SWCLK)
D-: J1.2 (D-), U1.3 (PA0/UDM/R2/T3/SCL1/SWD)
GND: AE2.2 (PCB_Trace), C1.2, C2.2, C3.2, C4.2, J1.4 (GND), U1.11 (GND), Y1.2 (G), Y1.4 (G)
VCC: C1.1, C2.1, J1.1 (VBUS), R1.1, U1.2 (V5)
X32MI: U1.9 (XI), Y1.1
X32MO: U1.8 (XO), Y1.3

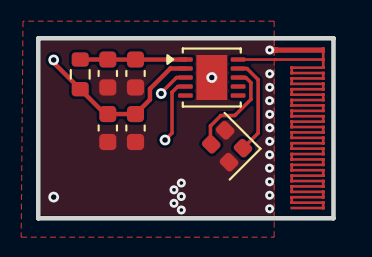
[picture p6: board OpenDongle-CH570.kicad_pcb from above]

Board: 2 copper layers, 16.4 x 10.0 mm, 9 parts (1 on the bottom side), 8 nets.

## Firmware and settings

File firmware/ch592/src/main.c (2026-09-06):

/*
 * OpenKeyboard.org OpenDongle
 * Copyright 2026 Eric Molitor (EMulator)
 * SPDX-License-Identifier: Apache-2.0
 * Target: WCH CH592F (QingKe RISC-V4F, 60MHz)
 *
 * Build requirements (verified 2026-05-17 via ch592f-irq-test/wch-rfphy-rebuild):
 *
 *   The CH59x BLE library (LIBCH59xBLE.a) is compiled with WCH's custom
 *   `WCH-Interrupt-fast` interrupt attribute and depends on the specific
 *   register-save/restore behavior it produces. Mainline GCC's plain
 *   `__attribute__((interrupt))` (what INT_SOFT=1 selects) produces a
 *   binary that wedges before any IRQ can be delivered. Only the MRS
 *   toolchain (riscv32-wch-elf-gcc 15.2; see firmware/README.md)
 *   supports `WCH-Interrupt-fast` natively, so this firmware MUST be
 *   built with MRS + INT_SOFT=0. The Makefile defaults reflect this.
 *
 * CH592F dongle product entry point: clock init, optional UART1 debug, and
 * TMOS/HAL/RF init, plus -- under RF_WITH_USB (the default product build) --
 * the USB HID composite device and IAP reflash interface. Forwards decoded RF
 * HID reports to USB and dispatches host LED / IAP traffic from the main loop.
 * (Originally an OQ7 RF-only SRAM-dump port; the USB HID + IAP product path is
 * now wired here behind #if RF_WITH_USB.)
 */

/* CODEREVIEW N03: the Makefile's INT_SOFT guard checks only the make VARIABLE, so
 * EXTRA_CFLAGS=-DINT_SOFT=<anything> (even =0) slips past it while the SDK's
 * `#ifdef INT_SOFT` still selects the software-ISR ABI that wedges the CH59x BLE/RF
 * paths (proven: the negative build changed TMR0_IRQHandler/USB handler prologues).
 * Fail the build LOUDLY on ANY INT_SOFT definition. The shipping build leaves it
 * undefined, so this never fires there. */
#ifdef INT_SOFT
#error "INT_SOFT must be UNDEFINED for CH592F: the software-ISR ABI wedges LIBCH59xBLE.a; build with the pinned MounRiver WCH toolchain and the native WCH-Interrupt-fast attribute."
#endif

#include "CONFIG.h"
#include "HAL.h"
#include "CH59x_pwr.h"
#include "rf_task.h"
#include "hal_rf.h"
#include "version.h"
#include "dongle_chip.h"
#include "dongle_platform.h"
#include "usb_device.h"
#include "iap.h"
#include "pm_ch592.h"

/* Placed AFTER CONFIG.h on purpose: before that include neither the SDK default
 * (HAL_SLEEP FALSE) nor TRUE is visible, so a -DHAL_SLEEP=TRUE would preprocess
 * to 0 beside the #ifdef-style INT_SOFT guard above and slip past. HAL_SLEEP
 * would register CH59x_LowPower as the TMOS idleCB (tmos_proces_idle re-inits
 * the LLE/BB) and pull HAL_SleepInit into HAL_Init; the main-loop idle in
 * pm_ch592.c is the only idle this target has. */
#if defined(HAL_SLEEP) && HAL_SLEEP
#error "HAL_SLEEP must be FALSE on the CH592 dongle: the TMOS idleCB sleep is replaced by the pm_ch592.c main-loop idle"
#endif

/*
 * Production board has ONLY the 32 MHz HSE crystal -- no external 32.768 kHz.
 * The 32K low-speed domain must be the internal LSI; CLK_OSC32K==0 selects the
 * (dead) external-LSE branch in HAL_TimeInit, which would have nothing to drive
 * it on the production board. The Makefile pins CLK_OSC32K=1.
 */
#if (CLK_OSC32K == 0)
#error "CH592F dongle requires internal LSI (CLK_OSC32K != 0): production board has no 32.768 kHz crystal"
#endif

__attribute__((aligned(4))) uint32_t MEM_BUF[BLE_MEMHEAP_SIZE / 4];

#if (defined(BLE_MAC)) && (BLE_MAC == TRUE)
const uint8_t MacAddr[6] = {0x84, 0xC2, 0xE4, 0x03, 0x02, 0x02};
#endif


/* Forward an RF HID report to USB, routed by the on-air report tag
 * (all bench-captured 2026-06-13 from a production keyboard):
 *   0xA1 boot keyboard  -> EP1 (8-byte [mod][rsv][k0..k5])
 *   0xA3 consumer/media -> EP3 composite, report ID 1 + 16-bit usage LE
 *                          (vol-up = [E9 00])
 *   0xA8 mouse          -> EP2 (5-byte [btn][X][Y][wheel][pan], verbatim)
 * System-control would be a further tag (not yet captured) -> dropped.
 * Runs in the RF task/callback context — the USB_Send* calls are a few
 * register writes and own endpoint readiness (configured/suspended). */
DONGLE_HIGHCODE_RF_HOT
static void usb_hid_callback(uint8_t tag, const uint8_t *data, uint8_t len)
{
    if (tag == RF_PROTO_HID_TAG) {
        USB_SendKeyboard(data);        /* 8-byte boot-keyboard body */
        return;
    }
    if (tag == RF_PROTO_HID_TAG_CONSUMER && len >= 2u) {
        /* Composite consumer report: [report-id 1][usage LE16]. */
        uint8_t r[3] = { RF_PROTO_USB_REPORT_ID_CONSUMER, data[0], data[1] };
        USB_SendComposite(r, sizeof(r));
        return;
    }
    if (tag == RF_PROTO_HID_TAG_MOUSE && len >= 5u) {
        /* Mouse report (EP2): 5-byte [btn][X][Y][wheel][pan] forwards
         * verbatim — the on-air body matches the if1 report layout. */
        USB_SendMouse(data);
        return;
    }
    /* Other tags (system control) are not yet wired — drop. Adding one is a
     * capture of its on-air tag + a dispatch case here. */
    (void)data;
    (void)len;
}

/* Stock parity: relay the host LED to the keyboard ONCE per change (and once at
 * connect/reconnect, handled by the rf_task promote re-sync). No periodic
 * heartbeat, no fast-resync burst, no RTC-epoch timing -- matching the production
 * dongle, which relays on-change + on-connect only; the keyboard latches the LED.
 * RF_SetLEDState stores the state always and queues a single LEN-3 relay only when
 * connected. last_led=0xFF (impossible 3-bit value) forces the first iteration
 * after RF start to sync the current state (matches the CH570 main loop). */
#if DONGLE_PM_IDLE
/* File-scope so pm_idle_try's masked re-check can compare the live host LED
 * state against what was last relayed (a SET_REPORT that lands after this
 * poll must veto the sleep, not wait for the next heartbeat). */
volatile uint8_t dongle_usb_led_last = 0xFFu;
#endif

static __attribute__((noinline)) void poll_usb_led_state(void)
{
#if DONGLE_PM_IDLE
    uint8_t led = (uint8_t)(USB_GetLEDState() & 0x07u);

    if (led != dongle_usb_led_last) {
        dongle_usb_led_last = led;
        RF_SetLEDState(led);
    }
#else
    static uint8_t last_led = 0xFFu;
    uint8_t led = (uint8_t)(USB_GetLEDState() & 0x07u);

    if (led != last_led) {
        last_led = led;
        RF_SetLEDState(led);
    }
#endif
}

DONGLE_HIGHCODE_RF_HOT
__attribute__((noinline))
void Main_Circulation(void)
{
    while (1) {
#if DONGLE_PM_IDLE
        /* Clear the work latches for this iteration and keep the one post
         * that must survive the clear: a post made in the IRQ tail after the
         * previous iteration's idle decision. Rationale: pm_ch592.c. */
        uint8_t entry_work = pm_loop_top();
#endif
        TMOS_SystemProcess();
        /* Run any IAP command the USB ISR deferred (bond write, reboot
         * request) outside ISR context so it can't starve RF supervision. */
        USB_PollEP6();
        /* Drive a requested reboot into OpenBoot (0x85 EnterBootloader):
         * quiesce RF, drain the final EP6 reply, then reset. */
        IAP_Service();
        /* If a keypress arrived over RF while the host was suspended (and it
         * armed remote wakeup), drive the resume K-state here in foreground. */
        USB_ServiceRemoteWake();
        /* Forward host HID LED changes from foreground, outside the highcode loop
         * body so USB LED plumbing does not consume timing-critical SRAM. */
        poll_usb_led_state();
#if DONGLE_PM_IDLE
        /* Idle the core until the next interrupt if, and only if, this
         * iteration left nothing queued and the RF/USB state admits it
         * (pm_ch592.c carries the veto list and the SEVONPEND-WFE sequence). */
        pm_idle_try(entry_work);
#endif
    }
}

int main(void)
{
    /* Capture reset status before clock/BLE bring-up can perturb it. */
    uint8_t reset_status = R8_RESET_STATUS;

    dongle_fault_boot(reset_status);
    SetSysClock(CLK_SOURCE_PLL_60MHz);
#if DONGLE_PM_IDLE
    /* Page 6 [43]: PB15 pulls/DIR and CFG_DEBUG_EN as ROM/OpenBoot left them,
     * before any pin is touched, so the byte is valid with the park on or off. */
    pm_boot_snapshot();
#endif
#if DONGLE_PM_GPIO_PARK
    /* Before any peripheral claims a pin (OpenController precedent): the
     * CH592D no-connects become pulled-up inputs, PB15 (the ISP strap, GND on
     * the production PCB) a pull-DOWN, the CH592D-unbonded pads "only analog
     * input". PB10/PB11 (USB) are never touched. */
    pm_gpio_park();
#endif

#if DONGLE_PM_IDLE
    /* Defence in depth for non-OpenBoot entry paths (ROM ISP, SWD-halt
     * resume): the idle wakes on pending-but-disabled interrupts (SEVONPEND),
     * and a SysTick left pending would be a permanent alien veto. The pinned
     * OpenBoot already hands over a stopped, cleared, zeroed SysTick. */
    SysTick->CTLR = 0;
    SysTick->SR = 0;
    PFIC_ClearPendingIRQ(SysTick_IRQn);
#endif
    CH59x_BLEInit();
    HAL_Init();
#if DONGLE_PM_CLK_GATE
    /* Unconditional clock gates for the blocks nothing linked here touches
     * (TMR1/2, UART0-3, SPI0, PWMX, I2C, LCD); never TMR0 (RF pacer), TMR3
     * (heartbeat), USB or BLE. After HAL_Init, before the radio comes up. */
    pm_clock_gate();
#endif
    hal_rf_init();   /* P2.4: RF_RoleInit via the RF PHY seam */

    /* CH59x BLE library does NOT enable BLEB/BLEL IRQ lines for raw
     * RF_Rx/RF_Tx mode (only for connection-mode via BLE_LibInit's
     * internal paths). Without these explicit enables, RF_Rx returns
     * success but no callbacks ever fire. Proven 2026-05-17 in
     * ch592f-irq-test/wch-rfphy-rebuild: enabling them turned 0
     * callbacks into 2 valid RX_MODE_RX_DATA receives on BLE ADV
     * ch37 in 8 s. */
    PFIC_EnableIRQ(BLEB_IRQn);
    PFIC_EnableIRQ(BLEL_IRQn);

    /* Do NOT call PFIC_EnableAllIRQ() here. On CH59x it writes CSR 0x800 = 0x88,
     * overwriting the QingKe interrupt-system-control config that CH59x_BLEInit
     * set up for the BLE/RF library's nested LLE/BB ISRs. Overwriting it delays
     * the timing-critical EV10 supervision and the keyboard drops at ~6 s with
     * USB active. Global IRQ dispatch is already on (the RF-only build's BLEB/
     * BLEL ISRs fire without this call), and USB_DevInit enables USB_IRQn
     * itself, so USB enumerates without disturbing the BLE interrupt config. */

    /* USB HID composite device (5 interfaces; the native USB_IRQHandler in
     * usb_device.c overrides the weak vector in startup_CH592_phased.S). */
    USB_DevInit();
#if DONGLE_PM_USB_DIGIN_OFF
    pm_usb_digin_off();   /* PB10/PB11 digital input buffers off; PHY untouched */
#endif
    /* Route EP6 OUT (interface 4) into the IAP dispatcher so the dongle stays
     * in-field reflashable via flash_dongle.py / the stock Windows tool. */
    USB_SetEP6OutCallback(IAP_PacketHandler);

#if DONGLE_PM_IDLE
    /* The TMR3 heartbeat starts before RF_TaskInit so every TMOS deadline is
     * bounded from the first RF event onward. */
    pm_heartbeat_init();
#endif
    /* 2.4G RF receiver. */
    RF_TaskInit();
    RF_SetHIDCallback(usb_hid_callback);    /* forward keyboard reports to USB */

    Main_Circulation();
}

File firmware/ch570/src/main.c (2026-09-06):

/*
 * OpenKeyboard.org OpenDongle
 * Copyright 2026 Eric Molitor (EMulator)
 * SPDX-License-Identifier: Apache-2.0
 * CH570D MVP port.
 */

/* CODEREVIEW N03: the Makefile's INT_SOFT guard checks only the make VARIABLE, so
 * EXTRA_CFLAGS=-DINT_SOFT=<anything> slips past it while the SDK's `#ifdef INT_SOFT`
 * still selects the software-ISR ABI (CH570 uses HPE/hardware stacking + live
 * __INTERRUPT handlers, same concern as CH59x). Fail the build LOUDLY on ANY
 * INT_SOFT definition (the shipping build leaves it undefined). */
#ifdef INT_SOFT
#error "INT_SOFT must be UNDEFINED for CH570: the software-ISR ABI breaks the WCH hardware-stacking interrupt path; build with the pinned MounRiver WCH toolchain and INT_SOFT off."
#endif

#include "CH57x_common.h"
#include "version.h"
#include "dongle_platform.h"
#include "sched.h"
#include "hal_timing.h"     /* hal_timing_diag_snapshot (IAP 0x92) */

#include "iap.h"
#include "usb_device.h"

#include "rf_task.h"
#include "hal_rf.h"

extern volatile uint8_t ch570_boot_reset_status;

/*
 * Default clock is 100 MHz: the CH570/CH572 parts are specified for it and WCH's
 * USB+RF examples run SetSysClock(CLK_SOURCE_HSE_PLL_100MHz). All RF timing is
 * expressed in CH570_SYSCLK_HZ Tsys units. 100 MHz is the only supported clock
 * (a build-time static assert below rejects anything else).
 */
#ifndef CH570_SYSCLK_SOURCE
#define CH570_SYSCLK_SOURCE CLK_SOURCE_HSE_PLL_100MHz
#endif

#ifndef CH570_SYSCLK_HZ
#define CH570_SYSCLK_HZ 100000000u
#endif

/*
 * Production board has ONLY the 32 MHz HSE crystal -- no external 32.768 kHz
 * low-speed crystal -- and is always bus-powered over USB. CH570_LSI_INTERNAL
 * explicitly sources the 32K low-speed domain from the internal LSI RC so the
 * firmware can never depend on an absent external crystal. CH570_DONGLE_NEVER_SLEEP
 * documents and guards the no-sleep policy: the CPU busy-polls and never enters
 * idle/deep-sleep. Both are on by default; USB and RF run off HSE/PLL and are
 * unaffected by the low-speed domain.
 */


/* The CH570 supports EXACTLY ONE clock: 100 MHz. */
_Static_assert(CH570_SYSCLK_SOURCE == CLK_SOURCE_HSE_PLL_100MHz,
               "CH570 only supports the 100 MHz PLL profile");
_Static_assert(CH570_SYSCLK_HZ == 100000000u,
               "CH570 only supports CH570_SYSCLK_HZ=100000000u");

/*
 * RB_PWR_EXTEND is a deep-sleep power-retention plan; it only does anything if
 * the part actually sleeps. Enabling it while claiming never-sleep is a
 * contradiction -- catch it at build time.
 */

static void usb_start(void)
{
    USB_DevInit();
    USB_SetEP6OutCallback(IAP_PacketHandler);
}

static uint8_t rf_started;

/* Deferred HID->USB forward (2026-07-08). The RF callback (radio-IRQ
 * context on CH570 — the shared sink runs in the true LLE/BB IRQ, unlike
 * the CH59x whose BLE-lib callbacks are IRQ-tail deferred) only LATCHES the
 * report here; the MAIN LOOP performs the USB arm in task context
 * (usb_hid_forward_pump). This matches the CH59x's effective dispatch
 * context and is the shape that was host-validated end to end (synthetic
 * radio-IRQ-origin reports: 171/172 delivered to the host hidraw; main-loop
 * EP1 arms measured 16/16). Direct-from-IRQ arming was the legacy v0.83
 * shape but has not been re-validated on the unified body, and USB_Send*
 * from the ~875 µs radio IRQ would also stretch the RF deadline — so the
 * deferral is both the validated and the conservative choice. Single-slot
 * newest-wins is correct for HID: last-state-wins is the USB interrupt-IN
 * model anyway (the old direct arm overwrote the EP buffer just the same),
 * and the main loop passes every few µs — far faster than the RF poll
 * cadence that spaces reports. */
static volatile uint8_t hid_fwd_pending;
static uint8_t hid_fwd_tag;
static uint8_t hid_fwd_len;
static uint8_t hid_fwd_body[8];

static void usb_hid_callback(uint8_t tag, const uint8_t *data, uint8_t len)
{
    uint8_t n = (len < 8u) ? len : 8u;

    for (uint8_t i = 0u; i < n; i++) {
        hid_fwd_body[i] = data[i];
    }
    hid_fwd_tag = tag;
    hid_fwd_len = n;
    hid_fwd_pending = 1u;   /* written last; the pump snapshots under mask */
}

/* Main-loop half: route the latched report to USB by on-air tag (parity with
 * CH592): 0xA1 boot keyboard -> EP1 (8-byte, zero-padded/clamped),
 * 0xA3 consumer/media -> EP3 composite (report id 1 + usage LE16),
 * 0xA8 mouse -> EP2 (5-byte verbatim). The USB_Send* helpers own endpoint
 * readiness (configured/suspended/remote-wake stash). */
static void usb_hid_forward_pump(void)
{
    uint8_t tag, len;
    uint8_t body[8];

    if (!hid_fwd_pending) {
        return;
    }
    {
        uint32_t irq = __risc_v_disable_irq();
        tag = hid_fwd_tag;
        len = hid_fwd_len;
        for (uint8_t i = 0u; i < 8u; i++) {
            body[i] = hid_fwd_body[i];
        }
        hid_fwd_pending = 0u;
        (void)__risc_v_enable_irq(irq);
    }
    if (!USB_IsConfigured()) {
        return;
    }
    if (tag == RF_PROTO_HID_TAG) {
        uint8_t report[8] = {0};
        for (uint8_t i = 0u; i < len; i++) {
            report[i] = body[i];
        }
        USB_SendKeyboard(report);
    } else if (tag == RF_PROTO_HID_TAG_CONSUMER && len >= 2u) {
        uint8_t r[3] = { RF_PROTO_USB_REPORT_ID_CONSUMER, body[0], body[1] };
        USB_SendComposite(r, sizeof(r));
    } else if (tag == RF_PROTO_HID_TAG_MOUSE && len >= 5u) {
        USB_SendMouse(body);
    }
}

static void rf_start(void)
{
    hal_rf_init();   /* the shared body expects the radio brought up by main
                      * (the CH592 pattern) */
    RF_TaskInit();
    /* MUST come AFTER RF_TaskInit: the shared init clears rf_hid_callback as
     * part of its state reset (rf_task.c RF_TaskInit), so registering first
     * leaves the callback NULL and every received HID report is silently
     * dropped before USB. That exact ordering bug shipped in the v0.96
     * unification and made the CH570 receive-but-never-forward (bond/hid
     * tallies climbing, zero host reports) — root-caused on the bench
     * 2026-07-08. The CH592 main has always registered after RF_TaskInit. */
    RF_SetHIDCallback(usb_hid_callback);
    rf_started = 1u;
}
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

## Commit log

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2026-08-02 firmware: bond store, image identity, and IAP
    The persistent pairing record and its non-volatile store, the ODG2 identity
    header instance the build stamps, and the vendor HID command surface:
    device/firmware/status/fault readout, bond operations, and the
    reboot-into-bootloader request that hands the device to OpenBoot for an
    update. The reboot path quiesces the radio and drains the reply before
    resetting, with wall-clock deadlines so a wedged executor or a detached host
    cannot block it forever.
    [iap.c]
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2026-08-02 ch592: build, link script, and target sources
    The CH592F port: clock and power bring-up, the BLE-library radio backend and
    its timing shim, the USB backend, the platform layer (non-volatile bond
    storage in DataFlash, retained fault record, reset ownership), the phased
    startup and fault handlers, and the linker script that places the
    application at 0x2000 under OpenBoot and reserves the top of RAM for the
    bootloader's boot-request word.
    BLE SNV is compiled out deliberately: its default store is the same
    DataFlash block the OpenBoot boot record uses, and the vendor library would
    rewrite it on any boot it did not recognise.
    The top-level make gains the CH592 targets; the CH570 port follows in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
    [hal_rf_ch592.c, hal_timing_ch592.c, hal_usb_ch592.c]
2026-08-02 ch570: build, link script, and target sources
    The CH570D port: 100 MHz clock bring-up, the RFIP radio backend and its
    polled dispatch/timing seams, the USB backend, the platform layer (bond in
    code flash, retained fault record, reset ownership), the reset and fault
    handlers, and the linker script.
    The application window ends at 0x3A000, below the bond page and the OpenBoot
    boot record page, and the OpenBoot board file clamps its app region to the
    same bound - so neither page is reachable over the update protocol. Note the
    CH570's debug pins are its USB pins: a USB-attached device has no SWD.
    [hal_dispatch_ch570.c, hal_rf_ch570.c, hal_timing_ch570.c]
2026-08-02 tools: add the OpenDongle host CLI
    Cross-platform USB-HID maintenance tool: device, firmware, status, bond and
    fault readout, and the guarded handoff into the OpenBoot bootloader for
    updates. It does not flash firmware itself - that happens in the bootloader
    over OBP.
    --enter-bootloader --image is the safety interlock: the image's ODG2 family
    is checked against the connected device before the reboot, while the
    application is still the thing answering, so a CH570 image cannot be sent
    toward a CH592 or vice versa. Factory images are refused with a pointed
    error; they are written at address 0 with a debug probe.
    [main.rs]
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2026-08-03 fix: make the CH570 LSI jitter timeouts wall-clock, not instruction counts
    ch570_mix_jitter_entropy() bounded both of its LSI edge waits with
    `spin < 400000u`. That is an instruction budget wearing the costume of a
    time budget: how long it actually waits depends on how fast the loop
    happens to execute, so it moves with code placement, compiler output, and
    - the reason this was found - with CORECFGR bit 3, which enables a
    128-byte ROM loop buffer that a loop this small is eligible for.
    Measured on CH570 silicon, forcing the timeout path:
    CORECFGR old (spin < 400000) new (SysTick 50 ms)
    0x25 696 ms 50.0 ms
    0x2D 32 ms 5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
    [platform_ch570.c]
2026-08-03 build: move the application toolchain pin to MounRiver GCC 15.2
    Bumps the pinned application compiler from MounRiver GCC 12.2 to GCC 15.2
    and moves the tool prefix with it: GCC 12 shipped riscv-wch-elf-*, GCC 15
    ships riscv32-wch-elf-*. The prefix now lives in one variable, CROSS, in
    each application Makefile.
    OpenBoot is deliberately NOT moved. It is a pinned submodule with its own
    toolchain pin, still on GCC 12. The factory image is
    OpenBoot || pad || application - two separately linked binaries that share
    no code - so the two halves may be built by different compilers safely.
    OPENBOOT_TOOLCHAIN defaults to MRS_TOOLCHAIN, so leaving it unset fails
    loudly in OpenBoot's own checker rather t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
    [check_dependencies.py]
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2026-08-04 build: make the GCC 15.2 quick-start actually work, and address review
    Follow-up to the toolchain pin move, fixing the review feedback on #9.
    The headline defect: the README's primary setup command could not succeed on a
    fresh clone. The default goal composes the factory image, which builds OpenBoot
    -- and OpenBoot is a pinned submodule still on GCC 12, whose own checker pins
    the riscv-wch-elf-* names. `OPENBOOT_TOOLCHAIN` defaults to `MRS_TOOLCHAIN`, so
    it inherited GCC 15 and failed. Only the buried example further down worked.
    The quick-start now names both toolchains and says why.
    Same root cause, second entry point, which no reviewer caught: the top-level
    ch570-openboot / ch592-openbo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
    [check_dependencies.py, main.c]
2026-08-04 feat: AES-128 HAL seam with software backend for CH570
    CH570 has no hardware AES engine. This is measured, not assumed: the
    address space at 0x4000C300 that carries a working engine on CH592 and
    CH572 is not decoded on CH570 -- writes to the plain key/data registers
    do not latch and every word reads zero, in every state tested (reset,
    radio brought up, AES_CCM clock explicitly enabled, LLE CTRL_MOD bit 7
    set), while neighbouring registers in the same cluster are live and
    writable. A CH572 on the same bench -- same family, very likely the same
    lot, reporting the identical CTRL_MOD value in the same reset state --
    passes the full known-answer battery from a cold reset with the program
    counter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
    [hal_aes_ch570.c, hal_aes_ch592.c]
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2026-08-04 EXPERIMENT: measure CORECFGR bit 3 (ROM_LOOP_ACC) enabled
    Not for merge as-is. Flips CH570_CORECFGR_VALUE to 0x2D to measure what the ROM
    loop buffer buys, on all arms, on real silicon. Every arm still folds to
    b106130c, so correctness is unaffected either way.
    block key schedule
    arm 0x25 -> 0x2D 0x25 -> 0x2D %slot (key)
    asm-a 1,944 1,672 59,113 8,901 67.6% -> 10.2%
    asm-f n/m 3,992 n/m 9,429 10.8%
    c 43,396 30,721 45,378 17,534 51.9% -> 20.0%
    ch572-hw 4,011 2,966 5,126 1,707 5.9% -> 2.0%
    The headline is the key schedule, not the block. ASM_A's schedule goes from
    consuming two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
    [aes_validate.c]
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2026-08-05 rf: do not toggle CORECFGR around vendor RF init -- measured, it breaks pairing
    A/B on the bench, same day, byte-exact control image, CH570 at CORECFGR 0x2D:
    unguarded 0x2D: pairing 2/2 -- bond written (BOND + keyboard MAC at
    0x3A000), HID reports flow end to end
    guarded 0x2D: pairing 0/2 -- bond page still blank, so the failure is at
    the RF level, not HID forwarding
    The guard was the WIP write-only suspend of ROM_LOOP_ACC across
    RFRole_BasicInit, meant to protect the ~99 us calibration settle in
    RFEND_DevInit from collapsing to ~3.3 us. The result is backwards from that
    theory: the production-length settle FAILED and the collapsed settle WORKS.
    Th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
    [hal_rf_ch570.c]
2026-08-05 docs: CORECFGR 0x2D is production -- publish the measured costs everywhere
    The 0x25 -> 0x2D flip itself is one line and was committed with the
    measurements; this aligns every document that still described 0x25 as
    production. All figures are from firmware/validation sweeps that reproduce to
    the cycle (key schedules within +/-2), and the V3C rows measure identically on
    CH570 and CH572 silicon.
    backend block %slot key sched %slot (was, at 0x25)
    ASM_A 1,672 1.9% 8,899 10.2% 1,944 / 59,113
    ASM_F 3,992 4.6% 9,429 10.8% unbuildable
    C 30,721 35% 17,535 20.0% 43,396 / 45,378
    CH572 engine 2,966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
    [hal_aes_ch570.c]
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2026-08-05 validation: stamp snapshots with a per-run nonce -- executions, not builds
    Third review round on #11. The three re-posted inline comments are stale
    re-anchors of findings already fixed; the one live finding is CodeRabbit's
    outside-diff Major, and it is a fair rebuttal of the previous round's
    resolution: retained RAM survives power cycles and reflashing on this silicon,
    and the build id only distinguishes BUILDS -- so with no boot baseline, a
    snapshot from an earlier execution of the same build passed every remaining
    check, and a failed re-run could report the previous run's PASS.
    Its suggested "invalidate the snapshot before each run" is the right intent,
    and the obvious transport for it do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
    [aes_validate.c]
2026-08-05 validation: resolve the key-schedule "anomaly" -- it was memcpy, flash, and us
    The hardware arms reported a key-schedule cost far above what caching four
    words can take (CH572 5,126 at 0x25 / 1,707 at 0x2D; CH592 1,359), with a
    CH572/CH592 ratio that ignored the clock ratio. Investigated to closure on
    silicon; three stacked causes, none of them the driver's logic or the engine:
    1. GCC 15.2 -O2 compiles the driver's "cache four words" loop into a tail
    call to newlib-nano's memcpy -- a one-byte-per-iteration loop, ~110
    flash-resident instructions per call. The source-level "few stores"
    comment was false for the artifact.
    2. The measured key was the flash-resident KAT consta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
    [aes_validate.c, hal_aes_ch592.c]
2026-08-05 validation: address PR review -- one canonical measurement set, aliasing fix
    All four findings on #14 were valid, including the one I had noticed and
    excused: the README table, hal_aes.h and hal_aes_ch570_impl.h cited three
    different measurement vintages (ASM_F 3,960 vs 3,992, C 30,694 vs 30,721,
    engines 2,967/871 vs 2,966/865) while the docs claim cycle-level
    reproducibility. Both reviewers refused the two-significant-figures excuse,
    correctly. Everything current now cites the SRAM-key sweep -- blocks 1,672 /
    3,960 / 30,694 / 2,967 / 871, key schedules 7,647 / 7,405 / 16,543 / 322 /
    838 -- and explicitly historical figures (the 0x25->0x2D flip record) are
    labelled with the semantics they we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
    [aes_validate.c]
2026-08-05 validation: finish the probe tag-range fix, band the historical ASM_F figure
    Follow-up to #14. Re-reviewing the merged result against the review comments
    rather than assuming they were stale re-anchors: one of them was not.
    - The probe's tag-range comment still said "tags 3..7". The previous commit
    added a correct "(tags 3..9)" on the next line without removing the wrong
    one, leaving two contradictory statements one line apart -- worse than the
    original defect. Now a single correct statement. (CodeRabbit, valid twice.)
    - The README's 0x25->0x2D flip record cited ASM_F as a bare 3,992 where
    hal_aes_ch570_impl.h had already been given the 3,960-3,992 layout band.
    Same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
    [aes_validate.c]
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2026-08-05 tools: find the bootloader by HID usage, not by 1209:0001
    OpenBoot's upcoming pin gives the bootloader the application's own USB
    identity (OB_USB_VID/OB_USB_PID = 0C45:FEFE in the opendongle board
    files), so a user sees one device that changes mode rather than two
    unrelated ones. That breaks openboot_present(), which tested for
    1209:0001 and would now never fire: --enter-bootloader would reboot the
    dongle successfully and then report "no OpenBoot bootloader appeared
    within 10 s" and exit 2.
    Swapping the constants is not the fix. The application enumerates under
    that same VID:PID, so a bare VID:PID test would answer "already in the
    bootloader" whenever the app is merely running. The discrimi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
    [main.rs]
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2026-08-06 firmware: fix the clean-checkout build failure in openboot_geometry.py
    The script asked make for the generated config header by ABSOLUTE path.
    OpenBoot declares that target relatively - `$(CONFIG_H): FORCE` where
    CONFIG_H is `$(BUILD)/openboot_config.h` - so on a fresh clone make
    answers "No rule to make target" and both chip Makefiles die at PARSE
    time, before compiling anything.
    A developer tree hides this completely: once the header exists, make
    treats the absolute path as an already-satisfied file and exits 0 without
    needing a rule. So every build here passed while a clean clone was
    broken. Found by a pre-PR review pass; reproduced by deleting the
    generated build directory.
    Fixed by re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
    [openboot_geometry.py]
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2026-08-06 docs: fix a wrong path and reconcile the bench wrapper's W numbering
    Both from Copilot on PR #16; both valid.
    tools/src/main.rs cited common/src/usb_descriptors.c, which resolves
    neither from the repo root nor relative to tools/. The file is
    firmware/common/src/usb_descriptors.c. The substantive claim the comment
    guards is sound - :83 declares usage page 0xFFFF and :88/:93 declare
    0xFF60, and no application collection declares 0xFF00, so
    has_bootloader_usage() cannot false-positive on the running app.
    The bench wrapper's rationale block documented W1-W6 while the code used
    W7 and W9, W8 had never existed, and the dry-run patch carried no number
    at all. That last one was added by the pre-PR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
    [main.rs]
2026-08-07 Address CodeRabbit's review of PR #16
    CodeRabbit reviewed after the usage quota reset (its first attempt posted
    only a spending-cap notice, no findings). Five actionable items, all real.
    MAJOR - the next-step hints printed `openboot flash --force <app.bin>`
    with no --vid/--pid. openboot defaults to its generic 1209:0001, which is
    not this product, so every command the tool suggested would fail to find
    the device. Doubly awkward given tools/README.md explains that those
    flags are required. All three messages now carry them from cli.vid/pid.
    MAJOR - --enter-bootloader could report success against the wrong unit.
    It accepted "a bootloader is present" without requiring the application
    interfac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
    [main.rs]
2026-08-07 tools: identify the bootloader that actually arrived, and stop overclaiming
    CodeRabbit followed up on the previous round's fix and was right on both
    counts: the check was incomplete, and - worse - the README described a
    guarantee it did not provide.
    The previous fix required the addressed application interface to leave
    AND a bootloader to be present. That still passes in the case it was
    supposed to stop: if unit B is ALREADY in OpenBoot and unit A then
    reboots, A's application does leave, a bootloader is present, and the
    tool reports success without ever establishing which device the following
    flash would reach.
    Now the bootloaders present BEFORE the reboot are recorded, and success
    requir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
    [main.rs]
2026-08-07 tools: fail fast on an ambiguous handoff, and correct the risk claim
    Two findings on PR #16. One is right for a reason other than the one
    given; the other is a plain documentation gap.
    The claim was that with another bootloader present, the printed flash
    command "can then flash either bootloader". That is not so, and my own
    README said something equally wrong in the opposite direction. openboot
    narrows candidates by HID usage page BEFORE counting, so a sibling
    running its application is filtered out and the right device is selected;
    and when more than one BOOTLOADER interface matches it bails outright
    ("Ambiguity is an error whether or not a serial was given"). The flash
    cannot be misdirect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
    [main.rs]
2026-08-07 tools: fail closed on unidentifiable HID usages, bind tracking to the opened device
    Five findings from CodeRabbit's latest pass on PR #16 (one inline, four
    outside the diff range). All real.
    FAIL CLOSED (major). has_bootloader_usage accepted 0/0 - "the backend
    could not parse the report descriptor" - when nothing reported a real
    usage. On this product that is indistinguishable from wrong: the
    application shares the bootloader's VID:PID, so a set of application
    interfaces all reporting 0/0 was classified as OpenBoot, and the caller
    acts on that by rebooting or flashing. Only the declared vendor usage
    counts now. On a platform that does not report HID usages the tool says
    it cannot identify t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
    [main.rs]
2026-08-07 firmware: build the application for both A/B slots (Phase 2, step 1)
    OpenBoot alternates its write target after every COMMIT, so a release
    needs an image for each slot: an update is refused outright unless the
    image's base equals the device's current write_base. This makes both
    buildable.
    The slot base reaches the COMPILER, not just the linker - openboot_app.c
    derives its record address from it and dongle_id.c stamps it into the
    ODG2 header - so the two slots get separate object trees
    (build/<profile>-slot{A,B}) rather than one set linked twice.
    link.ld no longer contains any address. Its MEMORY block is generated per
    slot into $(BUILD)/memory.ld and pulled in with INCLUDE, the same patter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
    [openboot_geometry.py]
2026-08-07 firmware: slot-aware image validation and .obb bundles (Phase 2, step 2)
    Two pieces on top of the dual-slot builds.
    VALIDATION. dongle_image_id.validate_app_image_identity compared both the
    load base and the ODG2 header base against one constant, APP_BASE. Under
    A/B that is wrong twice: it rejects a legitimate slot-B image, and -
    more subtly - it cannot see a header that claims slot A on an image
    linked for slot B, because comparing both to the same constant collapses
    two different questions into one. They are now asked separately: the load
    base must be one of the chip's slot bases (passed in via valid_bases),
    and the header must agree with the load base.
    The default stays slot-A-only rath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
    [dongle_image_id.py]
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2026-08-07 rf: correct the knob's usage examples
    From review: the CH570 Makefile's example said `make ch592`, because I
    copy-pasted the knob comment between the two chip Makefiles without
    changing the target. Each now names its own, and the same paste had
    reached two more places - rf_task.c, which is SHARED between both chips
    and so should not name either without saying so, and RELEASE-NOTES.
    Two further corrections while there. The examples omitted `-C firmware`,
    so they were not runnable as written from the repo root. And the comment
    warned that "negative values need care, so quote it" next to an unquoted
    example - the advice was speculative and wrong: `PAIR_MIN_RSSI=-95` is an
    ordinary command-line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
    [rf_task.c]
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2026-08-09 rf: gate the CH570 bond persist on a confirmed peer RX (Issue #23)
    CH570 promoted to CONNECTED and durably persisted the bond on its own pair-ACK
    TX-finish alone, with no confirmed RX from the keyboard. A pairing that silently
    failed on the keyboard side therefore minted a durable, self-reproducing dead
    bond that survived reboots and power-cycles until a fresh re-pair (both sides
    CONNECTED, zero HID).
    CH592 already avoids this with a confirm-before-persist gate (a fresh pair
    RAM-commits but defers the DataFlash write until a connected RX confirms the
    peer), but that machinery was compiled out on CH570 (#if RF_TASK_EXECUTOR_TMOS).
    Decouple the feature from the executor: add RF_CONFIRM_BEFOR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
    [rf_task.c]
2026-08-09 Address CodeRabbit and Copilot review
    - rf_commit_bond_ram: on the AA-divergence guard, zero rf_bond_pending_rec and
    clear rf_bond_valid before returning. The bare early return left the previous
    pending snapshot intact, so a later confirm -> rf_arm_bond_persist could still
    write a stale/wrong-AA record. Now a divergence commits and persists nothing
    (the readback semantic check also rejects the resulting zero-AA record).
    - POST_POLL_RX stale-event guard: widen #if RF_TASK_EXECUTOR_TMOS ->
    #if RF_CONFIRM_BEFORE_PERSIST. CH570 now runs the confirm-timeout -> pairing
    fallback, so it needs the same guard preventing a co-dispatched POST_POLL_RX
    from re-priming connected RX over the f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
    [rf_task.c]
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2026-09-04 tools: decode the whole fault page and bond record; add unarmed --fault/--status/--diag and armed --rf-poke
    Host-side half of the bonded-reconnect investigation (the firmware
    diagnostics it reads live in a separate draft PR; the step-by-step history
    and codex review trail are on fix/bond-reconnect-diag-full).
    The two USB readouts that matter for a stuck-reconnect investigation already
    existed (IAP 0x93 FaultRead, 0x88 BondRead) but the tool threw most of their
    content away: fault.rs decoded the startup-captured reset byte and never the
    record's own, skipped the startup phase marker, the live reset keeper and
    every counter on a healthy record, and printed no raw bytes; bond.rs skipped
    dongle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
    [main.rs]
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2026-09-04 review: restore the suspend-defect heading in TODO, reject --samples 0, document --rf-poke's contract, doc comments
    - TODO.md: my correction to the 26-bit entry had swallowed the next section's
    heading ("suspend NAKs only EP1 ...") and left `*Where:**` malformed
    (Copilot, CodeRabbit). Heading and label restored.
    - --samples now requires >= 1 (clap range); `--samples 0` used to open the
    device and exit silently (CodeRabbit).
    - README: --rf-poke's contract -- arms a session, rungs 1/2, refused outside
    the exact terminal camp and while quiescing, unsupported on CH592, needs the
    draft-PR firmware (CodeRabbit).
    - Doc comments on the tool helpers CodeRabbit's docstring check flagged.
    [main.rs]
2026-09-06 build: gate the compiler on properties, not on the driver's bytes
    check_dependencies.py no longer refuses a build unless the riscv32-wch-elf-gcc
    driver matches one SHA-256. It now requires the GCC major (15 for the app,
    --compiler-major to override, read from -dumpfullversion/-dumpversion rather
    than parsed out of the banner) and, the property the firmware actually
    depends on, that the driver IMPLEMENTS
    __attribute__((interrupt("WCH-Interrupt-fast"))): the probe compiles a
    handler for the chip's own -march/-mabi (--probe-flags from each Makefile)
    and inspects the generated code, since accepting the spelling is not enough.
    A WCH fast handler lets the hardware preserve ra/t0/a0 and spills only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
    [check_dependencies.py]
2026-09-06 review: fail cleanly on an unreadable driver, normalise the strict digest, delegate top-level check-deps, README wording
    Addresses the PR #34 review comments:
    - check_dependencies.py: hashing the compiler driver now reports an
    unreadable file as a dependency-check failure instead of an unhandled
    OSError traceback. --expect-compiler-sha256 is stripped, lower-cased and
    must be exactly 64 hex digits. Docstrings on the remaining functions.
    - firmware/Makefile: the top-level check-deps delegates to the chip
    Makefiles, so the fast-interrupt probe runs with each chip's own $(ARCH)
    exactly as a build of that chip would, rather than the script's generic
    rv32imac default.
    - README: say wh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
    [check_dependencies.py]
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2026-09-06 rf: read-only IAP 0x92 RF diagnostics pages and an armed 0x94 intervention ladder (CH570-instrumented)
    Squash of the diagnostics work from the bonded-reconnect investigation
    (branch fix/bond-reconnect-diag-full keeps the step-by-step history and the
    codex review trail). Split out of PR #32 so the tool and docs can merge
    without touching firmware bytes; this part rides the next hardware-matrix
    and digest re-pin cycle (PR #27's).
    Why it exists: a bonded CH570 dongle that stopped answering its keyboard
    reported only `waiting for reconnect` with a valid bond, and on CH570 the
    debug pins are the USB pins, so nothing could say whether the radio was
    deaf, rejecting, mistimed or on the wrong addres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
    [hal_dispatch_ch570.c, hal_rf_ch570.c, hal_rf_ch592.c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]
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
